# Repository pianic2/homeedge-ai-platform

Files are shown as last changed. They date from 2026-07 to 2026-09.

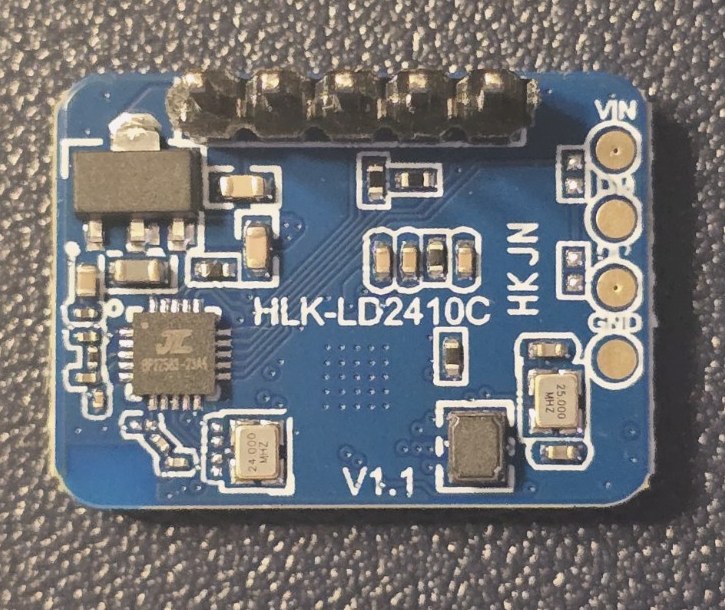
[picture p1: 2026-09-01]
docs/evidence/IHAP-46/ld2410c-v1-1-component-side.jpg

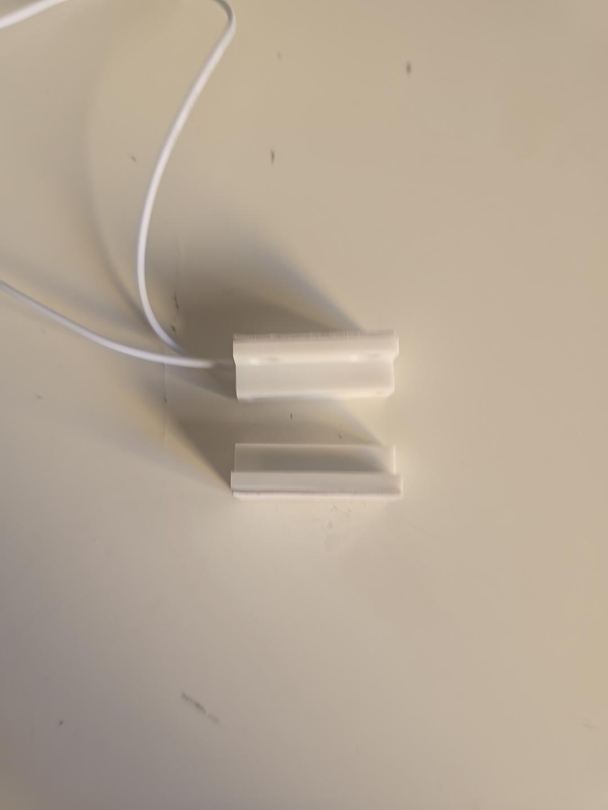
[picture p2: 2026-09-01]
docs/evidence/IHAP-47/IHAP47-MC38-A-01/photo-overview.jpg

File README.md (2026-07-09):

# HomeEdge AI Platform

**Educational edge-first smart home platform built around an ESP32-C3 MVP node, target backend service boundaries, mobile monitoring direction, and source-of-truth governance.**

HomeEdge is a portfolio and ITS project focused on building a smart home platform in a controlled, reviewable, and anti-regression way.

At Sprint 0, the repository prioritizes explicit boundaries over premature runtime claims. Directories may describe target architecture, not necessarily implemented production services.

<!--
AI_AGENT_METADATA:
  project: "[ITS] [EDGE] HomeEdge AI Platform"
  jira_project_key: "IHAP"
  repository: "pianic2/homeedge-ai-platform"
  document_role: "root_semantic_index"
  source_of_truth_policy: "docs/governance/source-of-truth.md"
  shift_left_governance_baseline: "docs/governance/shift-left-governance-baseline.md"
  scrum_governance_dor_dod: "docs/governance/scrum-governance-dor-dod.md"
  ai_review_agents_policy: "docs/governance/ai-review-agents-policy.md"
  ai_review_agent_playbook: "docs/governance/ai-review-agent-playbook.md"
  governance_lane_review_gate: "docs/governance/governance-lane-review-gate.md"
  team_working_rules: "docs/governance/team-working-rules.md"
  engineering_assistant_rules: "docs/governance/engineering-assistant-rules.md"
  documentation_strategy: "docs/governance/documentation-strategy.md"
  docs_landing_page: "docs/README.md"
  templates_index: "docs/templates/README.md"
  risk_assessment_template: "docs/templates/risk-assessment.md"
  risk_index: "docs/risks/README.md"
  risk_model_baseline: "docs/risks/risk-model-baseline.md"
  risk_records_path: "docs/risks/records/"
  adr_index: "docs/adr/README.md"
  adr_template: "docs/adr/template.md"
  product_vision: "docs/product/product-vision.md"
  stakeholder_transparency: "docs/governance/stakeholder-transparency.md"
  stakeholder_report_data_rules: "docs/governance/stakeholder-report-data-rules.md"
  current_glossary_location: "docs/product/product-vision.md"
  standalone_glossary_status: "future_candidate_not_created_by_ihap_13"
  stakeholder_hub: "https://niccolopiazzi01.atlassian.net/wiki/spaces/IEHAP/overview"
  stakeholder_reports_authoritative_surface: "Confluence"
  source_of_truth_roles:
    github: "technical truth, code, versioned docs, decisions, risks, policies, baselines, PR evidence"
    jira: "backlog, workflow state, task status, review state, blockers, evidence links"
    confluence: "stakeholder hub, stakeholder reports, stakeholder forms, navigation"
  mvp_firmware_node: "firmware/room-env-node/"
  mvp_node_semantics: "generic_room_door_node"
  mvp_includes:
    - temperature_collection
    - humidity_collection
    - local_non_identifying_presence_detection
    - door_open_closed_state
  mvp_excludes:
    - raw_audio_collection
    - individual_presence_tracking
    - behavioral_history_tracking
    - person_identification
    - window_sensor_scope
    - 220v_automation
    - esp32_direct_kafka_producer
    - commercial_claims
    - safety_critical_claims
    - production_security_grade_certification
  target_service_boundaries_unvalidated:
    - services/ingestion/
    - services/device-registry/
    - services/read-model/
    - services/ai-insight/
  unvalidated_claim_marker: "[UNVALIDATED]"

AI_AGENT_ROUTING:
  - Start here for repository semantic navigation.
  - Read docs/README.md for documentation navigation under docs/.
  - Read docs/governance/source-of-truth.md before modifying docs, governance, Jira evidence, Confluence summaries, canonical paths, or commit convention.
  - Read docs/governance/documentation-strategy.md before creating, moving, splitting, merging, deprecating, or reorganizing repository documentation.
  - Read docs/templates/README.md before creating, using, moving, or changing reusable project templates.
  - Read docs/risks/risk-model-baseline.md before changing project risk taxonomy, scoring, residual risk treatment, risk evidence, or stakeholder risk visibility.
  - Read docs/risks/README.md and docs/risks/records/ before changing concrete risk records.
  - Read docs/governance/shift-left-governance-baseline.md before planning issue-level impact blocks, review readiness, or Jira evidence.
  - Read docs/governance/scrum-governance-dor-dod.md before evaluating Definition of Ready, Definition of Done, Jira workflow movement, or minimum evidence expectations.
  - Read docs/governance/ai-review-agents-policy.md before understanding review-agent roles, severity model, and decision limits.
  - Read docs/governance/ai-review-agent-playbook.md before running concrete review-agent prompts or producing review summaries.
  - Read docs/governance/governance-lane-review-gate.md before moving governance-lane tasks toward review, stakeholder review, or Done.
  - Read docs/governance/team-working-rules.md before changing daily collaboration rules, blocker handling, evidence discipline, working agreements, or AI assistant usage boundaries.
  - Read docs/governance/engineering-assistant-rules.md before using or changing engineering assistant operating boundaries, allowed actions, forbidden actions, or assistant evidence rules.
  - Read docs/adr/README.md before adding or changing ADRs, ADR naming, ADR status, or ADR link policy.
  - Read docs/adr/template.md before drafting a new ADR.
  - Read docs/product/product-vision.md before changing MVP scope, product language, glossary terms, firmware boundaries, service boundary wording, or stakeholder claims.
  - Read docs/governance/stakeholder-transparency.md before changing stakeholder visibility, Atlassian governance, Jira evidence comments, or Confluence hub/report behavior.
  - Read docs/governance/stakeholder-report-data-rules.md before changing what stakeholder reports may show, link, redact, or block.
  - Do not infer runtime maturity from folder names.
  - Preserve [UNVALIDATED] on all unproven claims.
  - Do not introduce production-ready, safety-critical, commercial-ready, or security-grade claims without reviewed evidence.
-->

---

## Semantic Index

| Need | Canonical path / surface | Rule |
|---|---|---|
| Source-of-truth rules | `docs/governance/source-of-truth.md` | Defines GitHub/Jira/Confluence roles, DOC-REGRESSION, anti-divergence, canonical paths, commit convention, and `[UNVALIDATED]` policy. |
| Documentation strategy | `docs/governance/documentation-strategy.md` | Defines document families, when to create or update docs, anti-stale behavior, and documentation surface policy without duplicating source-of-truth rules. |
| Docs landing page | `docs/README.md` | Provides navigable documentation index for `docs/` without replacing canonical documents or duplicating long-form rules. |
| Project templates | `docs/templates/README.md` | Indexes reusable project templates and links canonical templates without duplicating their source documents. |
| Risk documentation | `docs/risks/README.md` | Indexes the risk modeling guide and concrete risk records. |
| Risk model baseline | `docs/risks/risk-model-baseline.md` | Defines how project risks are modeled, scored, linked, and reviewed. |
| Shift Left governance baseline | `docs/governance/shift-left-governance-baseline.md` | Defines the mandatory issue-level impact block for security, privacy, cost, compliance, testing, documentation, and stakeholder visibility. |
| Scrum governance, DoR and DoD | `docs/governance/scrum-governance-dor-dod.md` | Defines lightweight Scrum governance, Definition of Ready, Definition of Done, Jira workflow movement, minimum evidence expectations, and Project Owner authority. |
| AI review agents policy | `docs/governance/ai-review-agents-policy.md` | Defines Sprint 0 advisory review agents, severity model, review output template, and non-decision-making limits. |
| AI review agent playbook | `docs/governance/ai-review-agent-playbook.md` | Provides concrete copy-paste prompts and the operating flow for using review agents in Jira, GitHub, PR, and stakeholder reviews. |
| Governance lane review gate | `docs/governance/governance-lane-review-gate.md` | Defines when governance-lane tasks may advance toward review, stakeholder review, or Done without source-of-truth divergence, missing evidence, unsupported claims, or premature AI/Project Owner authority violations. |
| Team working rules | `docs/governance/team-working-rules.md` | Defines lightweight daily operating rules, collaboration boundaries, blocker handling, evidence discipline, and AI assistant usage boundaries. |
| Engineering assistant rules | `docs/governance/engineering-assistant-rules.md` | Defines engineering assistant allowed actions, forbidden actions, operating flow, evidence expectations, and Project Owner authority boundaries. |
| ADR index and template | `docs/adr/README.md`, `docs/adr/template.md` | Defines ADR index, naming convention, status model, template, and link policy. |
| Product Vision and MVP boundary | `docs/product/product-vision.md` | Canonical source for Product Vision, MVP inclusions/exclusions, and current glossary. |
| Stakeholder transparency | `docs/governance/stakeholder-transparency.md` | Defines stakeholder visibility, Jira evidence behavior, and Confluence hub usage. |
| Stakeholder report data rules | `docs/governance/stakeholder-report-data-rules.md` | Defines what stakeholder reports may show, link, redact, or block. |
| Stakeholder hub and reports | Confluence | Confluence is authoritative for stakeholder-facing hub, reports, forms, and navigation. |
| Backlog and task state | Jira | Jira is authoritative for backlog, workflow state, task status, blockers, review state, and evidence links. |
| Code and PR evidence | GitHub | GitHub is authoritative for code, repository structure, commits, branches, PRs, and versioned technical documentation. |

Operating rule:

```text
Confluence reports and orients.
Jira tracks and links evidence.
GitHub defines the technical truth.
```

If GitHub and Jira/Confluence diverge on technical content, GitHub wins until a reviewed GitHub source-of-truth change updates the project truth.

---

## Purpose

The project is designed to demonstrate a complete engineering path:

- embedded firmware for ESP32-C3 devices;
- smart home sensor integration;
- structured event collection direction;
- backend API/service-boundary design `[UNVALIDATED]`;
- mobile-first monitoring direction `[UNVALIDATED]`;
- reproducible setup;
- technical documentation and governance.

---

## Sprint 0 Repository Skeleton

This repository starts with a deliberately small and explicit skeleton. The goal is to make project boundaries visible before runtime implementation expands.

```text
homeedge-ai-platform/
├── apps/
│   └── mobile/
├── docs/
│   ├── README.md
│   ├── adr/
│   ├── architecture/
│   ├── governance/
│   ├── product/
│   ├── risks/
│   └── templates/
├── firmware/
│   └── room-env-node/
├── infrastructure/
├── schemas/
├── scripts/
├── services/
│   ├── ingestion/
│   ├── device-registry/
│   ├── read-model/
│   └── ai-insight/
└── tools/
```

### MVP boundary

The only firmware node in the MVP skeleton is:

```text
firmware/room-env-node/
```

This node is a generic room/door node.

Inside MVP:

- temperature;
- humidity;
- local non-identifying presence detection;
- door open/closed state.

Outside MVP:

- raw audio collection;
- person tracking;
- behavioral history;
- person identification;
- window sensor scope;
- 220V automation;
- direct ESP32 Kafka publishing;
- commercial claims;
- safety-critical claims;
- production/security-grade certification claims.

### Backend target topology

The backend target is represented as four service boundaries:

```text
services/ingestion/
services/device-registry/
services/read-model/
services/ai-insight/
```

These directories are **target service boundaries** `[UNVALIDATED]`, not proof that production-ready services already exist.

---

## Architecture Direction

```text
Edge Nodes -> Backend Services -> Mobile Dashboard -> AI-ready Insights
```

- **Edge Nodes:** collect room-level signals within the MVP boundary.
- **Backend Services:** target boundaries for receiving, validating, and exposing data `[UNVALIDATED]`.
- **Mobile Dashboard:** target direction for room state, latest telemetry, and device health visibility `[UNVALIDATED]`.
- **AI-ready Insights:** future target direction based on validated data `[UNVALIDATED]`.

---

## Stack Direction

| Area | Stack / direction |
|---|---|
| Firmware | ESP32-C3, ESP-IDF, C |
| Backend | Java, Spring Boot, REST APIs `[UNVALIDATED]` |
| Mobile | TypeScript, React Native, Expo `[UNVALIDATED]` |
| DevOps | Docker, GitHub Actions, Linux `[UNVALIDATED]` |
| Docs | Source-of-truth governance, Documentation Strategy, Project Templates, Risk Model Baseline, Risk Records, Shift Left governance, Scrum governance DoR/DoD, AI review agents policy, AI review agent playbook, Governance Lane Review Gate, Team Working Rules, Engineering Assistant Rules, ADR index/template, Product Vision, Risk Assessments, stakeholder transparency, stakeholder report data rules |

---

## Current Status

This repository is in Sprint 0. The current focus is repository structure, product/governance documentation, source-of-truth rules, anti-regression policy, Documentation Strategy, Project Templates, Risk Model Baseline, Risk Records, Shift Left governance baseline, Scrum governance DoR/DoD, AI review-agent policy/playbook, Governance Lane Review Gate, Team Working Rules, Engineering Assistant Rules, ADR index/template, stakeholder report data rules, and explicit MVP boundaries.

Nothing in this repository should be interpreted as production-ready, security-grade, safety-critical, or commercially ready unless a later reviewed source-of-truth document and implementation evidence prove it.

---

## Why It Matters

HomeEdge is intended to be the main technical portfolio project: it combines embedded systems, backend architecture, mobile development, DevOps basics, stakeholder transparency, and project governance in one coherent platform.

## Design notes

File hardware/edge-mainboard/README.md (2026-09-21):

# HomeEdge Edge Mainboard — IHAP-55

**EDA baseline:** KiCad 10.0.6 stable  
**Status:** revision-A native capture under validation; ERC has one unresolved warning and DRC has unresolved schematic-parity/footprint mapping findings

This directory is the canonical PCB source workspace for IHAP-55.

Planned source set:

```text
hardware/edge-mainboard/
  homeedge-edge-mainboard.kicad_pro
  homeedge-edge-mainboard.kicad_sch
  homeedge-edge-mainboard.kicad_pcb
  libraries/
  fabrication/        # generated only after DRC/DFM and Project Owner fabrication gate
```

## Current design gates

The native schematic and preliminary PCB now exist and load in KiCad. The 2026-09-12 manufacturer review still blocks electrical freeze because direct 47 kOhm board-health dividers can violate the TLA2024 AIN limit while SYS_3V3 is off. Power-path protection, reverse-cell prevention and NTC implementation also remain incomplete. Current ERC/DRC results and remaining parity findings are recorded in `docs/evidence/IHAP-55/erc-report.txt`, `drc-report.txt`, and `pcb-preliminary-review.md`; neither gate is a PASS.

Current architecture candidate is documented in:

- `docs/architecture/ihap-55-mainboard-architecture.md`
- `docs/evidence/IHAP-55/source-register.md`

Before first schematic freeze:

1. complete MP2636 + post-regulator electrical calculations;
2. complete 3.3 V regulator calculations;
3. freeze USB-C CC/data/protection implementation;
4. verify ESP32-C3-MINI-1-N4X pin availability against the Accepted IHAP-50 map;
5. retain DNP I2C/DHT pull-up footprints and measure/identify actual module-side pull-ups before final population; this measurement does not block independent design work;
6. separate Accepted power requirements from Proposed IHAP-56 controls;
7. retain all exact MPN and footprint evidence in the IHAP-55 source register.

## Governance

- one task = one branch = one PR;
- branch: `ihap-55-integrated-modular-edge-pcb`;
- no fabrication/procurement without explicit Project Owner authorization;
- generated Gerber/drill/fabrication files are not evidence of physical correctness;
- final board behavior remains `[UNVALIDATED]` until bring-up and physical validation;
- no audio circuitry, connector or allocation is permitted in the reference MVP.

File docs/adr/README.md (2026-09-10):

# Architecture Decision Records

**Issue:** IHAP-22 — S0-013 — ADR Index and ADR Template  
**Project:** [ITS] [EDGE] HomeEdge AI Platform  
**Document type:** ADR index  
**Source of truth:** This versioned GitHub document is the canonical ADR index for HomeEdge AI Platform until superseded by a later reviewed change.

<!--
AI_AGENT_METADATA:
  issue: IHAP-22
  document_type: adr_index
  canonical_path: docs/adr/README.md
  adr_template: docs/adr/template.md
  source_of_truth_policy: docs/governance/source-of-truth.md
  approval_authority: project_owner
  jira_role: evidence_links_only
  confluence_role: stakeholder_navigation_only
  unvalidated_claim_marker: "[UNVALIDATED]"

HIDDEN_ANTI_REGRESSION_RULES:
  - ADR content lives in GitHub.
  - Jira tracks ADR work state and evidence links only.
  - Confluence may summarize or link ADRs for stakeholder navigation, but must not duplicate long-form ADR content.
  - ADR status changes to Accepted, Rejected or Superseded require Project Owner approval.
  - A later amendment inside an Accepted ADR remains Proposed until a new explicit Project Owner decision exists.
  - Do not create ADRs only to increase document count.
  - Preserve [UNVALIDATED] on unproven claims.
  - Do not introduce production-ready, safety-critical, commercial-ready, certification or security-grade claims.
-->

---

## 1. Purpose

This folder contains Architecture Decision Records for HomeEdge AI Platform.

ADRs record reviewed architectural decisions, their context, alternatives, consequences, risks, follow-up work and evidence links. They do not approve themselves: acceptance requires Project Owner approval.

---

## 2. Source-of-Truth Rule

```text
GitHub stores ADR content.
Jira tracks work state and links evidence.
Confluence summarizes and links only.
```

---

## 3. ADR Naming Convention

```text
ADR-0001-short-kebab-title.md
ADR-0002-short-kebab-title.md
```

Rules:

- four-digit sequential number;
- lowercase kebab-case title;
- one decision per ADR;
- no renumbering after merge;
- superseded ADRs stay in the index.

---

## 4. ADR Status Model

| Status | Meaning |
|---|---|
| `Proposed` | Draft decision under review. Not accepted yet. |
| `Accepted` | Decision accepted by the Project Owner and linked to evidence. |
| `Superseded` | Replaced by a later ADR. Keep the historical record. |
| `Rejected` | Considered and explicitly rejected. Keep the rationale. |

Only the Project Owner can accept, reject or supersede an ADR. If an Accepted ADR contains a later amendment proposal, the ADR must clearly preserve the Accepted baseline and mark the amendment **Proposed** until a new Project Owner decision exists.

---

## 5. Link Policy

Every ADR should link Jira work, PR evidence, related ADRs when relevant, and evidence for validated claims. Confluence is optional navigation only. Unproven claims keep `[UNVALIDATED]`.

---

## 6. ADR Index

| ADR | Title | Status | Jira | PR | Notes |
|---|---|---|---|---|---|
| [ADR-0001](ADR-0001-mvp-edge-compute-platform.md) | MVP Edge Compute Platform | Accepted | [IHAP-44](https://niccolopiazzi01.atlassian.net/browse/IHAP-44) | [PR #23](https://github.com/pianic2/homeedge-ai-platform/pull/23) | Accepts ESP32-C3 as the MVP family, the purchased SuperMini-compatible board as preferred conditional implementation and ESP32-C3-DevKitC-02 as official control/fallback. Exact commercial SKU reproducibility and quantitative power remain `[UNVALIDATED]`; accepted ADR-0007 baseline transfers final-node quantitative power execution to IHAP-55. |
| [ADR-0002](ADR-0002-environmental-sensor-profiles.md) | Environmental Sensor Profiles | Accepted | [IHAP-45](https://niccolopiazzi01.atlassian.net/browse/IHAP-45) | [PR #29](https://github.com/pianic2/homeedge-ai-platform/pull/29) | Selects DHT11 as the standard indoor profile and BME280 as the precision/extended-environment profile. DHT22 is not selected. Absolute accuracy remains `[UNVALIDATED]`; pressure remains outside the MVP measurement contract. Accepted ADR-0007 baseline transfers quantitative integrated-node power execution to IHAP-55. |
| [ADR-0003](ADR-0003-mvp-door-state-sensor.md) | MVP Door State Sensor | **Accepted** | [IHAP-47](https://niccolopiazzi01.atlassian.net/browse/IHAP-47) | [PR #26](https://github.com/pianic2/homeedge-ai-platform/pull/26) | Accepted 2026-09-01. Passive wired two-conductor magnetic reed-contact technology for binary door-state telemetry; `MC38-A` is the tested local specimen. Open contact and interrupted conductor remain electrically indistinguishable. **IHAP-56 proposes** transferring quantitative pull-network/product-power execution to IHAP-55, but that extension is not part of the 2026-09-07 ADR-0007 acceptance until explicitly approved or reassigned by another accepted decision. |
| [ADR-0004](ADR-0004-local-status-display.md) | Local Status Display | **Accepted** | [IHAP-53](https://niccolopiazzi01.atlassian.net/browse/IHAP-53) | [PR #31](https://github.com/pianic2/homeedge-ai-platform/pull/31) | Accepted 2026-08-31. Reference MVP includes a 0.96-inch-class 128×64 monochrome I2C local status/debug display; exact controller/provenance/power/replacement reproducibility remain bounded by evidence. Accepted ADR-0007 baseline transfers display-current and resulting sleep/power-policy execution to IHAP-55. |
| [ADR-0005](ADR-0005-mvp-presence-sensor.md) | MVP Presence Sensor | **Accepted** | [IHAP-46](https://niccolopiazzi01.atlassian.net/browse/IHAP-46) | [PR #25](https://github.com/pianic2/homeedge-ai-platform/pull/25), [PR #33](https://github.com/pianic2/homeedge-ai-platform/pull/33) | Accepted 2026-09-01. Selects HLK-LD2410C-class radar for local boolean presence only; onset/release and replacement-equivalence limitations remain explicit. Accepted ADR-0007 baseline transfers quantitative final-node radar/power execution to IHAP-55. |
| [ADR-0006](ADR-0006-mvp-central-node-hardware-profile.md) | MVP Central Node Hardware Profile | **Accepted** | [IHAP-52](https://niccolopiazzi01.atlassian.net/browse/IHAP-52) | [PR #30](https://github.com/pianic2/homeedge-ai-platform/pull/30) | Accepted 2026-09-05. Vendor-neutral 64-bit Linux profile; Raspberry Pi 4 Model B >=4 GB is the reference implementation. The validated specimen uses 8 GB RAM, nominal 32 GB A1 microSD, Raspberry Pi OS Lite 64-bit, 5.1 V / 3 A PSU and case + heatsink + fan. Final workload sufficiency, storage endurance/retention and AI acceleration remain `[UNVALIDATED]`. |
| [ADR-0007](ADR-0007-edge-power-subsystem.md) | Edge Power Subsystem | **Accepted baseline; Proposed IHAP-56 amendment** | [IHAP-49](https://niccolopiazzi01.atlassian.net/browse/IHAP-49), remediation [IHAP-56](https://niccolopiazzi01.atlassian.net/browse/IHAP-56) | [PR #34](https://github.com/pianic2/homeedge-ai-platform/pull/34), remediation [PR #35](https://github.com/pianic2/homeedge-ai-platform/pull/35) | Accepted 2026-09-07 baseline: regulated 5 V USB-C normal source, LG INR18650-MJ1 1S backup, MP2636GR-P-class first direction plus downstream regulated 5 V stage/reviewed equivalent, **>=0.5 A continuous across accepted battery/valid USB-input ranges**, reverse-insertion prevention, NTC monitoring and downstream physical validation. IHAP-56 later proposes source-side over-current/upstream-segment treatment, mandatory NTC fault tests, numeric thermal/junction and low-voltage criteria, measurable backfeed/3.3 V criteria, stronger V7/V8/V9/V13/V14/V15 tests and ADR-0003 ownership transfer. Those additions remain **Proposed** until explicit Project Owner approval. R-012/R-013 remain Pending Evidence; no-reset transfer and autonomy remain `[UNVALIDATED]`. |

---

## 7. Practical Rule

```text
Create ADRs because a decision needs traceability.
Do not create ADRs to increase document count.
```

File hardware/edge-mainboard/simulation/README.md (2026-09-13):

# IHAP-55 simulation strategy

The board uses three complementary validation layers.

## 1 — deterministic corner screening

```bash
python3 tools/hardware-validation/ihap-55-mainboard/host/ihap55_contract_check.py
python3 tools/hardware-validation/ihap-55-mainboard/host/ihap55_sim.py
python3 -m unittest discover -s tools/hardware-validation/ihap-55-mainboard/host/tests -v
```

This checks preserved contracts, feedback networks, source/load corners and Accepted steady rail bounds. It deliberately does not pretend to model switching waveforms.

## 2 — vendor switching models

TI publishes the `TPS63802 Unencrypted PSpice Transient Model Package (Rev. C)` (`SLVMCX1C.ZIP`) and the `TLV62568 PSpice Unencrypted Transient Model (Rev. B)` (`SLVMBV4B.ZIP`). KiCad uses ngspice and can load external unencrypted PSpice subcircuits.

Target TPS63802 runs: startup at MP_SYS min/nominal/max; 0.1->0.5 A step; 0.1->1.0 A headroom step; buck/buck-boost/boost transition; undershoot/overshoot/recovery.

Target TLV62568 runs: 5 V startup; 50->250 mA and 50->500 mA steps; tolerance corners; undershoot/overshoot.

Vendor files are not redistributed in this repository. Put locally downloaded files under `simulation/vendor-models/` and bind them to the corresponding KiCad symbols.

The exact TI package URLs, SHA-256 checksums and internal `.LIB` paths are pinned in `vendor-model-manifest.json`. Run `python3 fetch_vendor_models.py` to download and verify them into `vendor-models/`. From this directory, with ngspice 44.2 and PSpice compatibility enabled by `.spiceinit`, run:

```bash
ngspice -b -o tps63802-startup-step.log tps63802-startup-step.cir
ngspice -b -o tlv62568-startup-step.log tlv62568-startup-step.cir
```

The transient netlists are vendor-model experiments, not complete power-path simulation. A process exit alone is not a PASS: inspect measured rail values against the circuit's expected steady and transient envelopes. A package-extracted ngspice also needs its matching XSPICE code-model libraries loaded; the normal Debian installation does this from `spinit`.

The 2026-09-12 ngspice 44.2 experiments did **not** qualify either regulator model: TPS63802 returned a negative output with exit 0, TLV62568 returned a negative output with exit 0 in the initial run and the startup retry did not finish in a practical time. See `docs/evidence/IHAP-55/simulation-summary.md`. Treat these netlists as diagnostic starting points until a supported model integration produces plausible measured waveforms.

## 3 — MP2636/full-system

MPS documents MPSmart as its SIMetrix/SIMPLIS environment and states that most MPS IC models are SIMPLIS models. Use an exact MP2636 model there if exposed by the installed MPS model library. Otherwise the repository retains a bounded system behavioral model plus mandatory physical validation rather than inventing a switching model.

Physical V1–V12 validation from the IHAP-49 plan remains mandatory after fabrication.

## Evidence boundary

Simulation validates the modeled circuit, not assembly, real parasitics, connector polarity, battery safety, RF, actual thermal behavior or transfer performance. Those remain `[UNVALIDATED]` until measured.

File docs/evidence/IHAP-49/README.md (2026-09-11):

# IHAP-49 — Edge Power Subsystem Decision Evidence

**Status:** Accepted PR #34 decision package + **Proposed IHAP-56 remediation overlay**; PR #35 merged, Proposed controls remain unapproved unless separately accepted.

This directory contains the evidence package for IHAP-49. The accepted architecture uses regulated 5 V USB-C as the normal node supply and a rechargeable single-cell Li-ion path only as backup for blackout or cable/input interruption.

## Current lifecycle — reconciled 2026-09-11

- IHAP-49: **Completata**.
- ADR-0007 / PR #34 baseline: **Accepted**.
- IHAP-56: **Completata**.
- PR #35: **merged 2026-09-10** as `629ff78965a20481cf68954d6bcb8ac865fc27c2`.
- IHAP-55: **In corso** from 2026-09-11.
- RT-R012-01 / RT-R013-01: **Proposed**, not Approved/Implemented/Verified.

See `ihap-56-post-merge-reconciliation.md` for the narrow supersession of stale pre-merge workflow statements. That reconciliation does not alter technical Accepted/Proposed boundaries.

## Accepted Project Owner direction — 2026-09-07

- Normal operating source: regulated 5 V via USB-C.
- Battery role: backup only, for blackout or cable/input failure.
- Battery is not the normal continuous energy source.
- Multi-day standalone operation is not an MVP requirement.
- Selected reference cell: **LG INR18650-MJ1**, EAN/GTIN `8438493099829`, flat-top unprotected 18650 Li-ion.
- Final hardware direction: **one small, efficient, installable, modular custom core PCB**.
- Preferred first integrated power PMIC direction: **MPS MP2636GR-P** plus downstream regulated 5 V stage or reviewed equivalent topology.
- Existing 18650 holder remains the mechanical candidate; no replacement-holder purchase at this decision stage.
- Owned 4056E breakout is bench/control evidence only and is rejected as the final implementation.
- Redundant TPS61023/TPS2116/charger/boost/mux breakouts are not required solely to emulate the final custom PCB.

## Accepted electrical baseline

- USB-C normal input: 5 V, no PD requirement; correct Type-C sink termination and C-to-C 5 V operation required. V2 covers **both DUT plug orientations**.
- Reference source: 5 V with at least 1.5 A available/advertised; system-load-priority input limiting required.
- Product SYS: 5.0 V regulated, 4.75–5.25 V steady-state validation band, **>=0.5 A continuous across the accepted battery range and valid USB-input range**, >=1.0 A transient/headroom target.
- Battery CV target 4.2 V; nominal charge current approximately 1.0 A.
- NTC monitoring required.
- USB priority + automatic battery takeover; upstream USB backfeed prohibited.
- No-reset transfer remains the target and `[UNVALIDATED]`.
- Reverse insertion requires electrical blocking/protection or mechanical keying; procedure alone is not acceptable.
- Accepted quantitative ownership transfer covers ADR-0001/0002/0004/0005.

## Proposed IHAP-56 remediation overlay — pending explicit Project Owner approval

- RT-R012-01 source-side over-current interruption ahead of every service conductor claimed as protected; any segment before it remains explicit residual exposure until separately controlled/verified;
- mandatory NTC normal/hot/cold/open/short verification;
- manufacturer-derived thermal limits + justified MP2636 junction-temperature/derating method;
- worst-case ILIM <=1.50 A + V14;
- component-derived 3.3 V steady/transient criteria;
- bidirectional V7 with <=100 µs edges;
- high/mid/valid-low V8/V9 with loaded cutoff margin, quantified backfeed and zero-reset restoration criterion;
- numeric V10 cutoff/recovery;
- V13 installed/production-identical path verification;
- V15-A/V15-B with USB absent/present;
- ADR-0003/reed-current ownership extension.

RT-R012-01 and RT-R013-01 remain **Proposed**, not Approved/Implemented/Verified. ADR-0007 acceptance partially mitigates the associated risks at architecture-baseline level but does not approve later treatment detail or residual risk.

## Evidence / review routing

- `ihap-56-post-merge-reconciliation.md` — current workflow/lifecycle reconciliation.
- `ihap-56-closure-matrix.md` — Accepted-vs-Proposed review matrix.
- `validation-plan.md` — accepted baseline + Proposed verification overlay.
- `downstream-contracts.md` — accepted IHAP-55 obligations vs Proposed gates.
- `custom-pcb-power-contract.md` — detailed electrical boundary.
- R-012 / R-013 — canonical treatment dossiers.

IHAP-50 owns the Accepted connection matrix. IHAP-55 now implements the custom-board work while preserving the Accepted/Proposed split. IHAP-51 provides the mechanical feedback loop before final layout freeze. IHAP-57 owns later treatment lifecycle/effectiveness after explicit approval and physical evidence.

## Planning / claim boundary

Planning backup runtime remains approximately 12–20 h with ~16 h central estimate under the current model, but autonomy remains `[UNVALIDATED]` until measured. Neither Accepted nor Proposed documentation establishes safety, certification, production readiness, validated no-reset transfer or measured autonomy. No procurement or fabrication is authorized by this lifecycle reconciliation.

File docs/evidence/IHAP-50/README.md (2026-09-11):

# IHAP-50 — Interconnect Evidence

**Issue:** IHAP-50  
**Status:** **ACCEPTED by Project Owner — 2026-09-11**; physical gates complete; PR #36 awaiting Codex review before merge  
**Branch:** `ihap-50-interconnect-prototype-assembly`  
**PR:** #36

## Purpose

This evidence index records the accepted source inputs, review findings, remediations, physical evidence and Project Owner acceptance for the IHAP-50 prototype interconnect baseline. It does **not** claim that the final custom PCB, power subsystem, enclosure integration or production node has been physically validated.

## Canonical outputs

- [`docs/architecture/ihap-50-interconnect-prototype-assembly.md`](../../architecture/ihap-50-interconnect-prototype-assembly.md)
- [`docs/architecture/ihap-50-connection-matrix.json`](../../architecture/ihap-50-connection-matrix.json)
- [`tools/hardware-validation/ihap-50-interconnect/README.md`](../../../tools/hardware-validation/ihap-50-interconnect/README.md)
- [`IHAP50-STANDARD-11-summary.md`](IHAP50-STANDARD-11-summary.md) / [`json`](IHAP50-STANDARD-11-summary.json)
- [`IHAP50-PRECISION-01-summary.md`](IHAP50-PRECISION-01-summary.md) / [`json`](IHAP50-PRECISION-01-summary.json)

Raw serial captures remain local under ignored `runs/` directories and are not committed by default.

## Accepted source inputs

| Input | State consumed | IHAP-50 use |
|---|---|---|
| ADR-0001 — MVP Edge Compute Platform | Accepted | ESP32-C3 GPIO/recovery baseline and spare ADC-capable requirement |
| ADR-0002 — Environmental Sensor Profiles | Accepted | alternative DHT11 / BME280 profile interfaces |
| ADR-0003 — MVP Door State Sensor | Accepted | reed-contact topology and semantic limitation |
| ADR-0004 — Local Status Display | Accepted | 3.3 V I2C OLED and BME280 bus-sharing direction |
| ADR-0005 — MVP Presence Sensor | Accepted | LD2410C 5 V/UART receive direction and boolean-only boundary |
| IHAP-48 audio disposition | Accepted closure | zero audio interconnect allocation |
| ADR-0007 — Edge Power Subsystem | Accepted | SYS_5V/SYS_3V3 domains and custom-PCB direction |
| IHAP-56 / PR #35 | merged remediation | Accepted-vs-Proposed separation; strengthened controls remain Proposed unless separately accepted |

## Accepted IHAP-50 contract

The Project Owner explicitly approved IHAP-50 on **2026-09-11** after successful STANDARD and PRECISION physical gates and final regression review. The following are therefore Accepted IHAP-50 implementation decisions:

- canonical GPIO/net allocation below;
- breadboard and loose Dupont as validation/development-only;
- keyed/polarized low-voltage connector classes as the final-reference direction while exact manufacturer series/SKU/footprint remains IHAP-55 scope;
- MC-38 reference network: 10 kOhm pull-up to `SYS_3V3` + 1 kOhm series resistor to GPIO3, with 100 nF filter footprint DNP by default;
- I2C/DHT board pull-up **footprint requirements and target/candidate values**, while exact final population remains IHAP-55 `[UNVALIDATED]` scope after effective module pull-ups are reconciled;
- STANDARD and PRECISION as alternative environmental profiles;
- ADR disposition: **no new ADR required**.

Acceptance does **not** promote controls that remain explicitly Proposed under IHAP-56.

## Canonical GPIO contract

```text
GPIO0  RADAR_RX_FROM_LD2410C_TX       UART1 RX @ 256000
GPIO1  RADAR_TX_TO_LD2410C_RX         SERVICE-ONLY reservation; disabled by default
GPIO3  DOOR_SENSE
GPIO4  ENV_DHT_DATA
GPIO5  SPARE_ADC_CAPABLE               ADC2_CH0
GPIO6  I2C_SDA
GPIO7  I2C_SCL
GPIO10 SPARE_DIGITAL
```

GPIO2/GPIO8/GPIO9 remain excluded as strapping pins. GPIO20/GPIO21 remain free for recovery/UART0 when practical. Audio receives zero allocation.

## Review/remediation history

### SR-50-01 — incorrect ADC capability — REMEDIATED

The initial draft incorrectly labelled GPIO10 as ADC-capable. The mapping was corrected so GPIO5 provides the required ADC-capable spare and GPIO10 remains digital-only. Human and machine-readable contracts were reconciled before physical validation.

### SR-50-02 — validation UART TX exceeded receive-only baseline — REMEDIATED

The initial harness attached GPIO1 as UART TX even though the accepted LD2410C baseline is receive-only. The harness now configures only GPIO0 RX, leaves GPIO1 as a physical/service reservation and emits `radar_tx_service_configured=false`; the evaluator fails if that contract regresses.

### SR-50-03 — ESP32-C3 target / USB console configuration — REMEDIATED

A physical flash attempt exposed a harness configuration defect: the build invoked `esptool --chip esp32` while the ROM bootloader correctly identified the board as ESP32-C3. Comparison with accepted IHAP-46/IHAP-47 harnesses also showed that IHAP-50 had not pinned the USB Serial/JTAG console used by the collector.

Remediation added `firmware/sdkconfig.defaults` with the ESP32-C3 target and USB Serial/JTAG console configuration. A 3.5 s native-USB re-enumeration guard is retained as defensive validation tooling. The board/ROM USB path was demonstrated healthy during recovery; no hardware failure was inferred from the aborted pre-remediation attempts.

### SR-50-04 — stale serial samples crossed operator phase boundaries — REMEDIATED

The first guided runner could attribute `integrated_sample` records queued while an operator changed the MC-38 condition to the next phase. The runner now:

- aborts immediately on requested/detected profile mismatch;
- clears queued serial input after each operator-confirmed acquisition boundary;
- records only fresh post-confirmation samples;
- displays sequence numbers to make temporal progression visible.

No sensor semantics or thresholds were weakened to obtain PASS.

## Accepted physical evidence

### IHAP50-STANDARD-11 — PASS

Commit under test: `6e1200afe15492c283edc6afd39059b2947b7fae`.

Validated:

- detected STANDARD profile; BME280 absent as required;
- exact canonical pin map;
- GPIO5 ADC-spare and GPIO10 digital-spare pull tests PASS;
- GPIO1 service TX disabled;
- OLED communication stable plus visual startup confirmation;
- DHT11 valid throughout baseline;
- LD2410C fresh with valid frames and zero parsed invalid frames;
- MC-38 OPEN/FAR = `1,1`;
- MC-38 CLOSED/NEAR = `0,0`;
- one MC-38 conductor disconnected = `1,1`;
- OLED and radar remained alive through all door phases;
- evaluator errors: none.

The accepted phase samples were temporally separated by the SR-50-04 acquisition boundaries: OPEN seq 8/9, CLOSED seq 14/15, DISCONNECTED seq 17/18.

### IHAP50-PRECISION-01 — PASS

Commit under test: `6e1200afe15492c283edc6afd39059b2947b7fae`.

Validated:

- detected PRECISION profile;
- BME280 present on shared I2C at `0x76` with identity `0x60`;
- BME280 communication successful across all six accepted baseline samples;
- DHT11 absent (`NO_RESPONSE`) as required by the alternative profile setup;
- OLED remained operational on the shared GPIO6/GPIO7 bus;
- LD2410C remained fresh with valid frames and zero parsed invalid frames;
- exact pin map, spare-pin checks and disabled radar service TX remained valid;
- evaluator errors: none.

Door phases were intentionally not duplicated because STANDARD-11 already supplied accepted MC-38 evidence.

## No-regression review

After remediation, physical execution and PO acceptance:

1. no strapping pin is allocated;
2. GPIO20/GPIO21 remain available for recovery/UART0 when practical;
3. GPIO5 preserves a real ADC-capable spare;
4. GPIO10 preserves digital margin;
5. radar receive UART does not collide with shared I2C;
6. GPIO1 remains service-only and undriven by the validation firmware;
7. OLED and BME280 coexist on I2C without address collision in PRECISION;
8. DHT11 and BME280 remain alternative accepted profiles, not a simultaneous product requirement;
9. MC-38 HIGH/open, LOW/closed and broken-conductor-as-HIGH behavior is physically demonstrated for the **Accepted IHAP-50 reference network**;
10. breadboard and loose Dupont wiring remain validation-only;
11. generic `PH2.0` remains prototype inventory; exact connector manufacturer/series/footprint belongs to IHAP-55;
12. audio remains zero-allocation;
13. controls explicitly remaining Proposed in IHAP-56 remain **Proposed**; IHAP-50 approval does not promote them;
14. branch changes remain confined to IHAP-50 specification, machine-readable matrix, evidence and validation tooling.

## Downstream handoff

The Accepted IHAP-50 contract is sufficient to hand the canonical connection matrix and validated prototype interconnect behavior to:

- **IHAP-55:** schematic/PCB implementation, exact connector/footprint freeze, effective I2C/DHT pull-up population, quantitative rail/load-step/source-transfer/thermal evidence;
- **IHAP-51:** enclosure routing, connector access, harness lengths, keepouts and strain relief;
- **IHAP-17:** final BOM quantities/costs once IHAP-55 freezes exact parts.

## ADR disposition

**Accepted: no new ADR is required for IHAP-50.** The task derives implementation/interconnect details from already Accepted architecture decisions and does not introduce a new cross-cutting architecture choice. The implementation contract and evidence remain in the architecture specification, connection matrix and this evidence index.

## Merge gate

Project Owner acceptance is complete. PR #36 must **not be merged until Codex review has been received and resolved**. Any Codex finding is remediated on this same IHAP-50 branch/PR under the one-task/one-branch/one-PR rule; acceptance is rechecked if a remediation changes the Accepted contract.

## Claim boundary

IHAP-50 evidence supports an **Accepted, physically validated prototype interconnect baseline for the tested STANDARD and PRECISION profiles**. It does not validate the final custom PCB, exact production connector SKU, final enclosure harness lengths, battery/power behavior, certification, production reliability or commercial readiness. Those remain owned by their downstream gates and are `[UNVALIDATED]` here.

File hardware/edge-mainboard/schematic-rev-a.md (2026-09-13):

# IHAP-55 — Mainboard schematic revision A

**Date:** 2026-09-12  
**State:** engineering schematic contract — not fabrication-frozen  
**Machine-readable companion:** `schematic-contract.json`

Values marked `TBD` or `[UNVALIDATED]` must not be silently replaced during KiCad capture.

## A — USB-C and native USB

- `J1 = USB4105-GF-A`; VBUS pins -> `VBUS_IN`.
- CC1 -> 5.1 kOhm 1% -> GND; CC2 -> 5.1 kOhm 1% -> GND.
- D-/D+ -> `USBLC6-2SC6` -> optional 22/33 Ohm series footprints -> ESP32-C3 GPIO18/GPIO19.
- `VBUS_IN` -> input protection `[TBD exact MPN]` -> MP2636 IN.
- 5 V Type-C sink only; no PD.

## B — MP2636 charger / power path / battery

`U3 = MP2636GR-P`.

Candidate values derived from manufacturer equations:

- `RS1=20 mOhm`, `RISET=120 kOhm` -> nominal 1.0 A charge target;
- VB HIGH -> 4.2 V cell charge target;
- battery-mode boost feedback: 33.2 kOhm / 10.0 kOhm with 1.2 V reference -> `MP_SYS=5.184 V` nominal;
- SYS capacitance design target >=44 uF effective; VCC bypass 100 nF;
- NTC path present, exact thermistor/divider `[UNVALIDATED]`;
- input-current-limit population remains open until Accepted/Proposed boundary resolution;
- TP BATT and MP_SYS.

MP2636 pass-through is never called product `SYS_5V`.

## C — regulated 5 V

`U4 = TPS63802DLAR`: VIN=MP_SYS, VOUT=SYS_5V.

- L=0.47 uH, saturation-current class >= manufacturer 5.4 A reference class;
- CIN=10 uF; COUT=2x22 uF for VOUT >3.6 V;
- feedback 900 kOhm / 100 kOhm, 0.1%; nominal 5.000 V;
- FB ±1% + resistor ±0.1% divider-only corner: approximately 4.941..5.059 V before line/load/transient effects;
- TP SYS_5V.

## D — regulated 3.3 V

`U5 = TLV62568DBVR`: VIN=SYS_5V, VOUT=SYS_3V3.

- L=2.2 uH, CIN=4.7 uF, COUT=22 uF;
- feedback 453 kOhm / 100 kOhm, 0.1%; feed-forward 6.8 pF;
- nominal 3.318 V;
- published FB 0.588..0.612 V + resistor ±0.1% divider-only corner: approximately 3.246..3.390 V;
- TP SYS_3V3.

## E — ESP32-C3 and service

`U1 = ESP32-C3-MINI-1-N4X`.

- GPIO18 USB D-, GPIO19 USB D+; EN reset network; GPIO9 BOOT only;
- GPIO20/21 recovery/service pads where practical;
- GPIO0 radar RX; GPIO1 radar service TX reservation disabled by firmware default;
- GPIO3 door; GPIO4 DHT; GPIO5 ADC spare; GPIO6 SDA; GPIO7 SCL; GPIO10 spare digital;
- GPIO2/8/9 never application GPIO.

## F — external interfaces

- `J_RADAR`: GND, SYS_5V, RADAR_RX, RADAR_SERVICE_TX.
- `J_OLED`: GND, SYS_3V3, SCL, SDA.
- `J_ENV`: GND, SYS_3V3, DHT_DATA, SCL, SDA.
- `J_DOOR`: GND, DOOR_SENSE.
- `J_BATT`: BATT+, GND; reverse-cell prevention remains mandatory open design work.

Door network: 10 kOhm pull-up + 1 kOhm series + optional 100 nF DNP. I2C/DHT board pull-up footprints stay DNP until real modules are measured.

## G — programmatic board health

`U6 = TLA2024IRUGT`, supplied by SYS_3V3, ADDR=GND -> I2C `0x48`.

Four 47 kOhm / 47 kOhm 1:2 monitor dividers:

- AIN0 VBUS_IN;
- AIN1 BATT;
- AIN2 SYS_5V;
- AIN3 SYS_3V3.

**2026-09-12 design review:** this passive-only network is not safe to freeze: with VBUS/BATT present and TLA2024 VDD absent, an AIN can exceed the datasheet's VDD+0.3 V absolute limit. Add and verify supply-off isolation/protection before KiCad capture; update divider scaling if the topology changes. See `docs/evidence/IHAP-55/power-calculations.md`.

Firmware reports these rails over native USB during `self_test`. This is diagnostic evidence, not a replacement for calibrated DMM/oscilloscope tests.

## Required pre-layout gates

1. freeze exact VBUS protection and reverse-cell prevention;
2. finish NTC/input-current-limit implementation;
3. measure OLED/BME280/DHT11 pull-ups;
4. run deterministic corner simulation and vendor-model simulations;
5. capture contract into KiCad and run ERC;
6. freeze preliminary board envelope and hand it to IHAP-51 before final layout freeze.

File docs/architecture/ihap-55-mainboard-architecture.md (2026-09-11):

# IHAP-55 — Integrated Modular Edge PCB — Mainboard Architecture

**Status:** IN PROGRESS — architecture candidate for Project Owner review  
**Issue:** IHAP-55  
**Started:** 2026-09-11  
**Technical SoT branch:** `ihap-55-integrated-modular-edge-pcb`  
**Baseline main:** `30e43c3c470b35b80ac513b7691b4d04ed6340ed`

## 1. Scope and approval boundary

This document begins concrete PCB implementation from the Accepted upstream contracts. It does not approve a new ADR, promote IHAP-56 Proposed controls, authorize procurement/fabrication, or declare a final reference implementation.

The Project Owner review gate remains open for the final core/module partition and any architecture supersession. Components below marked **CANDIDATE** are design selections being developed for review, not procurement authorization.

## 2. Preserved Accepted contracts

The design shall preserve:

- ESP32-C3 compute family;
- GPIO0 `RADAR_RX_FROM_LD2410C_TX` at 256000 baud;
- GPIO1 `RADAR_TX_TO_LD2410C_RX_SERVICE_ONLY`, disabled by default;
- GPIO3 `DOOR_SENSE`;
- GPIO4 `ENV_DHT_DATA`;
- GPIO5 `SPARE_ADC_CAPABLE` / ADC2_CH0;
- GPIO6 `I2C_SDA`;
- GPIO7 `I2C_SCL`;
- GPIO10 `SPARE_DIGITAL`;
- GPIO2/GPIO8/GPIO9 outside reference application allocation;
- GPIO20/GPIO21 available for UART0/recovery when practical;
- DHT11 STANDARD and BME280 PRECISION as alternative profiles;
- OLED 0.96-inch-class 128x64 monochrome I2C at 3.3 V, reference `0x3C`;
- LD2410C at 5 V with receive path at 256000 baud and boolean-only product presence boundary;
- MC-38 topology: 10 kOhm pull-up, 1 kOhm series, optional 100 nF DNP;
- audio: zero GPIO, zero ADC, zero connector, zero power allocation;
- ADR-0007 Accepted power architecture only;
- RT-R012-01 and RT-R013-01 remain Proposed.

## 3. Architecture block diagram — revision A candidate

```text
                      USB-C 5 V INPUT
                    + USB 2.0 D+/D-
                            |
             +--------------+--------------+
             |                             |
       CC sink network                 USB ESD
       + input protection                  |
             |                        ESP32-C3 USB
             v                        Serial/JTAG
      MP2636GR-P CANDIDATE                  |
 charger / power path / boost               |
      |                    |                |
      |                    +---- BATT / NTC |
      |                                  +--+-------------------+
      v                                  | ESP32-C3-MINI-1-N4X |
 intermediate SYS                         | CANDIDATE MODULE     |
      |                                  +--+-------------------+
      v                                     |
 TPS63802DLAR CANDIDATE                      + GPIO0 -> radar RX
 buck-boost post-regulator                   + GPIO1 -> radar service TX
      |                                      + GPIO3 -> door
      +---- regulated SYS_5V                 + GPIO4 -> DHT
      |         |                            + GPIO5 -> ADC spare
      |         +---- J_RADAR                + GPIO6/7 -> I2C
      |                                      + GPIO10 -> digital spare
      v
 TLV62568DBVR CANDIDATE
 3.3 V buck regulator
      |
      +---- regulated SYS_3V3
            +---- ESP32-C3 module
            +---- J_OLED
            +---- J_ENV
            +---- MC-38 pull network
```

The power converter choices are not yet electrically frozen. They must pass complete input/output/current/tolerance/thermal calculations before schematic freeze.

## 4. ESP32-C3 implementation decision candidate

### 4.1 Preferred candidate

**ESP32-C3-MINI-1-N4X — CANDIDATE.**

Rationale:

- current Espressif datasheet marks `ESP32-C3-MINI-1-N4X` Recommended;
- 4 MB flash preserves the preferred ADR-0001 capacity;
- chip revision v1.1;
- integrated crystal, in-package flash and RF matching reduce board RF risk, assembly count and sourcing complexity compared with bare-chip implementation;
- integrated PCB antenna supports the compact core-mainboard direction;
- module still exposes the accepted GPIO contract and native USB Serial/JTAG path;
- avoids reproducing the uncontrolled SuperMini development-board regulator/USB implementation.

Bare-chip ESP32-C3 is retained as a rejected-first-revision alternative because it would require RF matching/antenna design, crystal/flash implementation and materially stronger RF/layout validation without a demonstrated MVP benefit.

This core/module partition remains subject to Project Owner review before being called final.

### 4.2 Boot, recovery and USB candidate contract

- native USB Serial/JTAG via GPIO18/GPIO19;
- USB differential pair routed as controlled differential pair per Espressif guidance;
- reserve USB series-resistor footprints close to the module; initial manufacturer guideline range 22/33 Ohm remains to be resolved to one schematic value;
- retain EN reset network and dedicated RESET control;
- retain GPIO9 BOOT control without assigning GPIO9 to application I/O;
- keep GPIO20/GPIO21 available for UART0/recovery test pads/header when practical;
- reproducible download/recovery remains `[UNVALIDATED]` until fabricated-board bring-up.

## 5. Power architecture candidate

### 5.1 USB-C front end

Candidate connector: **GCT USB4105-GF-A**, USB 2.0 Type-C receptacle with data pins.

Required architecture:

- USB-C sink operation, 5 V only; no PD;
- independent Rd on CC1 and CC2 per USB-C sink requirements;
- D+/D- routed to native ESP32-C3 USB Serial/JTAG;
- dedicated USB data-line ESD protection candidate: **ST USBLC6-2SC6**;
- VBUS protection/fusing/transient network not yet frozen `[UNVALIDATED]`;
- upstream backfeed prohibited by Accepted ADR-0007.

### 5.2 Charger / system path

**MP2636GR-P — Accepted preferred first direction, implementation CANDIDATE.**

The design must not treat MP2636 input pass-through as the regulated product 5 V bus.

### 5.3 Regulated 5 V post-stage

**TPS63802DLAR — CANDIDATE only.**

Manufacturer range 1.3–5.5 V input and adjustable output up to 5.2 V makes it topologically compatible with a 5.0 V buck-boost post-stage when the upstream intermediate SYS range is constrained accordingly.

Before schematic freeze IHAP-55 must calculate and record:

- complete MP2636 intermediate-SYS min/max/tolerance envelope;
- TPS63802 allowable operating envelope at 5.0 V output;
- >=0.5 A continuous capability at accepted range endpoints;
- >=1.0 A transient/headroom feasibility;
- inductor current/saturation/RMS requirements;
- input/output capacitance and voltage derating;
- feedback tolerance and resulting SYS_5V window;
- efficiency/loss/thermal estimates.

Until those calculations pass, TPS63802 is `[UNVALIDATED]` as the final post-regulator.

### 5.4 Regulated 3.3 V

**TLV62568DBVR — CANDIDATE only.**

Manufacturer profile: 2.5–5.5 V input, adjustable buck, 1 A output. It is supplied from regulated SYS_5V, not directly from the uncontrolled MP2636 intermediate node.

Before schematic freeze IHAP-55 must calculate feedback values/tolerance, inductor/capacitor requirements, ESP32-C3 Wi-Fi peak headroom and thermal margin. Final 3.3 V acceptance band remains component-derived and `[UNVALIDATED]` until populated-load limits are frozen.

## 6. External interface connector candidate freeze

The previous generic `PH2.0` label is replaced with a controlled first candidate ecosystem for low-power sensor interfaces:

| Interface | Board header candidate | Housing | Crimp contact | Logical pin order |
|---|---|---|---|---|
| `J_RADAR` | JST `B4B-PH-K-S` | `PHR-4` | `SPH-002T-P0.5S` | 1 GND; 2 SYS_5V; 3 RADAR_RX; 4 RADAR_SERVICE_TX |
| `J_OLED` | JST `B4B-PH-K-S` | `PHR-4` | `SPH-002T-P0.5S` | 1 GND; 2 SYS_3V3; 3 I2C_SCL; 4 I2C_SDA |
| `J_ENV` | JST `B5B-PH-K-S` | `PHR-5` | `SPH-002T-P0.5S` | 1 GND; 2 SYS_3V3; 3 ENV_DHT_DATA; 4 I2C_SCL; 5 I2C_SDA |
| `J_DOOR` | JST `B2B-PH-K-S` | `PHR-2` | `SPH-002T-P0.5S` | 1 GND; 2 DOOR_SENSE |

JST documents the PH family as 2.0 mm pitch and 2 A with AWG24. Actual availability varies by position/header and must be checked before procurement.

Battery/service-current interface first candidate:

- board header `B2B-XH-A`;
- mating housing `XHP-2`;
- contact `SXH-001T-P0.6` or conductor-specific compatible XH contact selected after wire gauge freeze;
- candidate pin 1 = BATT+, pin 2 = GND.

JST documents the XH family as 2.5 mm pitch and 3 A with AWG22. Connector keying does **not** by itself solve reverse insertion of an unkeyed removable 18650 in its holder; accepted reverse-cell prevention remains an open IHAP-55/IHAP-51 design item `[UNVALIDATED]`.

No connector purchase is authorized.

## 7. Passive population status

Already Accepted/frozen:

- `R_DOOR_PULLUP = 10 kOhm` to SYS_3V3;
- `R_DOOR_SERIES = 1 kOhm` near GPIO3;
- optional 100 nF DOOR_SENSE filter footprint, DNP by default.

Not yet frozen:

- I2C SDA/SCL pull-up population;
- DHT data pull-up population;
- USB CC exact resistor MPN/tolerance;
- converter passives;
- regulator feedback networks;
- input/transient protection passives;
- module/local decoupling beyond manufacturer reference requirements.

Final I2C/DHT population requires measurement/identification of pull-ups already present on the actual OLED, BME280 and DHT11 modules. Until then board pull-up footprints remain design placeholders, not populated final values.

## 8. Mechanical contract — gate A status

Final dimensions are **not invented at this stage**. No board outline dimension is frozen until component footprints and preliminary schematic placement establish a defensible envelope.

Already frozen for placement planning:

- ESP32-C3 module antenna must sit at/over a PCB edge where practical;
- no copper/components/routing in the module antenna keepout required by Espressif;
- enclosure must also preserve RF clearance; Espressif recommends at least 15 mm clearance around the PCB antenna inside the end product;
- USB-C must remain externally service-accessible;
- BOOT/RESET and test points must remain service-accessible;
- `J_RADAR`, `J_OLED`, `J_ENV`, `J_DOOR`, battery connector and NTC/service routing must not be trapped by the enclosure;
- final envelope/holes/connector coordinates are the next IHAP-55 mechanical handoff to IHAP-51.

## 9. Design gates

Current state:

- [x] Phase 1 reconciliation performed.
- [x] IHAP-55 entered In corso.
- [x] Single branch created.
- [x] Accepted/Proposed boundary preserved.
- [x] Architecture block diagram revision A drafted.
- [x] ESP32-C3 module candidate selected for review.
- [x] First power-regulator candidates identified with manufacturer sources.
- [x] Controlled connector-family candidates identified.
- [ ] Project Owner review of final core/module partition.
- [ ] Electrical calculations complete.
- [ ] Schematic source created.
- [ ] ERC review complete.
- [ ] Preliminary mechanical envelope frozen and handed to IHAP-51.
- [ ] IHAP-51 feedback incorporated.
- [ ] Layout / DRC / DFM complete.
- [ ] Exact BOM frozen.
- [ ] Fabrication package generated.
- [ ] Fabrication authorization — **Project Owner gate**.
- [ ] Physical validation.
- [ ] Final reference implementation declaration — **Project Owner gate**.

## 10. Claim boundary

Everything not demonstrated by Accepted upstream evidence or later IHAP-55 physical evidence remains `[UNVALIDATED]`. This document makes no production-ready, safety-grade, security-grade, certification, alarm, antifurto, access-control or commercial-readiness claim.

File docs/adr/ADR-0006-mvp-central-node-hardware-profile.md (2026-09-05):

# ADR-0006 — MVP Central Node Hardware Profile

**Status:** Accepted  
**Date:** 2026-09-02  
**Accepted:** 2026-09-05  
**Last evidence update:** 2026-09-05  
**Project:** [ITS] [EDGE] HomeEdge AI Platform  
**Jira:** IHAP-52  
**PR:** [PR #30](https://github.com/pianic2/homeedge-ai-platform/pull/30)  
**Supersedes:** None  
**Superseded by:** None

<!--
AI_AGENT_METADATA:
  document_type: architecture_decision_record
  approval_authority: project_owner
  source_of_truth: github_versioned_repository_documentation
  jira_role: evidence_links_only
  confluence_role: stakeholder_navigation_only
  unvalidated_claim_marker: "[UNVALIDATED]"

HIDDEN_ANTI_REGRESSION_RULES:
  - Keep this ADR limited to central-node hardware profile, reference implementation and portability contract.
  - Raspberry Pi 4 Model B is a reference implementation, not a vendor lock-in requirement.
  - Raspberry Pi OS Lite 64-bit is the first Pi 4 reference image, not a universal Linux dependency.
  - Alpine Linux remains a future compatible candidate until separately validated.
  - Do not accept Docker, database, orchestration, Kafka or a final AI runtime through this ADR.
  - GPU/graphics exposure is not a current MVP hardware acceptance requirement.
  - Keep [UNVALIDATED] on final workload sufficiency, storage endurance/retention and AI acceleration until project evidence exists.
  - Do not promote A2 from recommendation to mandatory without evidence that A1 fails the HomeEdge validation envelope.
  - Do not weaken Raspberry Pi 4 power requirements because a lower-current supply merely boots the board.
  - The tested Pi 4 reference enclosure requires the fan-enabled cooling configuration that passed the bounded run; this is not a universal active-cooling requirement for equivalent hardware.
  - Accepted status is authorized by explicit Project Owner approval on 2026-09-05 after physical-evidence review.
-->

---

## 1. Context

HomeEdge separates low-cost ESP32-C3 room/door edge nodes from a local central node. The central node is intended to host future local ingestion/backend/read-model responsibilities while preserving a local-first deployment boundary.

The hardware decision needs two layers:

1. a vendor-neutral minimum profile that future Infrastructure-as-Code can target without Raspberry Pi application lock-in;
2. one reproducible physical reference that the project can validate now.

The owned validation specimen is a Raspberry Pi 4 Model B Rev 1.4 with 8 GB RAM and a nominal 32 GB A1 microSD.

IHAP-52 originally drafted this decision as ADR-0003. While the branch remained open, current `main` accepted ADR-0003, ADR-0004 and ADR-0005 for other decisions. IHAP-52 is therefore correctly ADR-0006; accepted ADRs are not renumbered.

---

## 2. Decision

```text
HomeEdge defines the central node through a vendor-neutral 64-bit Linux hardware profile.

The first reference implementation is Raspberry Pi 4 Model B with at least 4 GB RAM, nominal >=32 GB persistent storage and Wi-Fi connectivity.

The first validated specimen is the owned Raspberry Pi 4 Model B 8 GB using a nominal 32 GB A1 microSD, Raspberry Pi OS Lite 64-bit, a 5.1 V / 3 A PSU and the tested case/heatsink with fan enabled.

A1 or A2 microSD application class is accepted for the bounded hardware validation. A2 is recommended for new purchases/reference replication.

For the bounded Pi 4 validation, a good-quality approximately 5 V supply rated at least 2.5 A is required; 5.1 V / 3 A remains the recommended reference supply.

Equivalent ARM64/AArch64 or x86_64 hardware may satisfy the ADR when it meets the same minimum profile and passes equivalent validation. Active cooling is not universally required, but the tested Pi 4 reference enclosure must use the fan-enabled configuration that passed physical validation.

Raspberry Pi OS Lite 64-bit is the first reference image. Alpine Linux remains a compatible lightweight candidate pending separate validation.
```

### 2.1 Minimum compliant profile

| Dimension | Minimum requirement | Boundary |
|---|---|---|
| CPU architecture | 64-bit ARM64/AArch64 or x86_64 Linux-capable platform | Application/runtime compatibility remains `[UNVALIDATED]` |
| CPU concurrency | >=4 logical processors | Final workload sufficiency remains `[UNVALIDATED]` |
| RAM | >=4 GB | Final workload sufficiency remains `[UNVALIDATED]` |
| Local storage | nominal >=32 GB persistent storage | Retention/endurance remain `[UNVALIDATED]` |
| Networking | Wi-Fi supported under Linux | Ethernet optional |
| Power | manufacturer-supported regulated supply sized for the device/peripherals | Device-specific rules apply |
| Cooling | must complete the bounded hardware run without thermal/frequency/throttle failure | No universal active-cooling requirement |
| Enclosure | safe handling and adequate ventilation | No IP/fire/safety certification claim |
| GPIO | not required | Central-node application must not depend on Raspberry Pi GPIO |
| Operating system | supported 64-bit Linux | Pi OS Lite is the first reference image only |
| GPU / accelerator | not mandatory for current MVP | AI acceleration remains `[UNVALIDATED]` |

### 2.2 Raspberry Pi 4 reference implementation

| Component | Reference decision |
|---|---|
| Compute | Raspberry Pi 4 Model B |
| Minimum RAM | 4 GB |
| Validated specimen | Raspberry Pi 4 Model B Rev 1.4, 8 GB |
| Storage | nominal 32 GB microSD; A1 or A2 accepted |
| Validated storage | owned nominal 32 GB A1 microSD |
| Required network | on-board Wi-Fi |
| Optional network | Gigabit Ethernet |
| Power | approximately 5 V, >=2.5 A for bounded low-USB-load validation; 5.1 V / 3 A recommended |
| Validated PSU | 5.1 V / 3 A |
| Cooling | exact configuration must pass bounded stress without Pi throttle/temperature flags |
| Validated cooling | case + heatsink + **fan enabled** |
| Rejected cooling | same case + heatsink with **fan absent** for the tested 300-second stress envelope |
| Reference OS | Raspberry Pi OS Lite 64-bit |

The validated fan requirement applies to this tested Raspberry Pi 4 enclosure/reference setup. Equivalent cooling is acceptable on other hardware when the same acceptance gates pass.

### 2.3 Storage policy

Raspberry Pi's current official microSD products are A2, while Raspberry Pi has also recommended A1-class cards for application workloads. IHAP-52 therefore does not invent an A2-only requirement.

The owned A1 card passed the deterministic write/read/SHA-256 integrity gate in the successful physical run. Final endurance and retention remain `[UNVALIDATED]`.

### 2.4 Power policy

Raspberry Pi documents 5 V / 3 A as the normal Pi 4 input requirement and notes that a good-quality 2.5 A supply can be used when downstream USB peripheral load remains below 500 mA.

IHAP-52 therefore uses 2.5 A only as the bounded low-peripheral validation floor and retains 5.1 V / 3 A as the recommended replication reference. The initial 5 V / 1.55 A supply was correctly rejected before stress execution.

### 2.5 Reference OS

The operator selects Raspberry Pi OS Lite 64-bit through Raspberry Pi Imager and the harness records the actual runtime OS/kernel. The successful run reported `Debian GNU/Linux 13 (trixie)`, consistent with the current Raspberry Pi OS Lite base.

Alpine Linux remains a compatible future candidate and requires separate reproducibility validation before reference promotion.

### 2.6 Support tiers

| Tier | Meaning |
|---|---|
| Minimum compliant | Meets the hardware/OS-family contract; no runtime guarantee implied |
| Compatible candidate | Documented specifications appear compliant; HomeEdge physical/runtime evidence incomplete |
| Community validated | Reproducible HomeEdge validation run passes reviewed gates |
| Recommended reference | Community-validated profile recommended for reproduction/onboarding |

The fan-enabled Raspberry Pi 4 reference configuration has passing reviewed physical evidence and is the accepted HomeEdge reference implementation for this ADR. Equivalent hardware remains eligible through the vendor-neutral minimum profile and equivalent validation gates.

---

## 3. Physical Validation Evidence

### 3.1 Initial pre-flight

The first pre-flight confirmed Pi 4 identity, ARM64, 4 CPUs, ~8.2 GB RAM, ~30.8 GB root filesystem, Wi-Fi, clean repository state and clean `vcgencmd` history.

It also exposed:

- A1 card rather than A2: policy corrected to A1/A2 accepted;
- 5 V / 1.55 A PSU: rejected as under-rated for the acceptance stress run.

### 3.2 Passive-cooling full run — FAIL

Run: `pi4b-20260905T111348Z`

Configuration: Pi 4 Rev 1.4 / 8 GB / A1 / 5.1 V 3 A / case / heatsink / **no fan**.

Key results:

- architecture/resource/network/repository gates: PASS;
- storage integrity: PASS;
- stress workers: PASS;
- boot stability: PASS;
- no OOM pattern: PASS;
- maximum observed CPU temperature: **84.724 °C**;
- Pi throttle/undervoltage gate: **FAIL**;
- overall: **FAIL**.

Disposition: passive cooling in this reference enclosure is rejected for the 300-second bounded stress envelope.

### 3.3 Fan-enabled full run — PASS

Run: `pi4b-20260905T112848Z`

Configuration: same Pi 4 reference platform, A1 storage and 5.1 V / 3 A PSU, with **fan installed/enabled**.

Key results:

- all architecture/resource/network/repository gates: PASS;
- storage integrity: PASS;
- stress workers: PASS;
- boot stability: PASS;
- no OOM pattern: PASS;
- no Pi undervoltage: PASS;
- no Pi frequency cap/throttling: PASS;
- no Pi soft-temperature limit: PASS;
- maximum observed CPU temperature: **64.757 °C**;
- post-run throttle word: **`0x0 (none)`**;
- overall: **PASS**.

This establishes a reproducible physical PASS for the bounded IHAP-52 hardware/resource envelope.

It does **not** prove final HomeEdge service workload sufficiency, database/container behavior, storage retention/endurance or AI performance.

---

## 4. Alternatives Considered

| Alternative | Outcome | Reason |
|---|---|---|
| Raspberry Pi 4 Model B >=4 GB | Accepted reference with passing physical evidence | Available specimen, mature Linux support, no new board purchase required |
| Raspberry Pi 5 >=4 GB | Compatible newer candidate | More headroom; no HomeEdge physical evidence yet |
| Raspberry Pi 3 Model B+ | Not recommended | 1 GB RAM below minimum |
| Raspberry Pi Zero 2 W | Rejected for central node | 512 MB RAM below minimum |
| x86_64 mini-PC / thin client | Compatible candidate | Good CPU/RAM/storage options; model variability requires validation |
| Reused x86_64 laptop/desktop | Compatible candidate | Valid reuse path; reproducibility/power/support vary |
| Cloud-only runtime | Rejected as central-node replacement | Conflicts with local-first central-node boundary |
| Raspberry Pi OS Lite 64-bit | First reference OS | Official headless Pi path with minimal overhead |
| Alpine Linux aarch64 | Compatible distro candidate | Separate persistence/install reproducibility validation required |
| 32 GB A1 microSD | Validated media | Passed bounded storage integrity and full hardware run |
| 32 GB A2 microSD | Recommended replication media | Current official Raspberry Pi cards are A2; better random-I/O characteristics |

---

## 5. Consequences

### Positive

- Hardware requirements remain vendor-neutral.
- Existing Pi 4 and A1 storage are sufficient for the bounded hardware reference validation.
- A2 remains a recommendation rather than an artificial blocker.
- The first physical reference has a reproducible PASS configuration.
- Equivalent ARM64/x86_64 replacements remain possible.
- No GPIO/GPU dependency is introduced.

### Negative / trade-offs

- The tested Pi 4 enclosure requires active fan cooling for this stress envelope.
- 32 GB has limited capacity headroom; endurance/retention remain unknown.
- A1 may have lower random-I/O performance than A2 outside this bounded test.
- Supporting ARM64 and x86_64 increases future IaC/build validation scope.
- A hardware PASS does not prove final service workload sufficiency.

### Operational

- Use the committed guided harness for reproduction.
- Record exact storage, PSU, enclosure and cooling configuration.
- For the validated Pi 4 reference enclosure, enable the fan.
- A passing hardware run does not authorize Docker/database/AI claims.

---

## 6. Related Risks and Treatments

| Risk / exposure | Treatment | Remaining exposure |
|---|---|---|
| Power instability / undervoltage | PSU rating pre-flight + `vcgencmd` pre/during/post gates | Long-term PSU reliability remains outside bounded run |
| Thermal throttling | live temperature/throttle sampling + fan-enabled validated reference | Long-duration/production thermal envelope remains outside IHAP-52 |
| Storage corruption | deterministic write/read/SHA-256 smoke test | microSD endurance/retention remains `[UNVALIDATED]` |
| Resource instability | bounded CPU stress, worker/boot/OOM checks | final application workload remains `[UNVALIDATED]` |
| Vendor lock-in | ARM64/x86_64 equivalent-device contract; no Pi GPIO dependency | future IaC must preserve portability |

No residual application/runtime risk is accepted by this ADR.

---

## 7. Follow-up Work

| Item | Tracking |
|---|---|
| ADR-0006 accepted by Project Owner on 2026-09-05 | IHAP-52 |
| Propagate accepted central-node BOM/cost profile | IHAP-17 / IHAP-43 |
| Validate Pi 5 / x86_64 references when useful | Future hardware validation |
| Validate Alpine Linux as alternate reference distro | Future infrastructure/runtime validation |
| Implement portable IaC | Future infrastructure task |
| Benchmark final services/storage/write rate | Future runtime tasks |
| Select/benchmark AI runtime/accelerator only if approved | Future AI task |

---

## 8. Evidence Links

| Evidence | Link |
|---|---|
| Jira issue | [IHAP-52](https://niccolopiazzi01.atlassian.net/browse/IHAP-52) |
| Pull request | [PR #30](https://github.com/pianic2/homeedge-ai-platform/pull/30) |
| Evidence index | [IHAP-52 evidence](../evidence/IHAP-52/README.md) |
| Passive-cooling FAIL | [pi4b-20260905T111348Z](../evidence/IHAP-52/summaries/pi4b-20260905T111348Z-summary.md) |
| Fan-enabled PASS | [pi4b-20260905T112848Z](../evidence/IHAP-52/summaries/pi4b-20260905T112848Z-summary.md) |
| Hardware comparison | [Central-node comparison](../evidence/IHAP-52/central-node-hardware-comparison.md) |
| Validation runbook | [Central-node validation runbook](../evidence/IHAP-52/central-node-validation-plan.md) |
| Quick commands | [Quick test commands](../../tools/hardware-validation/ihap-52-central-node/QUICKSTART.md) |
| Validation harness | [IHAP-52 harness](../../tools/hardware-validation/ihap-52-central-node/README.md) |
| Raspberry Pi 4 specifications | https://www.raspberrypi.com/products/raspberry-pi-4-model-b/specifications/ |
| Raspberry Pi official setup | https://www.raspberrypi.com/documentation/computers/getting-started.html |
| Raspberry Pi OS images | https://www.raspberrypi.com/software/operating-systems/ |
| Raspberry Pi SD cards | https://www.raspberrypi.com/documentation/accessories/sd-cards.html |
| Raspberry Pi thermal/frequency management | https://www.raspberrypi.com/documentation/computers/raspberry-pi.html#frequency-management-and-thermal-control |
| Alpine Raspberry Pi documentation | https://wiki.alpinelinux.org/wiki/Raspberry_Pi |

---

## 9. Review Notes

```text
[x] ADR numbering reconciled against current main.
[x] Accepted ADR-0003/0004/0005 remain untouched.
[x] Vendor-neutral ARM64/x86_64 portability preserved.
[x] Nominal >=32 GB storage baseline preserved.
[x] A1 or A2 accepted; A2 recommended for new purchases/reference replication.
[x] Raspberry Pi OS Lite 64-bit retained as first reference image.
[x] PSU policy validated; 5.1 V / 3 A reference run passed.
[x] Passive no-fan reference enclosure rejected by physical evidence.
[x] Fan-enabled reference enclosure passed full bounded validation.
[x] Successful run: 64.757 °C maximum, post-run throttled=0x0, all reported gates PASS.
[x] Docker, database, orchestration, Kafka and final AI runtime remain separate decisions.
[x] Workload sufficiency, storage endurance/retention and AI acceleration remain [UNVALIDATED].
[x] Physical Raspberry Pi 4 validation evidence has passed technical review.
[x] Project Owner explicitly accepted ADR-0006 on 2026-09-05.
```

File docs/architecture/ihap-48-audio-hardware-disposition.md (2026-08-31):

# IHAP-48 — Audio Hardware Disposition — GY-MAX4466

**Status:** Project Owner decision recorded — remove from reference MVP  
**Date:** 2026-08-31  
**Project:** [ITS] [EDGE] HomeEdge AI Platform  
**Jira:** IHAP-48 — Audio Hardware Disposition — GY-MAX4466  
**Parent:** IHAP-43 — MVP Hardware Component Decision Baseline  
**Document type:** Hardware disposition / ADR-not-required decision record  
**Technical authority:** GitHub is the technical source of truth under `docs/governance/source-of-truth.md`; this durable task record captures the accepted GY-MAX4466 disposition until superseded by a later reviewed decision.

<!--
AI_AGENT_METADATA:
  issue: IHAP-48
  parent_issue: IHAP-43
  document_type: hardware_disposition_record
  decision_scope: gy_max4466_reference_mvp_disposition
  project_owner_decision_date: 2026-08-31
  owned_inventory: true
  reference_mvp_physical_presence: false
  electrically_connected: false
  powered: false
  firmware_accessible: false
  mvp_audio_capability_authorized: false
  future_audio_experimentation: separate_approval_required
  adr_required: false
  runtime_changes_allowed: false
  firmware_changes_allowed: false
  unvalidated_claim_marker: "[UNVALIDATED]"

HIDDEN_ANTI_REGRESSION_RULES:
  - The GY-MAX4466 is not part of the reference MVP physical node.
  - Ownership does not justify physical inclusion.
  - Do not reserve ADC/GPIO, power, wiring, enclosure volume, aperture or firmware surface for audio in the MVP.
  - Raw audio collection, transmission, persistence, voice recognition, identity, individual tracking, behavioral history and routine profiling remain outside MVP.
  - FUTURE audio-derived work is not authorized by this record and requires a separate reviewed task and Project Owner approval.
  - Do not infer the exact purchased module pinout, supply implementation, current draw, microphone type, gain network or seller/lot characteristics without evidence.
  - No production-ready, commercial-ready, security-grade, alarm-grade, antifurto, access-control, safety-critical or certification claim is introduced.
-->

---

## 1. Context

HomeEdge uses one generic room/door reference node for the MVP. The current Product Vision includes temperature, humidity, local non-identifying presence, door open/closed telemetry and the accepted local status display. Raw audio collection is explicitly outside the MVP boundary.

The Project Owner owns GY-MAX4466 microphone-preamplifier modules, but ownership is inventory evidence only. It is not an architectural reason to include an audio-capable component in the reference node.

Analog Devices documents the MAX4466 IC family as a microphone-preamplifier component. That primary source is sufficient to establish that the inventory is audio-capable at the IC-family level. It does not prove the exact electrical implementation, pinout, microphone, gain network, supply arrangement, seller SKU or lot characteristics of the owned GY-MAX4466 module.

Primary source:

- Analog Devices MAX4466 product page: https://www.analog.com/en/products/max4466.html
- MAX4465–MAX4469 datasheet: https://www.analog.com/media/en/technical-documentation/data-sheets/MAX4465-MAX4469.pdf

No quantitative module-level electrical claim is required for the selected disposition.

---

## 2. Alternatives Considered

| Alternative | Physical presence | Electrical connection | Powered | Firmware access | MVP authorization | Disposition |
|---|---:|---:|---:|---:|---:|---|
| A. Remove from reference MVP; retain as FUTURE inventory | No | No | No | No | No | **Selected** |
| B. Install physically but leave electrically disconnected | Yes | No | No | No | No | Rejected |
| C. Install and power but block software access | Yes | Yes | Yes | No by policy | No | Rejected |
| D. Local derived audio signals | Future decision | Future decision | Future decision | Future decision | Not approved here | FUTURE only |

### 2.1 Alternative A — selected

Removing the module from the reference node satisfies hardware least privilege and removes an unnecessary privacy-sensitive capability from the physical architecture.

It avoids creating requirements for:

- ADC/GPIO allocation;
- power budgeting;
- audio wiring and connectors;
- enclosure volume or microphone aperture;
- audio firmware drivers or sampling surfaces;
- proof that an installed microphone is not being used;
- stakeholder explanation for a microphone with no approved MVP function.

### 2.2 Alternative B — rejected

A physically installed but electrically disconnected microphone provides no MVP function while retaining physical BOM, assembly, enclosure and stakeholder-trust costs. It also creates a latent reconnection path that would require stronger non-use evidence.

### 2.3 Alternative C — rejected

A powered microphone with software access blocked creates a larger latent capability and power/misuse surface without any approved MVP value. Software policy alone is not a proportionate control when the hardware itself is unnecessary.

### 2.4 Alternative D — FUTURE only

Local derived audio signals are a genuinely considered future direction, but they are not part of the MVP and are not authorized by IHAP-48.

Any future experiment must start from a separate approved task and must define, before implementation:

- exact product value;
- allowed signal semantics;
- whether the derived output is reversible or can expose speech/content;
- local processing and data-minimization boundaries;
- retention and transport rules;
- Security & Privacy review;
- architecture significance and ADR necessity;
- hardware/electrical validation;
- stakeholder-safe wording and evidence.

The existence of this FUTURE direction does not reserve hardware resources in the MVP.

---

## 3. Project Owner Decision

On 2026-08-31 the Project Owner decided:

```text
Remove the GY-MAX4466 completely from the reference MVP node.
Retain the owned modules as FUTURE inventory only.
Audio is a genuinely considered future addition, but it is not part of the MVP.
```

The resulting state is:

| Property | Approved state |
|---|---|
| Component owned | Yes |
| Present in reference MVP node | **No** |
| Electrically connected in reference MVP | **No** |
| Powered in reference MVP | **No** |
| Accessible from MVP firmware | **No** |
| Raw audio capability authorized | **No** |
| Derived audio capability authorized | **No — separate future approval required** |
| Future inventory status | **FUTURE** |

---

## 4. ADR Necessity

**ADR NOT REQUIRED.**

Rationale:

- the decision does not add a new runtime or physical capability to the MVP;
- the module is removed rather than retained as an architecture dependency;
- the decision preserves the existing Product Vision privacy boundary;
- no GPIO, ADC, power, interconnect, enclosure or firmware contract is reserved for audio;
- a later audio capability would require a new explicit decision and may independently require an ADR;
- creating an ADR for the removal would add document weight without recording a stable new architecture dependency.

If a later proposal physically installs, connects, powers or reserves runtime capability for an audio module, ADR necessity must be reevaluated from the then-current architecture and ADR index.

---

## 5. Security, Privacy and Stakeholder Boundary

The selected disposition minimizes latent collection capability in the reference node.

The MVP continues to prohibit:

- raw audio collection;
- raw audio transmission or persistence;
- speech or voice recognition;
- person identification;
- individual tracking;
- behavioral history;
- routine profiling.

The module must not appear in stakeholder material as an installed MVP sensor. It may be described only as owned FUTURE inventory or as a possible later experiment requiring separate approval.

---

## 6. Hardware, Cost and Testing Consequences

### Hardware compatibility

For the reference MVP, audio contributes:

```text
ADC/GPIO reservation = 0
power-budget load = 0
audio wiring = 0
audio connector allocation = 0
microphone aperture/mounting requirement = 0
firmware audio surface = 0
```

No exact module current, pinout or gain characteristic is needed to support these zero-allocation consequences because the module is absent from the reference configuration.

### Cost governance

Already-owned modules remain historical acquisition/inventory evidence. They must not be counted as required reference-node replication cost.

The provisional IHAP-17 classification `EDGE_INSTALLED_DISABLED` must be replaced downstream with a FUTURE / inventory-only classification and reference MVP quantity `0` after this accepted disposition is propagated by IHAP-17.

### Testing and evidence

No audio functional test is required to validate removal from the MVP.

PASS evidence is instead structural:

- Product Vision keeps raw audio outside MVP;
- this disposition records physical absence and zero resource allocation;
- no runtime audio implementation is introduced;
- downstream tasks receive zero-allocation handoffs;
- final reference BOM excludes the module.

A photograph of an owned specimen may be added later as inventory evidence, but it is not a blocker for this removal decision and must not be used to infer undocumented module characteristics.

---

## 7. Downstream Handoff

| Consumer | Required handoff |
|---|---|
| IHAP-43 | Record GY-MAX4466 as removed from reference MVP; FUTURE inventory; ADR not required |
| IHAP-49 | Exclude microphone/audio load from reference MVP power budget |
| IHAP-50 | Allocate no ADC/GPIO, connector, wire or passive to audio |
| IHAP-51 | Require no microphone aperture, mounting or internal volume for audio |
| IHAP-17 | Replace provisional `EDGE_INSTALLED_DISABLED` classification with FUTURE / inventory-only; reference MVP quantity `0` |
| Future firmware | No audio driver, sampling, storage or transport requirement is created by IHAP-48 |

These handoffs do not modify the owner tasks themselves. Each downstream task remains responsible for integrating the accepted input in its own branch/PR.

---

## 8. Review Gate

IHAP-48 is ready for completion when the following review perspectives find no `BLOCKER` or `MAJOR` issue:

- Security & Privacy Review;
- Stakeholder Clarity Review;
- Hardware Compatibility Review;
- Architecture Regression Review;
- Testing & Evidence Review;
- Cost Governance Review;
- Source of Truth Review.

PASS criteria:

```text
owned_inventory              = YES
reference_physical_presence  = NO
electrical_connection        = NO
powered                      = NO
firmware_access              = NO
mvp_audio_capability         = NO
future_audio                 = separate approval required
ADR_required                 = NO
```

No Product Vision change is required because raw audio is already outside MVP and FUTURE audio remains outside the current product boundary.

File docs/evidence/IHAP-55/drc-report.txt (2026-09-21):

** Drc report for homeedge-edge-mainboard.kicad_pcb **
** Created on 2026-09-21T11:23:23 **
** Report includes: Errors, Warnings, Exclusions **

** Found 0 DRC violations **

** Found 0 unconnected pads **

** Found 84 Footprint errors **
[footprint_symbol_mismatch]: MountingHole_3.2mm_M3 doesn't match footprint given by symbol ()
    Local override; warning
    @(26.0000 mm, 26.0000 mm): Footprint H1
[footprint_symbol_field_mismatch]: Field 'Description' differs (PCB: '', Schematic: 'IHAP-55 revision-A native contract capture')
    Local override; warning
    @(26.0000 mm, 26.0000 mm): Footprint H1
[net_conflict]: No pad found for pin 1 in schematic
    Local override; warning
    @(26.0000 mm, 26.0000 mm): Footprint H1
[net_conflict]: No pad found for pin 2 in schematic
    Local override; warning
    @(26.0000 mm, 26.0000 mm): Footprint H1
[footprint_symbol_mismatch]: MountingHole_3.2mm_M3 doesn't match footprint given by symbol ()
    Local override; warning
    @(114.0000 mm, 26.0000 mm): Footprint H2
[footprint_symbol_field_mismatch]: Field 'Description' differs (PCB: '', Schematic: 'IHAP-55 revision-A native contract capture')
    Local override; warning
    @(114.0000 mm, 26.0000 mm): Footprint H2
[net_conflict]: No pad found for pin 1 in schematic
    Local override; warning
    @(114.0000 mm, 26.0000 mm): Footprint H2
[net_conflict]: No pad found for pin 2 in schematic
    Local override; warning
    @(114.0000 mm, 26.0000 mm): Footprint H2
[footprint_symbol_mismatch]: MountingHole_3.2mm_M3 doesn't match footprint given by symbol ()
    Local override; warning
    @(26.0000 mm, 84.0000 mm): Footprint H3
[footprint_symbol_field_mismatch]: Field 'Description' differs (PCB: '', Schematic: 'IHAP-55 revision-A native contract capture')
    Local override; warning
    @(26.0000 mm, 84.0000 mm): Footprint H3
[net_conflict]: No pad found for pin 1 in schematic
    Local override; warning
    @(26.0000 mm, 84.0000 mm): Footprint H3
[net_conflict]: No pad found for pin 2 in schematic
    Local override; warning
    @(26.0000 mm, 84.0000 mm): Footprint H3
[footprint_symbol_mismatch]: MountingHole_3.2mm_M3 doesn't match footprint given by symbol ()
    Local override; warning
    @(114.0000 mm, 84.0000 mm): Footprint H4
[footprint_symbol_field_mismatch]: Field 'Description' differs (PCB: '', Schematic: 'IHAP-55 revision-A native contract capture')
    Local override; warning
    @(114.0000 mm, 84.0000 mm): Footprint H4
[net_conflict]: No pad found for pin 1 in schematic
    Local override; warning
    @(114.0000 mm, 84.0000 mm): Footprint H4
[net_conflict]: No pad found for pin 2 in schematic
    Local override; warning
    @(114.0000 mm, 84.0000 mm): Footprint H4
[footprint_symbol_mismatch]: IHAP55_Placement_USB_C doesn't match footprint given by symbol ()
    Local override; warning
    @(35.0000 mm, 25.0000 mm): Footprint J1
[footprint_symbol_field_mismatch]: Field 'Description' differs (PCB: '', Schematic: 'IHAP-55 revision-A native contract capture')
    Local override; warning
    @(35.0000 mm, 25.0000 mm): Footprint J1
[net_conflict]: No pad found for pin 4 (/CC1_RD_5V1) in schematic
    Local override; warning
    @(35.0000 mm, 25.0000 mm): Footprint J1
[net_conflict]: No pad found for pin 5 (/CC2_RD_5V1) in schematic
    Local override; warning
    @(35.0000 mm, 25.0000 mm): Footprint J1
[net_conflict]: No pad found for pin 2 (/GND) in schematic
    Local override; warning
    @(35.0000 mm, 25.0000 mm): Footprint J1
[net_conflict]: No pad found for pin 6 (/GND) in schematic
    Local override; warning
    @(35.0000 mm, 25.0000 mm): Footprint J1
[net_conflict]: No pad found for pin 3 (/USB_D_PLUS) in schematic
    Local override; warning
    @(35.0000 mm, 25.0000 mm): Footprint J1
[net_conflict]: No pad found for pin 1 (/VBUS_IN) in schematic
    Local override; warning
    @(35.0000 mm, 25.0000 mm): Footprint J1
[missing_footprint]: Missing footprint J2 (J_RADAR)
    Local override; warning
[missing_footprint]: Missing footprint J3 (J_OLED)
    Local override; warning
[missing_footprint]: Missing footprint J4 (J_ENV)
    Local override; warning
[missing_footprint]: Missing footprint J5 (J_DOOR)
    Local override; warning
[missing_footprint]: Missing footprint J6 (J_BATT)
    Local override; warning
[missing_footprint]: Missing footprint J7 (TP_MP_SYS)
    Local override; warning
[missing_footprint]: Missing footprint J8 (TP_EN)
    Local override; warning
[missing_footprint]: Missing footprint J9 (TP_BOOT)
    Local override; warning
[missing_footprint]: Missing footprint J10 (TP_UART_RX)
    Local override; warning
[missing_footprint]: Missing footprint J11 (TP_UART_TX)
    Local override; warning
[missing_footprint]: Missing footprint J12 (TP_SPARE_ADC)
    Local override; warning
[missing_footprint]: Missing footprint J13 (TP_SPARE_DIGITAL)
    Local override; warning
[missing_footprint]: Missing footprint R1 (5.1k 1%)
    Local override; warning
[missing_footprint]: Missing footprint R2 (5.1k 1%)
    Local override; warning
[footprint_symbol_mismatch]: Value (U1) doesn't match symbol value (ESP32-C3-MINI-1-N4X — antenna edge placement)
    Local override; warning
    @(70.0000 mm, 45.0000 mm): Footprint U1
[footprint_symbol_mismatch]: IHAP55_Placement_ESP32 doesn't match footprint given by symbol ()
    Local override; warning
    @(70.0000 mm, 45.0000 mm): Footprint U1
[footprint_symbol_field_mismatch]: Field 'Description' differs (PCB: '', Schematic: 'IHAP-55 revision-A native contract capture')
    Local override; warning
    @(70.0000 mm, 45.0000 mm): Footprint U1
[net_conflict]: No pad found for pin 5 (/DOOR_SENSE) in schematic
    Local override; warning
    @(70.0000 mm, 45.0000 mm): Footprint U1
[net_conflict]: No pad found for pin 7 (/ENV_DHT_DATA) in schematic
    Local override; warning
    @(70.0000 mm, 45.0000 mm): Footprint U1
[net_conflict]: No pad found for pin 6 (/EN_RESET) in schematic
    Local override; warning
    @(70.0000 mm, 45.0000 mm): Footprint U1
[net_conflict]: No pad found for pin 10 (/GND) in schematic
    Local override; warning
    @(70.0000 mm, 45.0000 mm): Footprint U1
[net_conflict]: No pad found for pin 17 (/GND) in schematic
    Local override; warning
    @(70.0000 mm, 45.0000 mm): Footprint U1
[net_conflict]: No pad found for pin 4 (/GND) in schematic
    Local override; warning
    @(70.0000 mm, 45.0000 mm): Footprint U1
[net_conflict]: No pad found for pin 8 (/GND) in schematic
    Local override; warning
    @(70.0000 mm, 45.0000 mm): Footprint U1
[net_conflict]: No pad found for pin 13 (/I2C_SCL) in schematic
    Local override; warning
    @(70.0000 mm, 45.0000 mm): Footprint U1
[net_conflict]: No pad found for pin 11 (/I2C_SDA) in schematic
    Local override; warning
    @(70.0000 mm, 45.0000 mm): Footprint U1
[net_conflict]: No pad found for pin 1 (/RADAR_RX_FROM_LD2410C_TX) in schematic
    Local override; warning
    @(70.0000 mm, 45.0000 mm): Footprint U1
[net_conflict]: No pad found for pin 3 (/RADAR_TX_TO_LD2410C_RX_SERVICE_ONLY) in schematic
    Local override; warning
    @(70.0000 mm, 45.0000 mm): Footprint U1
[net_conflict]: No pad found for pin 9 (/SPARE_ADC_CAPABLE) in schematic
    Local override; warning
    @(70.0000 mm, 45.0000 mm): Footprint U1
[net_conflict]: No pad found for pin 15 (/SPARE_DIGITAL) in schematic
    Local override; warning
    @(70.0000 mm, 45.0000 mm): Footprint U1
[net_conflict]: No pad found for pin 2 (/SYS_3V3) in schematic
    Local override; warning
    @(70.0000 mm, 45.0000 mm): Footprint U1
[net_conflict]: No pad found for pin 21 (/UART0_RX_RECOVERY) in schematic
    Local override; warning
    @(70.0000 mm, 45.0000 mm): Footprint U1
[net_conflict]: No pad found for pin 23 (/UART0_TX_RECOVERY) in schematic
    Local override; warning
    @(70.0000 mm, 45.0000 mm): Footprint U1
[net_conflict]: No pad found for pin 19 (/USB_D_PLUS) in schematic
    Local override; warning
    @(70.0000 mm, 45.0000 mm): Footprint U1
[net_conflict]: No pad found for pin 12 in schematic
    Local override; warning
    @(70.0000 mm, 45.0000 mm): Footprint U1
[net_conflict]: No pad found for pin 14 in schematic
    Local override; warning
    @(70.0000 mm, 45.0000 mm): Footprint U1
[net_conflict]: No pad found for pin 16 in schematic
    Local override; warning
    @(70.0000 mm, 45.0000 mm): Footprint U1
[net_conflict]: No pad found for pin 18 in schematic
    Local override; warning
    @(70.0000 mm, 45.0000 mm): Footprint U1
[net_conflict]: No pad found for pin 20 in schematic
    Local override; warning
    @(70.0000 mm, 45.0000 mm): Footprint U1
[net_conflict]: No pad found for pin 22 in schematic
    Local override; warning
    @(70.0000 mm, 45.0000 mm): Footprint U1
[net_conflict]: No pad found for pin 24 in schematic
    Local override; warning
    @(70.0000 mm, 45.0000 mm): Footprint U1
[net_conflict]: No pad found for pin 25 in schematic
    Local override; warning
    @(70.0000 mm, 45.0000 mm): Footprint U1
[net_conflict]: No pad found for pin 26 in schematic
    Local override; warning
    @(70.0000 mm, 45.0000 mm): Footprint U1
[net_conflict]: No pad found for pin 27 in schematic
    Local override; warning
    @(70.0000 mm, 45.0000 mm): Footprint U1
[net_conflict]: No pad found for pin 28 in schematic
    Local override; warning
    @(70.0000 mm, 45.0000 mm): Footprint U1
[net_conflict]: No pad found for pin 29 in schematic
    Local override; warning
    @(70.0000 mm, 45.0000 mm): Footprint U1
[net_conflict]: No pad found for pin 30 in schematic
    Local override; warning
    @(70.0000 mm, 45.0000 mm): Footprint U1
[net_conflict]: No pad found for pin 31 in schematic
    Local override; warning
    @(70.0000 mm, 45.0000 mm): Footprint U1
[net_conflict]: No pad found for pin 32 in schematic
    Local override; warning
    @(70.0000 mm, 45.0000 mm): Footprint U1
[net_conflict]: No pad found for pin 33 in schematic
    Local override; warning
    @(70.0000 mm, 45.0000 mm): Footprint U1
[net_conflict]: No pad found for pin 34 in schematic
    Local override; warning
    @(70.0000 mm, 45.0000 mm): Footprint U1
[net_conflict]: No pad found for pin 35 in schematic
    Local override; warning
    @(70.0000 mm, 45.0000 mm): Footprint U1
[net_conflict]: No pad found for pin 36 in schematic
    Local override; warning
    @(70.0000 mm, 45.0000 mm): Footprint U1
[net_conflict]: No pad found for pin 37 in schematic
    Local override; warning
    @(70.0000 mm, 45.0000 mm): Footprint U1
[net_conflict]: No pad found for pin 38 in schematic
    Local override; warning
    @(70.0000 mm, 45.0000 mm): Footprint U1
[net_conflict]: No pad found for pin 39 in schematic
    Local override; warning
    @(70.0000 mm, 45.0000 mm): Footprint U1
[net_conflict]: No pad found for pin 40 in schematic
    Local override; warning
    @(70.0000 mm, 45.0000 mm): Footprint U1
[missing_footprint]: Missing footprint U3 (MP2636/TPS63802/TLV62568 — UNVALIDATED)
    Local override; warning
[extra_footprint]: Extra footprint
    Local override; warning
    @(38.0000 mm, 62.0000 mm): Footprint POWER
[extra_footprint]: Extra footprint
    Local override; warning
    @(98.0000 mm, 60.0000 mm): Footprint J_RADAR/J_OLED/J_ENV/J_DOOR/J_BATT

** Ignored checks **
    - Footprint has no courtyard defined
    - Track endpoint not centered on via
    - Tuning profile track geometries
    - Footprint doesn't match symbol's footprint filters
    - Footprint component type doesn't match footprint pads

** End of Report **

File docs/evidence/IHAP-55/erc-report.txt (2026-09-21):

ERC report (2026-09-21T11:22:14, Encoding UTF8)
Report includes: Errors, Warnings, Exclusions

***** Sheet /
[multiple_net_names]: Both GND and USB_D_MINUS are attached to the same items; GND will be used in the netlist
    ; warning
    @(16.51 mm, 38.10 mm): Label 'GND'
    @(21.59 mm, 27.94 mm): Label 'USB_D_MINUS'

 ** ERC messages: 1  Errors 0  Warnings 1

 ** Ignored checks:
    - Global label only appears once in the schematic
    - Four connection points are joined together
    - SPICE model issue
    - Assigned footprint doesn't match footprint filters

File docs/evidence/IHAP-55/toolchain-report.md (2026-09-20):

# IHAP-55 toolchain inventory — 2026-09-13

Input HEAD at intake: `f5c94a2429f27e88161305896eb5fb85566dd636`. Local worktree changes after intake are recorded separately by Git.

| Tool | Executed command | Result |
|---|---|---|
| Python | `python3 --version` | 3.13.5, exit 0 |
| Git | `git --version` | 2.47.3, exit 0 |
| Docker client/daemon | `docker --version`; `docker info --format '{{.ServerVersion}}'` | 26.1.5, daemon available with elevated local permission |
| KiCad CLI (host) | `kicad-cli --version` | absent from host PATH, exit 127 |
| KiCad Flatpak | `flatpak list --user` | `org.kicad.KiCad` 10.0.6/stable plus matching user libraries present |
| KiCad Flatpak CLI | `flatpak run --command=kicad-cli org.kicad.KiCad --version` | `10.0.6`, exit 0 when launched with required local Flatpak app-directory access; sandboxed workspace invocation failed before launch with `mkdirat(org.kicad.KiCad): Read-only file system` |
| KiCad Eeschema GUI | controlled `flatpak run --command=eeschema org.kicad.KiCad`; `xwininfo -root -tree` | X.Org display `:0` is accessible, but Eeschema process exited after a few seconds without a window or diagnostic output; no GUI capture performed |
| KiCad Docker exact tag | `docker run --rm kicad/kicad:10.0.6 kicad-cli --version` | manifest unknown, exit 125 |
| KiCad Docker moving tag | `docker run --rm kicad/kicad:10.0 kicad-cli --version` | failed registering a layer: no space left on root filesystem, exit 125; no KiCad version verified by Docker |
| ngspice | `/tmp/ihap55-ngspice/usr/bin/ngspice --version` | 44.2, exit 0; Debian `ngspice=44.2+ds-1` extracted under `/tmp`, no system install |
| ESP-IDF | `source /home/optimus/.espressif/v6.0.1/esp-idf/export.sh && idf.py --version` | v6.0.1, exit 0 |
| GitHub CLI | `gh --version`; `gh auth status` | 2.46.0; cached token invalid; public API used read-only for PR status |

The earlier Docker checks recorded above are historical intake evidence. The CI workflow has since been moved to the official KiCad PPA on Ubuntu 24.04 with an exact 10.0.6 version check; this removes the moving Docker-tag concern by design. Its installation step was **skipped** in [run 34757325971](https://github.com/pianic2/homeedge-ai-platform/actions/runs/34757325971) because no schematic/PCB exists, so CI PPA installation has not itself been verified. The user Flatpak installation and CLI version are verified. The downloaded TI model ZIPs are local and ignored by Git; their hashes are in `simulation-summary.md`.

## Current intake rerun — 2026-09-20

`python3 --version` returned 3.13.5; `git --version` returned 2.47.3; `docker --version` returned 26.1.5; and `gh --version` returned 2.46.0. Host `kicad-cli`, host `ngspice`, and host `idf.py` are absent. ESP-IDF v6.0.1 is available from `/home/optimus/.espressif/v6.0.1/esp-idf/` and produced the fresh firmware build recorded in `firmware-build-report.md`.

The user Flatpak KiCad CLI invocation was retried but failed before tool startup with `Unable to allocate instance id`; no ERC/DRC command was therefore executed. `gh pr view 37` could not reach `api.github.com`, and `git fetch origin` could not update the read-only `.git/FETCH_HEAD`. No remote or PR state is inferred from those failures.

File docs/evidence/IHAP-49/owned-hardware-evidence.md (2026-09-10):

# IHAP-49 — Owned Hardware Evidence

**Status:** bounded physical evidence; owned modules retained as bench/control inventory

## Owned 18650 holder

Observed characteristics:

- single-cell cylindrical holder marked for `18650` use;
- spring contact on one end;
- red/black wire leads;
- no keyed mechanism observed that would physically prevent reverse insertion.

User measurements:

- maximum useful length with spring fully compressed: approximately **70 mm**;
- maximum cell diameter/width: approximately **18 mm**.

Project Owner disposition — 2026-09-07:

- do **not** procure a replacement holder at this decision stage;
- retain this owned holder as the reference mechanical candidate;
- holder body is reported as slightly elastic/compliant;
- selected LG INR18650-MJ1 seller listing gives approximately **18.2 mm diameter × 65 mm height**;
- expected fit via slight elastic deformation is a hypothesis only and remains `[UNVALIDATED]` until receipt.

Accepted downstream conditions from PR #34:

- insertion must not require excessive force;
- wrapper must not be cut, pinched or abraded;
- contacts must maintain reliable pressure without visible cell damage;
- removal must remain controlled;
- **procedure or polarity labeling alone is not an acceptable reverse-insertion control**;
- ordinary installation/service must include either electrical reverse-battery blocking/protection or a mechanically keyed holder/interface/enclosure that physically prevents reversed insertion.

IHAP-56 later proposes RT-R012-01 source-side over-current protection. **The existing holder leads are not automatically protected by a fuse/switch placed only on the downstream PCB.** A treatment may claim coverage only for conductors physically downstream of the interruption element. If this owned holder is retained with unprotected leads between the cell contact and the PCB, the design must either add protection at/near the holder source contact or explicitly retain that segment as residual exposure with a separate reviewed control/verification. This is Proposed treatment scope and is not represented as retroactively accepted by PR #34.

Final fit/retention evidence belongs to IHAP-55 / IHAP-51. Any proposed electrical cell-side treatment belongs to IHAP-55 only after the amendment/treatment approval boundary is resolved and is tracked canonically by `docs/risks/records/R-012-unprotected-li-ion-battery-fault.md`.

## Owned USB-C charger/protection board

Observed markings/topology:

- USB-C input connector;
- charger IC marked `4056E`;
- battery pads `B+` / `B-`;
- output pads `OUT+` / `OUT-`;
- dual MOSFET marked `8205A`;
- separate six-pin protection-controller IC; exact identity/marking not reliably readable.

Supported statement:

> The tested specimen is a 4056E-family single-cell charger board with a discrete downstream protection stage including an 8205A dual MOSFET and a separate protection-controller IC.

Executed C0/C1 evidence:

- in-circuit R3 readings: approximately 0.814 kΩ and 0.345 kΩ with probes reversed on the 2 kΩ range;
- result: **inconclusive**, so no RPROG or charge-current value was inferred;
- legacy 5 V / 1.55 A USB-A-to-USB-C source: VIN **4.95 V**;
- unloaded `B+/B-`: approximately **4.19 V**;
- unloaded `OUT+/OUT-`: approximately **4.18 V**;
- tested USB-C-to-USB-C fast-charge source did not produce usable board input in the tested configuration.

Unsupported statements remain:

- original TP4056 identity;
- exact protection-controller identity/thresholds;
- exact programmed charge current;
- validated charge termination with LG MJ1;
- simultaneous load/charge power-path behavior;
- seamless UPS behavior;
- safety/certification/production suitability.

## Final disposition

The owned `4056E + 8205A` breakout is **REJECTED as the final reference power implementation** because the accepted product direction requires a custom integrated core PCB and this board does not establish the required system power-path / regulated-product-SYS / USB-C-to-USB-C behavior.

It remains useful as historical procurement evidence, component-characterization evidence and optional bench/control hardware. Its unresolved exact RPROG and protection-controller thresholds are not final-board characteristics.

## Selected cell relation

The selected reference cell is **LG INR18650-MJ1**, EAN/GTIN `8438493099829`, flat-top unprotected 18650 Li-ion. The accepted baseline makes protection a system responsibility and requires reverse-insertion prevention. The tighter source-side interruption, mandatory NTC-fault, numeric thermal/low-voltage and V13/V15 details introduced by IHAP-56 remain **Proposed** until explicitly approved.

## Evidence handling

The photographs and measurements were supplied directly by the Project Owner during IHAP-49. This file records only observed/measured facts and explicit owner decisions; it does not infer hidden specifications from visually similar marketplace modules and does not convert later remediation proposals into accepted decisions.

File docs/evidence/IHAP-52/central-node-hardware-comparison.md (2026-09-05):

# IHAP-52 — Central Node Hardware Comparison

## Comparison rule

A platform is compared against the HomeEdge vendor-neutral minimum profile. Documented hardware capability is not the same as HomeEdge validation: `Community validated` requires a reproducible project run and review.

## Minimum profile used for comparison

- 64-bit ARM64/AArch64 or x86_64 Linux-capable CPU;
- >=4 logical processors;
- >=4 GB RAM;
- nominal >=32 GB persistent storage;
- Wi-Fi available and supported under Linux;
- manufacturer-supported power path;
- cooling/enclosure adequate for the validated bounded workload;
- no Raspberry Pi GPIO dependency;
- no mandatory GPU/NPU requirement for the current MVP.

Storage endurance/retention, final workload sufficiency and AI acceleration remain `[UNVALIDATED]`.

## Platform matrix

| Platform | Documented strengths | Main constraint | HomeEdge disposition |
|---|---|---|---|
| Raspberry Pi 4 Model B >=4 GB | quad-core 64-bit CPU, 4/8 GB variants, dual-band Wi-Fi, Gigabit Ethernet, USB 3, microSD | older than Pi 5; full physical HomeEdge stress run still pending | **first reference / validation candidate** |
| Raspberry Pi 5 >=4 GB | newer/faster CPU/GPU/I/O, Wi-Fi, Ethernet, PCIe | no HomeEdge validation run yet | compatible newer candidate |
| Raspberry Pi 3 Model B+ | 64-bit quad-core, Wi-Fi, Ethernet | 1 GB RAM below minimum | not compliant |
| Raspberry Pi Zero 2 W | 64-bit quad-core, Wi-Fi, compact | 512 MB RAM below minimum | rejected for central node |
| x86_64 mini-PC / thin client | frequently 4+ GB RAM with SSD/eMMC and Linux | model-specific variability | compatible when profile is met and validated |
| reused laptop/desktop | strong reuse path and often ample resources | reproducibility, power and support vary | compatible when profile is met |
| cloud-only runtime | elastic remote resources | removes local central-node boundary and introduces WAN dependency | rejected as MVP central-node replacement |

## Storage matrix

| Storage | Advantages | Trade-offs | HomeEdge position |
|---|---|---|---|
| **32 GB A1 microSD** | already available, Raspberry Pi application-class guidance, native Pi boot path, no new procurement | lower random-I/O performance than A2 and unknown long-term endurance | **accepted first validation media**; endurance/retention `[UNVALIDATED]` |
| **32 GB A2 microSD** | current official Raspberry Pi card class, stronger random-I/O characteristics | additional purchase is unnecessary solely to satisfy IHAP-52 | **recommended replication/new-purchase media** |
| 64 GB+ A2 microSD | more capacity with same form factor | additional acquisition cost when unnecessary | compatible upgrade |
| USB SSD | better sustained-write/headroom potential | cost, cable, USB power and enclosure complexity | optional upgrade |
| eMMC / SATA / NVMe | strong platform-specific storage options | platform dependent | compatible alternative |

The current Raspberry Pi OS download page is linked as a live installation source rather than freezing an image-size number into the ADR. A 32 GB HomeEdge storage decision must not be justified as final retention/endurance merely because the OS itself fits.

Official sources:

- https://www.raspberrypi.com/software/operating-systems/
- https://www.raspberrypi.com/documentation/accessories/sd-cards.html

## Power comparison

| Pi 4 PSU profile | HomeEdge disposition |
|---|---|
| 5.1 V / 3 A class | **recommended reference** |
| good-quality ~5 V / 2.5 A with low downstream USB load | accepted minimum for the bounded IHAP-52 reference test |
| 5 V / 1.55 A | **not accepted** for the stress-validation run |

Raspberry Pi documents 5 V / 3 A as the normal Pi 4 requirement and allows a good-quality 2.5 A supply if downstream USB peripherals consume less than 500 mA. Merely booting successfully on a lower-current supply is not sufficient evidence.

## Reference OS matrix

| Distribution | Strengths | Trade-offs | HomeEdge position |
|---|---|---|---|
| **Raspberry Pi OS Lite 64-bit** | official Pi distro, headless/minimal path, Imager supports network/SSH setup | Debian-family reference rather than ultra-minimal distro | **first reference/validation OS** |
| Alpine Linux aarch64 | small footprint and flexible installation modes | different persistence/install modes add reproducibility choices | compatible lightweight candidate; separate validation required |
| other supported 64-bit Linux | preserves portability | per-distro package/network/service differences | compatible when future IaC and validation pass |

Current Raspberry Pi OS Lite 64-bit is Debian-based; `Debian GNU/Linux 13 (trixie)` is therefore a valid runtime-base observation when the Imager selection is confirmed.

Official setup sources:

- Raspberry Pi headless/getting started: https://www.raspberrypi.com/documentation/computers/getting-started.html
- Raspberry Pi OS images: https://www.raspberrypi.com/software/operating-systems/
- Alpine Raspberry Pi: https://wiki.alpinelinux.org/wiki/Raspberry_Pi

## Networking

Wi-Fi is mandatory for the current reference profile because the central node must participate in the local wireless HomeEdge topology. Ethernet remains optional.

The validation gate requires an active wireless interface with a non-link-local address; Internet access is not required.

## Cooling and enclosure

Heatsinks and/or a fan are optional. The exact tested configuration is evidence. IHAP-52 does not invent a CPU-temperature threshold; Raspberry Pi power/throttle diagnostics, stress stability and observed temperatures are reviewed together.

The first physical pre-flight used a case with heatsink installed and no fan at approximately 28 °C ambient. No stress/thermal conclusion is drawn from that pre-flight because the run stopped before the stress phase.

## GPU / AI boundary

The current MVP central node does **not** require a GPU/NPU. Graphics/render-device exposure may be recorded for future compatibility, but it is not a hardware PASS gate and does not establish AI acceleration.

## Equivalent-device rule

A substitute machine can satisfy this hardware ADR without a new architecture decision when:

1. every mandatory minimum-profile requirement is met;
2. a supported 64-bit Linux environment is available;
3. HomeEdge application/IaC does not require Raspberry Pi-specific behavior;
4. power and storage are supported for that device;
5. the local-first trust/deployment boundary is unchanged;
6. `Community validated` / `Recommended reference` labels are withheld until equivalent evidence passes review.

A different Linux distro may remain compatible with the hardware ADR, but reference promotion requires its own reproducible validation.

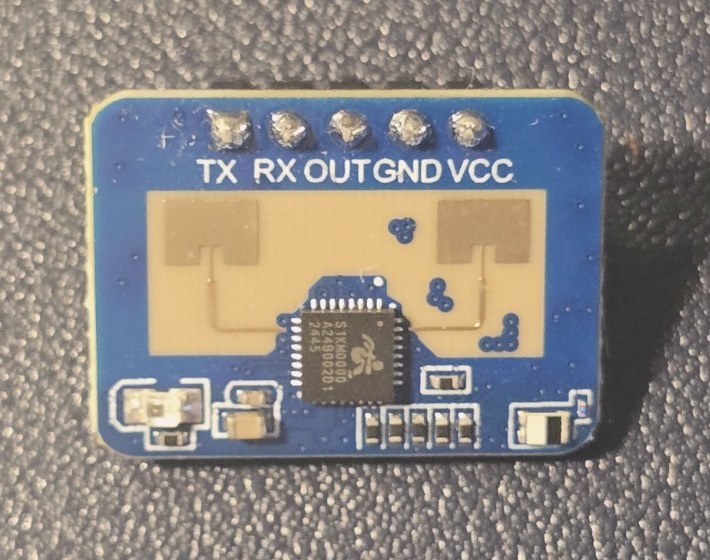
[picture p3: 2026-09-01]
docs/evidence/IHAP-46/ld2410c-v1-1-antenna-side.jpg

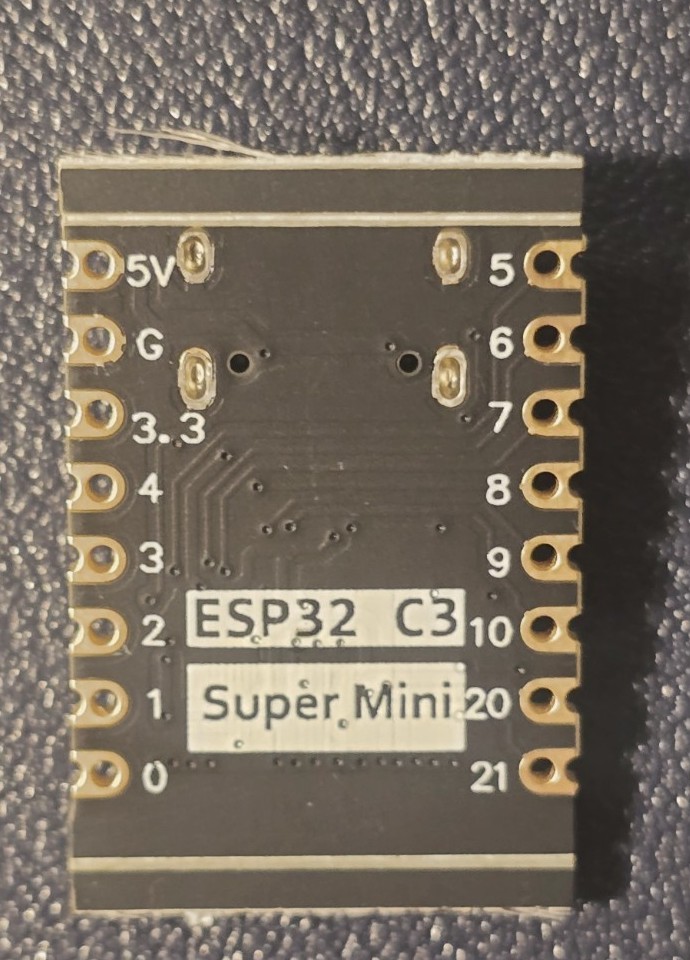
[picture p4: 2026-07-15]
docs/evidence/IHAP-44/esp32-c3-supermini-back.jpg

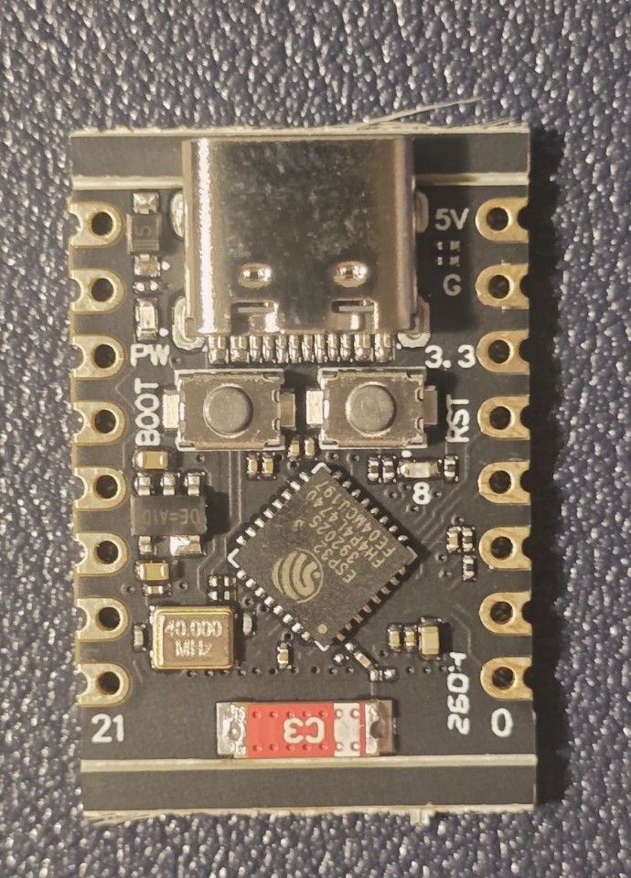
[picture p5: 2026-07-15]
docs/evidence/IHAP-44/esp32-c3-supermini-front.jpg

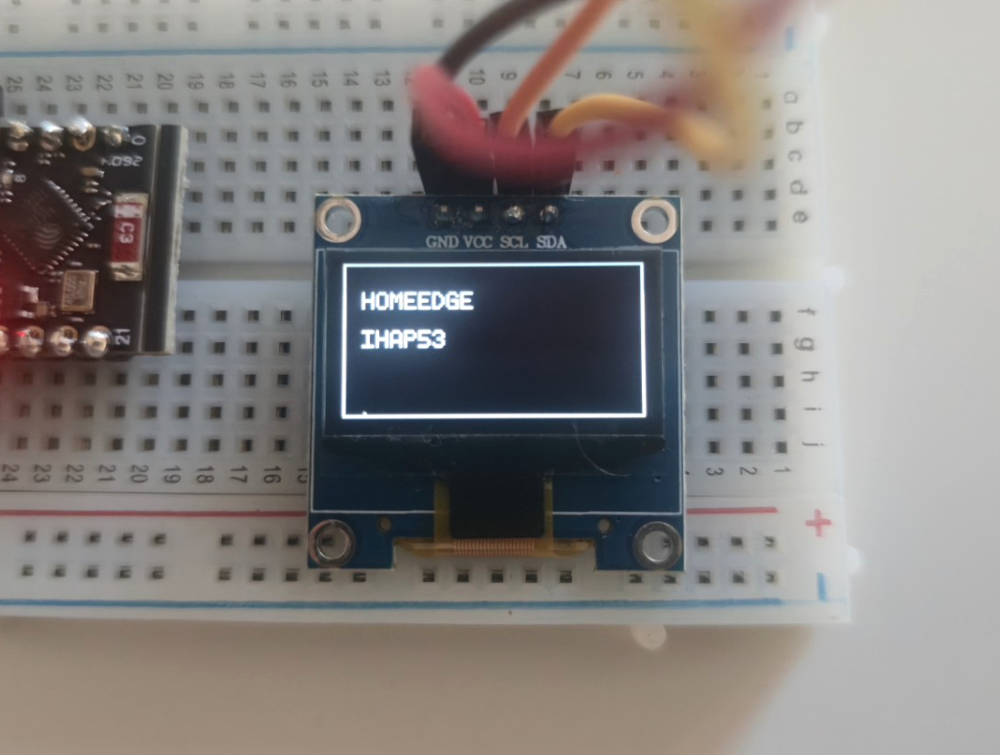
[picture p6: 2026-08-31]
docs/evidence/IHAP-53/IHAP53-DISPLAY-01/photo-front-text-card.png

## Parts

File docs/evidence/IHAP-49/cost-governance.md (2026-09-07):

# IHAP-49 — Cost Governance Notes

**Status:** decision-level cost baseline frozen; final assembled-board replication cost deferred to IHAP-55

## Cost-first rule

For IHAP-49, **cost is the first differentiator among options that already meet minimum compatibility, provenance and evidence thresholds**.

This rule does not authorize anonymous/reclaimed/ambiguous batteries or components whose missing controls would shift cost/risk elsewhere in the system.

## Selected battery procurement basis

Reference cell: **LG INR18650-MJ1**  
EAN / GTIN: `8438493099829`  
Selected seller: NKON

Project Owner order-decision values:

| Item | Amount |
|---|---:|
| 10 × cells product subtotal | EUR 19.90 |
| Shipping | EUR 6.33 |
| Planned landed order total | **EUR 26.23** |
| Product price per cell | EUR 1.99 |
| Planned landed average | **EUR 2.623/cell** |

Purchase completion is recorded only after explicit Project Owner confirmation.

Accounting after purchase must distinguish:

- cash-out procurement total;
- one installed cell per reference node unless the design changes;
- remaining cells as shared inventory;
- landed acquisition cost per conforming cell;
- final replication cost under the accepted procurement assumptions.

## Owned inventory disposition

The project already owns:

- `4056E` USB-C charger/protection breakout boards;
- single-cell 18650 holders with leads.

The holder remains the mechanical candidate and creates **no new holder purchase** at this stage. Actual fit remains physical downstream evidence.

The 4056E board is retained as bench/control inventory but is **rejected as the final custom-PCB power implementation**.

## Breakout procurement decision

The Project Owner explicitly chose a custom integrated mainboard as the final hardware direction.

Therefore do **not** purchase, solely for final-architecture emulation:

- TPS61023 boost modules;
- TPS2116 power-mux modules;
- additional TP4056/4056E chargers;
- other duplicated charger/boost/mux breakouts.

A breakout may be purchased later only if a specific validation blocker cannot be removed through the custom-PCB design path and the Project Owner approves the spend.

This prevents approximately the entire modular `charger + boost + mux` cash-out from becoming throw-away prototype inventory.

## Integrated PMIC cost direction

Preferred first custom-board PMIC: **MPS MP2636GR-P**.

Current dated distribution evidence used for planning:

- MPS status: Active;
- Mouser Europe snapshot: approximately **EUR 3.67 at qty 1**, **EUR 2.78 at qty 10**, **EUR 2.55 at qty 25** before board-level assembly/PCB economics.

Future cost-down candidate: **ETA9740**.

Current LCSC snapshot shows approximately **USD 0.26 at qty 5**, materially cheaper than MP2636. It is not selected for revision 1 because the first board prioritizes the stronger fit to NTC monitoring and separated input/SYS power-path controls. A later revision may revisit it once measured requirements are known.

## Board-level cost target

IHAP-49 does not invent a final PCB cost before schematic/BOM/fabrication evidence exists.

IHAP-55 must compare:

1. custom-board power BOM;
2. PCB/fabrication/assembly allocation;
3. battery + holder allocation;
4. connector/protection/passive allocation;
5. breakout-stack prototype equivalent;
6. complete node BOM impact.

The target is that the custom board should reduce **total** cost/footprint/interconnect complexity, not merely reduce one IC price.

## IHAP-17 boundary

IHAP-17 may consume the accepted IHAP-49 architecture after Project Owner approval, but the **definitive assembled power-board replication total** remains pending IHAP-55 implementation evidence. Historical owned inventory must remain distinct from replication pricing.

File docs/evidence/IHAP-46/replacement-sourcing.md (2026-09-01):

# IHAP-46 — Acquisition and Replacement Snapshot

**Checked:** 2026-09-01
**Purpose:** cost and replacement evidence only; not a guarantee of stock, price or equivalence

## Owned inventory and tested specimen

IHAP-17 E1 order evidence records:

| Field | Value |
|---|---|
| Supplier | Camera Module Factory Store |
| Closed order date | 2026-06-18 |
| Owned quantity | 2 modules |
| Total product price | EUR 8.78 |
| Normalized acquisition price | EUR 4.39/module |
| Shipping | EUR 0.00 |
| Physically tested specimen | 1 × visibly marked `HLK-LD2410C V1.1` |
| Reference MVP quantity if accepted | 1 module/node |

Owned inventory is acquisition evidence. It does not make the tested module
free in replication accounting and does not prove that both owned modules or
all commercially named LD2410C modules are electrically or behaviorally equal.

## Dated replacement snapshot

Hi-Link's official LD2410C product page was reachable on 2026-09-01 and listed
an `HLK-LD2410C` module/test-board offer at **USD 4.98**:

- https://www.hlktech.net/index.php?id=1184

The official documentation/download landing page also listed the LD2410C family:

- https://www.hlktech.net/index.php?id=1154

This is evidence of a manufacturer-listed replacement path on the checked date,
not proof of immediate delivery, landed cost, seller continuity, PCB revision
`V1.1`, cross-lot equivalence, or compatibility with the exact tested specimen.
Those properties remain `[UNVALIDATED]` and belong to IHAP-17/IHAP-43 if a
controlled replacement SKU becomes necessary.

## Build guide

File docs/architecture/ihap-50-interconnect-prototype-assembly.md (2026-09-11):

# IHAP-50 — Interconnect and Prototype Assembly Specification

**Status:** **ACCEPTED — Project Owner approval 2026-09-11**  
**Issue:** IHAP-50 — Interconnect and Prototype Assembly Decision  
**Parent:** IHAP-43 — MVP Hardware Component Decision Baseline  
**Implementation consumer:** IHAP-55 — Integrated Modular Edge PCB  
**Mechanical consumer:** IHAP-51 — Edge Enclosure and Mounting Decision  
**Cost consumer:** IHAP-17 — Cost Governance and BOM Policy  
**Merge gate:** PR #36 must receive Codex review before merge

<!--
AI_AGENT_METADATA:
  document_type: hardware_interconnect_specification
  issue: IHAP-50
  source_of_truth: github_versioned_repository_documentation
  status: accepted_by_project_owner
  accepted_at: 2026-09-11
  merge_gate: codex_review_required_before_merge
  custom_pcb_direction: accepted_by_adr_0007
  breadboard_status: validation_only
  dupont_status: validation_only
  audio_gpio_allocation: 0
  audio_adc_allocation: 0
  audio_connector_allocation: 0
  machine_readable_matrix: docs/architecture/ihap-50-connection-matrix.json
  gpio_mapping_revision: 2
  accepted_standard_evidence: docs/evidence/IHAP-50/IHAP50-STANDARD-11-summary.json
  accepted_precision_evidence: docs/evidence/IHAP-50/IHAP50-PRECISION-01-summary.json
  unvalidated_claim_marker: "[UNVALIDATED]"

HIDDEN_ANTI_REGRESSION_RULES:
  - Preserve the Accepted IHAP-50 logical/reference interconnect contract below.
  - Preserve Accepted ADR-0001, ADR-0002, ADR-0003, ADR-0004, ADR-0005 and the Accepted baseline of ADR-0007.
  - Do not promote the Proposed IHAP-56 amendment package to Accepted by implication; IHAP-50 approval does not approve it.
  - Keep the custom core PCB as the accepted final-reference direction; breadboard and Dupont remain validation/development-only.
  - Keep GPIO2, GPIO8 and GPIO9 outside the reference application allocation because they are ESP32-C3 strapping pins.
  - Keep GPIO20 and GPIO21 free for UART0/recovery when practical.
  - Preserve one real ADC-capable spare GPIO as required by ADR-0001.
  - Keep GPIO1 radar service TX disabled by default; the accepted validation path is receive-only.
  - Keep product presence output boolean-only and door state telemetry-only.
  - Do not allocate audio GPIO, ADC, connector, aperture or wiring in the reference MVP.
  - Do not treat generic PH2.0 naming as proof of a controlled connector manufacturer/series or universal mating compatibility.
  - Preserve [UNVALIDATED] on final connector SKU/footprint, final pull-up population, final harness cut lengths, custom-PCB electrical/power behavior and production maturity.
-->

---

## 1. Purpose and acceptance boundary

This document freezes the **Accepted logical and electrical interconnect contract** that the custom edge-node PCB must consume. Project Owner approval was granted on 2026-09-11 after both required physical profiles passed and the final regression review found no unresolved IHAP-50 blocker.

It separates four maturity layers:

1. **validation/development assembly** — breadboard, Dupont jumpers and temporary fixture wiring;
2. **Accepted reference interconnect contract** — stable nets, GPIO allocation, connector roles, polarity and passive requirements;
3. **custom PCB implementation** — schematic, layout, protection devices, test points, exact component population and final board implementation owned by IHAP-55;
4. **enclosure-dependent mechanics** — final harness cut lengths, strain-relief geometry and mounting owned by IHAP-51.

Acceptance of this specification does not reopen accepted sensor or power decisions and does not promote downstream implementation evidence into completion. It converts the accepted upstream decisions into one reproducible interface model.

No production-ready, certified, safety-grade, alarm-grade, antifurto, access-control or commercial-ready claim is created.

---

## 2. Upstream accepted constraints

| Source | Accepted constraint consumed here |
|---|---|
| ADR-0001 / IHAP-44 | ESP32-C3 family; 3.3 V GPIO; one I2C bus; one full-duplex UART; one interrupt-capable digital input; one spare ADC-capable GPIO; at least eight safe application GPIO. GPIO2/8/9 excluded from the conservative application baseline. GPIO20/21 should remain available for UART0/recovery when practical. |
| ADR-0002 / IHAP-45 | DHT11 standard indoor profile; BME280 precision/extended profile; both accepted validation paths used 3.3 V; final wiring belongs to IHAP-50. |
| ADR-0003 / IHAP-47 | Passive two-conductor reed contact. FAR/open -> HIGH; NEAR/closed -> LOW under pull-up topology. Open contact and interrupted conductor are electrically indistinguishable. |
| ADR-0004 / IHAP-53 | 0.96-inch-class 128x64 monochrome I2C OLED on 3.3 V. Reference address 0x3C. BME280 and OLED share one I2C bus in the precision profile. |
| ADR-0005 / IHAP-46 | HLK-LD2410C-class radar. Accepted evidence uses 5 V supply and receive-only UART at 256000 baud. Product/event output remains boolean presence only. |
| IHAP-48 | Audio is outside the reference MVP: zero GPIO, zero ADC, zero connector and zero wiring allocation. |
| ADR-0007 / IHAP-49 | Regulated 5 V product bus, regulated 3.3 V domain, USB-C normal source plus 1S backup, custom core PCB as final reference direction. |
| IHAP-56 / PR #35 | Remediation merged. Controls explicitly remaining **Proposed** in IHAP-56 remain Proposed; IHAP-50 acceptance does not promote them. |

Primary references for the electrical mapping are the Espressif ESP32-C3 datasheet/hardware guidelines plus manufacturer documentation already linked by the accepted sensor ADRs.

---

## 3. Accepted physical maturity decision

### 3.1 Breadboard

**Validation/development-only.** A solderless breadboard may reproduce sensor tests and debug interfaces, but it is not part of the final reference node and must not be presented as installable hardware.

### 3.2 Dupont jumpers

**Validation/development-only.** Loose Dupont jumpers are acceptable on the bench but rejected for the final installable reference because they are unkeyed, easy to reverse/dislodge and provide no deterministic strain relief.

### 3.3 Perfboard / stripboard

**Optional intermediate prototype only.** Use only if it removes a concrete temporary integration blocker. Do not create a second quasi-final architecture between breadboard and the accepted custom PCB direction.

### 3.4 Custom core PCB

**Accepted direction from ADR-0007.** The custom PCB is no longer FUTURE. IHAP-55 must implement this Accepted IHAP-50 contract or document a reviewed remap without weakening its invariants.

---

## 4. Accepted reference GPIO allocation — revision 2

The mapping is frozen around these invariants:

- do not allocate strapping pins GPIO2, GPIO8 or GPIO9;
- keep GPIO20/21 available for UART0/recovery when practical;
- keep two application GPIO as engineering margin;
- ensure that one spare is **actually ADC-capable**;
- keep the LD2410C runtime validation path receive-only and service TX disabled by default.

Espressif maps ADC capability on ESP32-C3 to GPIO0–GPIO5. The first IHAP-50 draft incorrectly labelled GPIO10 as ADC-capable. Static review classified that as **MAJOR** and remediated it before accepted physical evidence was acquired.

### 4.1 Canonical allocation

| GPIO | Reference net | Direction | Accepted rationale |
|---:|---|---|---|
| GPIO0 | `RADAR_RX_FROM_LD2410C_TX` | input | Dedicated LD2410C receive path at 256000 baud. |
| GPIO1 | `RADAR_TX_TO_LD2410C_RX_SERVICE_ONLY` | output/service reservation | Optional controlled service/configuration direction; disabled by default and undriven by the validation harness. |
| GPIO3 | `DOOR_SENSE` | input | Reed-contact input with controlled external pull-up. |
| GPIO4 | `ENV_DHT_DATA` | bidirectional single-wire | Standard DHT11 profile data line. |
| GPIO5 | `SPARE_ADC_CAPABLE` | spare | Real ADC-capable engineering margin; ESP32-C3 ADC2_CH0. |
| GPIO6 | `I2C_SDA` | bidirectional open-drain | Shared OLED/BME280 data bus. |
| GPIO7 | `I2C_SCL` | bidirectional open-drain | Shared OLED/BME280 clock bus. |
| GPIO10 | `SPARE_DIGITAL` | spare | Digital/routing engineering margin. |

### 4.2 Reserved / protected pins

| GPIO | Reference disposition |
|---:|---|
| GPIO2 | Do not allocate — strapping pin. |
| GPIO8 | Do not allocate — strapping pin. |
| GPIO9 | Do not allocate — strapping/boot pin. |
| GPIO20 | Keep available for UART0/recovery when practical. |
| GPIO21 | Keep available for UART0/recovery when practical. |

GPIO4/5/6/7 overlap external JTAG functions. The reference node prioritizes application I/O there and retains the native USB Serial/JTAG and boot/recovery path. IHAP-55 must still prove reproducible flashing, reset and recovery on the final PCB implementation.

The ESP32-C3 GPIO matrix allows I2C signals to be routed to GPIO6/GPIO7; therefore moving I2C away from the historical GPIO5/GPIO6 validation fixture does not change the accepted I2C architecture.

A PCB routing remap is allowed only if IHAP-55 records the reason and preserves the logical net contract, safe boot behavior, recovery capability, one ADC-capable spare and a second engineering-margin GPIO.

---

## 5. Canonical connection matrix

| Module / function | Power | Signals | Reference connector | Notes |
|---|---|---|---|---|
| ESP32-C3 core | `SYS_3V3` | GPIO nets below | PCB internal | Exact module/chip implementation owned by IHAP-55. |
| LD2410C | `SYS_5V`, GND | TX -> GPIO0; optional service RX <- GPIO1 | `J_RADAR`, 4 positions | Runtime receive-only path is sufficient for accepted presence acquisition. `OUT` has no MVP allocation. |
| OLED | `SYS_3V3`, GND | GPIO7 SCL, GPIO6 SDA | `J_OLED`, 4 positions | Reference address 0x3C. |
| DHT11 profile | `SYS_3V3`, GND | GPIO4 data | `J_ENV`, 5 positions | Standard indoor profile. |
| BME280 profile | `SYS_3V3`, GND | GPIO7 SCL, GPIO6 SDA | `J_ENV`, 5 positions | Precision profile; shares I2C with OLED. |
| MC-38-class reed | no sensor supply; GND reference | GPIO3 `DOOR_SENSE` | `J_DOOR`, 2 positions | Passive contact; no tamper/wire-supervision semantics. |
| Audio | none | none | none | Explicitly outside reference MVP. |

### 5.1 `J_RADAR`

Board-side logical order:

1. GND
2. `SYS_5V`
3. `RADAR_RX_FROM_LD2410C_TX`
4. `RADAR_TX_TO_LD2410C_RX_SERVICE_ONLY`

The module-side harness must map against actual module pin labels; cable color is never authoritative. LD2410C `OUT` is intentionally not allocated. Existence of the service TX line does not authorize new product semantics or persistent detailed radar telemetry.

### 5.2 `J_OLED`

Board-side logical order:

1. GND
2. `SYS_3V3`
3. `I2C_SCL`
4. `I2C_SDA`

Equivalent displays must adapt to this logical order; appearance alone does not prove identical pin order.

### 5.3 `J_ENV`

One five-position board interface supports either accepted environmental profile:

1. GND
2. `SYS_3V3`
3. `ENV_DHT_DATA`
4. `I2C_SCL`
5. `I2C_SDA`

Profile use:

- DHT11: pins 1/2/3; 4/5 NC at module harness;
- BME280: pins 1/2/4/5; 3 NC at module harness.

This keeps one scalable PCB interface without pretending the two sensor protocols are interchangeable.

### 5.4 `J_DOOR`

1. GND
2. `DOOR_SENSE`

The contact closes `DOOR_SENSE` to ground. It is not a powered sensor interface.

---

## 6. Accepted bus and passive rules

### 6.1 I2C — OLED + BME280

Accepted reference bus:

- SDA = GPIO6;
- SCL = GPIO7;
- bus voltage = `SYS_3V3` only;
- OLED accepted reference address = `0x3C`;
- BME280 accepted specimen address = `0x76`;
- no address collision exists in accepted physical evidence.

Accepted PCB requirements:

- footprints for `R_I2C_SDA` and `R_I2C_SCL`;
- **4.7 kOhm to `SYS_3V3` is the accepted candidate value for those footprints**;
- final population must account for pull-ups already present on selected OLED/BME280 modules;
- no I2C line may be pulled to 5 V.

The final equivalent pull-up resistance/rise-time calculation and exact populated values remain `[UNVALIDATED]` IHAP-55 work. PRECISION-01 does establish that the tested OLED+BME280 prototype path operates concurrently on GPIO6/GPIO7.

Reference internal harness target: <=150 mm from board to each I2C module. Longer routing requires explicit integrated evidence. Final exact cut lengths belong to IHAP-51.

### 6.2 DHT11

Accepted reference contract:

- supply = `SYS_3V3`;
- data = GPIO4;
- provide a board pull-up footprint targeting an effective value around **5.1 kOhm to `SYS_3V3`**;
- if the selected three-pin breakout already contains a pull-up, final population must avoid an unnecessarily strong parallel network;
- provide local 100 nF decoupling at the environment interface unless the final schematic demonstrates an equivalent local decoupling path.

The owned DHT11 path passed STANDARD-11 at 3.3 V. Exact onboard pull-up value on the selected breakout and exact final board population remain `[UNVALIDATED]` until measured/identified by IHAP-55.

### 6.3 MC-38 reed input

**Accepted IHAP-50 reference topology:**

```text
SYS_3V3
   |
  10k
   |
DOOR_SENSE ---- 1k series ---- ESP32-C3 GPIO3
   |
 reed contact
   |
  GND
```

Accepted passives/rules:

- `R_DOOR_PULLUP = 10 kOhm` to `SYS_3V3`;
- `R_DOOR_SERIES = 1 kOhm` close to the MCU input;
- `C_DOOR_FILTER = 100 nF` footprint, **DNP by default**; population later requires evidence of a concrete noise/bounce need.

STANDARD-11 physically demonstrated FAR/open -> HIGH (`1,1`), NEAR/closed -> LOW (`0,0`), and one interrupted conductor -> HIGH (`1,1`). An interrupted conductor therefore remains indistinguishable from a legitimate open contact. No fault/tamper state is introduced.

### 6.4 LD2410C UART

Accepted runtime/reference path:

- supply = regulated `SYS_5V`;
- common ground mandatory;
- module TX -> GPIO0;
- baud = 256000;
- GPIO1 -> module RX only as service/configuration reservation, disabled by default;
- module `OUT` unallocated.

STANDARD-11 and PRECISION-01 demonstrated fresh valid receive frames with zero parsed invalid frames on the tested specimen. Replacement electrical equivalence remains `[UNVALIDATED]` until a replacement profile is reviewed.

---

## 7. Accepted connector strategy

The owned `PH2.0`-labelled kit remains acceptable **prototype inventory**, but the generic label is not a controlled manufacturer series and does not prove universal mating compatibility.

The Accepted final-reference rule is to use keyed/polarized low-voltage detachable interfaces. For a PH2.0-style family to become the final PCB implementation, IHAP-55 must freeze:

- exact board header/footprint;
- mating housing/contact;
- pitch and orientation;
- polarity/keying;
- current capability for the connected module;
- crimp/assembly method;
- replacement source.

Accepted interface classes:

| Connection | Accepted class | Rationale |
|---|---|---|
| Radar | keyed/polarized 4-position low-voltage connector | Carries 5 V + UART. |
| OLED | keyed/polarized 4-position low-voltage connector | Front-panel/serviceable module. |
| Environment | keyed/polarized 5-position low-voltage connector | One port supports either accepted environmental profile. |
| Door | keyed/polarized 2-position connector; terminal-block fallback only if IHAP-51 demonstrates a serviceability need | Passive field-mounted cable. |

Wire color must never encode the only polarity information.

---

## 8. Accepted wire and harness rules

### Validation/development

- Dupont permitted only on the bench;
- keep runs short and visible;
- remove power before rewiring;
- follow net/pin labels rather than breadboard row memory or cable colors.

### Reference PCB harness

Accepted design range/rules:

- stranded copper;
- 26–28 AWG for short module harnesses, subject to the selected connector contact specification;
- prefer 26 AWG for radar 5 V/GND where the chosen contact supports it;
- exact conductor gauge must remain compatible with connector crimp range and measured load;
- internal module harness target <=150 mm unless IHAP-51 geometry requires more;
- final exact cut lengths remain `[UNVALIDATED]` until PCB connector placement and enclosure geometry are frozen.

Every harness leaving the PCB must receive mechanical strain relief. Solder joints alone are not strain relief.

Battery-service conductors, USB-C input routing and high-current converter paths remain IHAP-55 / ADR-0007 implementation scope.

---

## 9. Logical interconnect diagram

```mermaid
flowchart LR
    USB[USB-C / power subsystem] --> SYS5[Regulated SYS_5V]
    SYS5 --> RADAR[LD2410C]
    SYS5 --> REG33[3.3 V regulator]
    REG33 --> SYS33[SYS_3V3]
    SYS33 --> MCU[ESP32-C3]
    SYS33 --> OLED[OLED]
    SYS33 --> ENV[ENV profile]
    SYS33 --> RPULL[Door pull-up]

    MCU <-->|GPIO6 SDA / GPIO7 SCL| OLED
    MCU <-->|GPIO6 SDA / GPIO7 SCL when BME280| ENV
    MCU <-->|GPIO4 when DHT11| ENV
    MCU <-->|GPIO0 RX / GPIO1 service TX reserved| RADAR
    DOOR[MC-38 reed] -->|GPIO3 DOOR_SENSE| MCU
    ADC[GPIO5 ADC-capable spare] --- MCU
    SPARE[GPIO10 digital spare] --- MCU
```

This is a logical interface view, not a PCB schematic.

---

## 10. Accepted per-node allocation model

| Item | Qty / node | Accepted rule |
|---|---:|---|
| Radar detachable interface | 1 | 4 positions |
| OLED detachable interface | 1 | 4 positions |
| Environment-profile interface | 1 | 5 positions |
| Door detachable interface | 1 | 2 positions |
| I2C pull-up footprints | 2 | required footprints; exact population after module-network reconciliation |
| DHT pull-up footprint | 1 | required footprint; profile-dependent final population |
| Environment 100 nF decoupling | 1 | unless equivalent local decoupling is demonstrated |
| Door 10 kOhm pull-up | 1 | populated reference baseline |
| Door 1 kOhm series resistor | 1 | populated reference baseline |
| Door 100 nF filter footprint | 1 | DNP by default |
| Audio interface/passives | 0 | outside reference MVP |
| Breadboard | 0 final; optional bench | development only |
| Dupont wiring | 0 final; as needed bench | development only |

IHAP-17 receives these Accepted logical quantities but must cost exact selected/populated parts only after IHAP-55 freezes manufacturer parts and final population. Bulk-kit acquisition cost must not be divided arbitrarily over unused stock.

---

## 11. Accepted integrated validation evidence

IHAP-50 closure evidence is complete for its own scope.

### 11.1 `IHAP50-STANDARD-11` — PASS

Accepted evidence demonstrates:

- normal boot/reset through the corrected ESP32-C3 USB Serial/JTAG validation path;
- exact canonical pin map;
- GPIO5 ADC-spare and GPIO10 digital-spare pull tests PASS;
- BME280 absent as required by STANDARD;
- OLED stable with operator visual gate confirmed;
- DHT11 valid on GPIO4;
- LD2410C fresh on GPIO0 at 256000 baud with valid frames and zero parsed invalid frames;
- MC-38 OPEN/FAR `1,1`, CLOSED/NEAR `0,0`, disconnected conductor `1,1`;
- OLED and radar remained alive during all MC-38 phases;
- connector polarity/pin-order operator review confirmed.

### 11.2 `IHAP50-PRECISION-01` — PASS

Accepted evidence demonstrates:

- exact canonical pin map and spare checks remain valid;
- DHT11 absent as intended;
- BME280 detected at `0x76`, identity `0x60`, reliable across all six accepted baseline samples;
- OLED remains operational concurrently on shared GPIO6/GPIO7 I2C;
- LD2410C remains fresh with valid frames and zero parsed invalid frames;
- GPIO1 service TX remains disabled.

### 11.3 Gate interpretation

These runs physically validate the **tested prototype interconnect behavior** for both accepted environmental profiles. They do not validate final PCB rail quality, final pull-up population, source transfer, battery charging, thermal behavior, enclosure routing, certification or production maturity.

Quantitative power/thermal/battery/source-transfer tests remain IHAP-55 under ADR-0007. Controls explicitly remaining Proposed under IHAP-56 remain Proposed and are not converted into Accepted gates here.

---

## 12. Review findings and remediation history

### SR-50-01 — incorrect ADC capability — REMEDIATED

- **Severity:** MAJOR before remediation.
- **Initial defect:** GPIO10 was labelled `SPARE_ADC_CAPABLE`.
- **Correction:** GPIO5 is the ADC-capable spare (`ADC2_CH0`); shared I2C moved to GPIO6/GPIO7; GPIO10 remains `SPARE_DIGITAL`.
- **Regression guard:** machine-readable and human mappings agree; physical spare checks PASS.

### SR-50-02 — service TX configured by validation harness — REMEDIATED

- **Severity:** MAJOR before remediation.
- **Initial defect:** the harness attached GPIO1 as UART TX despite the accepted receive-only baseline.
- **Correction:** UART1 validation path is RX-only on GPIO0; GPIO1 is not attached to the UART peripheral.
- **Regression guard:** boot evidence emits `radar_tx_service_configured=false`; evaluator rejects enabled service TX.

### SR-50-03 — ESP32 target / USB console regression — REMEDIATED

- **Initial defect:** an early build generated `esptool --chip esp32`; ROM bootloader correctly identified the physical device as ESP32-C3. USB Serial/JTAG console was also not explicitly pinned.
- **Correction:** `firmware/sdkconfig.defaults` pins ESP32-C3 and USB Serial/JTAG. The established 3.5 s re-enumeration guard is retained as validation tooling.
- **Evidence:** board ROM/download path recovered and subsequent physical gates completed successfully.

### SR-50-04 — stale serial samples crossed operator boundaries — REMEDIATED

- **Initial defect:** samples queued while the operator changed a physical state could be attributed to the following state.
- **Correction:** the runner aborts profile mismatches, clears serial input at every confirmed acquisition boundary, and displays sequence-tagged fresh samples.
- **Evidence:** accepted STANDARD-11 phases use separated monotonic samples: OPEN seq 8/9, CLOSED 14/15, DISCONNECTED 17/18.

No threshold or accepted sensor semantic was weakened to obtain PASS.

---

## 13. Accepted ADR disposition

**ACCEPTED: ADR NOT REQUIRED.**

The architecture-significant component decisions already live in ADR-0001 through ADR-0007. IHAP-50 derives a reproducible implementation/interconnect contract from those accepted decisions. GPIO, connector and passive allocation remain reviewable implementation details that IHAP-55 may remap only with explicit compatibility evidence while preserving the Accepted IHAP-50 invariants.

A new ADR becomes necessary only if a future change introduces a stable cross-cutting architecture decision rather than merely implementing this contract.

---

## 14. Downstream handoff

### IHAP-55 receives

- Accepted canonical logical net names;
- Accepted reference GPIO allocation;
- reserved/boot/recovery policy;
- required preservation of a real ADC-capable spare;
- connector roles and logical pin order;
- Accepted I2C/DHT/reed passive **footprint and reference-value requirements**;
- UART receive/service split with service TX disabled by default;
- development-only breadboard/Dupont boundary;
- final effective pull-up reconciliation and exact connector-part freeze requirements;
- final PCB flashing/recovery, protection, power/rail and thermal validation ownership.

### IHAP-51 receives

- four external-module interface roles;
- keyed-orientation and strain-relief requirement;
- <=150 mm internal-harness design target unless geometry proves otherwise;
- final exact harness cut-length ownership;
- radar/OLED/environment/door service-access needs.

### IHAP-17 receives

- Accepted logical per-node connector/harness/passive quantities;
- zero final breadboard/Dupont allocation;
- zero audio allocation;
- exact selected connector/passive prices only after IHAP-55 freezes manufacturer parts and final population.

---

## 15. Remaining `[UNVALIDATED]` after IHAP-50 acceptance

The following are intentionally **not** converted to Accepted implementation evidence by PO approval of IHAP-50:

- exact effective I2C pull-up resistance/rise time and final PCB pull-up population;
- DHT breakout onboard pull-up value and final PCB pull-up population;
- exact connector manufacturer/series/SKU/mating compatibility/footprints;
- final harness cut lengths and enclosure routing;
- final custom-PCB flashing/recovery behavior on its chosen MCU implementation;
- custom-PCB electrical protection, rail quality, thermal behavior and source transfer;
- replacement-lot equivalence for low-cost sensor modules;
- production reliability, certification and commercial readiness.

These are downstream implementation evidence gates, not reasons to reopen the Accepted IHAP-50 contract.

---

## 16. Merge gate

Project Owner acceptance is complete. PR #36 must remain unmerged until **Codex review** has been received and all material findings are resolved on the same IHAP-50 branch/PR. If a Codex remediation changes any Accepted contract item above, the impact must be surfaced before merge rather than silently changing the accepted baseline.

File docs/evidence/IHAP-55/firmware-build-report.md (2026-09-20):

# IHAP-55 firmware build evidence — 2026-09-12

Input baseline HEAD `f5c94a2429f27e88161305896eb5fb85566dd636` plus the firmware changes now committed as `fc5a591`. Tool: ESP-IDF v6.0.1, target `esp32c3`, 4 MB flash setting, native USB Serial/JTAG console.

Commands executed in `tools/hardware-validation/ihap-55-mainboard/firmware/`:

```bash
source $HOME/.espressif/v6.0.1/esp-idf/export.sh
idf.py set-target esp32c3
idf.py build
```

Final `set-target` exit **0**; final `build` exit **0** after the strict command parser was added. Build output: `build/ihap55_mainboard_harness.bin`, 0x2f2b0 bytes, 82% free in the 1 MiB app partition. SHA-256: `ec8a64470fe3e4f7530396b94b21ac02013639e6a880701db5c58ea989aa0c10`. Generated build/sdkconfig are ignored by Git.

Reviewer rerun on 2026-09-13: `idf.py build` exit **0** with no source changes to firmware since `fc5a591`; the generated app descriptor identified the then-current worktree as `30569eb-dirty`, so the new binary hash is `f3b068ca9f683904bfab1e8e34f54803bccae7cb03ca96ffa9fda91e3df3671e` while size remains 0x2f2b0. Binary hashes are tied to the exact Git-derived app descriptor, not a stable firmware-source-only fingerprint.

The first build failed with `-Werror=misleading-indentation` in the pre-existing compact `health_adc.c`; it was reformatted and rebuilt successfully. IHAP-55 now initializes the TLA2024 on I2C, reads all four channels on command, includes rail validity in a terminal JSON `board_self_test`, preserves the IHAP-50 integrated sample stream, and serializes DHT access between tasks. Host evaluator tests passed 12/12 after fail-closed checks were tightened.

**PASS — firmware build only.** USB command reception, real ADC accuracy, sensor/connector function and GPIO electrical behavior on a fabricated mainboard remain `[UNVALIDATED]`. The firmware's rail thresholds are diagnostic, not calibrated proof of the accepted power contract.

## Current rerun — 2026-09-20

Input HEAD: `d070e5aacbeaebc5a7ab6da1edd006adfdf7a238`.

From `tools/hardware-validation/ihap-55-mainboard/firmware/`:

```bash
source /home/optimus/.espressif/v6.0.1/esp-idf/export.sh
idf.py build
```

ESP-IDF v6.0.1 / ESP32-C3 build exit **0**. The generated binary is `build/ihap55_mainboard_harness.bin`, size `0x2f2b0` bytes, with `0xd0d50` bytes (82%) free in the 1 MiB app partition. SHA-256:

```text
c73862b0a59d0d45a34df8a4ecb8afb5b983541fb05b7bae12fc28192bc8964c
```

**PASS — firmware build only.** No board was flashed or physically exercised; USB, TLA2024, rail accuracy, connector behavior and sensor checks remain `[UNVALIDATED]`.

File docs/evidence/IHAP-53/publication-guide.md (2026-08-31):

# IHAP-53 Validated Evidence Publication Guide

**Issue:** IHAP-53 — Local Display Decision — 0.96-inch OLED vs No Display  
**Purpose:** define exactly how a completed local validation run is promoted from ignored raw laboratory evidence into reviewed repository evidence.

## Source / publication boundary

Raw run data remains local under:

```text
tools/hardware-validation/ihap-53-local-display/runs/<RUN-ID>/
```

That directory is intentionally ignored by Git. Do **not** remove the ignore rule and do **not** use `git add -f` to publish the raw run.

Reviewed evidence for a validated run is published under:

```text
docs/evidence/IHAP-53/<RUN-ID>/
```

For the accepted physical run:

```text
docs/evidence/IHAP-53/IHAP53-DISPLAY-01/
```

## Publishable files for IHAP53-DISPLAY-01

Create this repository-visible structure:

```text
docs/evidence/IHAP-53/IHAP53-DISPLAY-01/
├── run-record.md
├── photo-front-text-card.png
├── photo-rear-marking.png
└── photo-wiring-annotated.png
```

### `run-record.md`

Use the completed reviewed run record derived from the local run. It must contain the physical PASS/FAIL classification, exact tested commit/toolchain, observed address, stability result, controlled reboot result, anomalies and claim boundary.

Do not publish workstation paths, usernames, credentials, SSIDs, MAC addresses, unique chip identifiers or other unnecessary host-specific data.

### Photographs

Only real photographs of the tested specimen may be evidence. Permitted transformations are non-semantic:

- crop;
- rotation/orientation normalization;
- standard PNG/JPEG conversion;
- light exposure/contrast/sharpness normalization that does not alter technical details;
- EXIF/metadata removal;
- explanatory arrows/labels on a supplemental wiring image, provided the underlying photograph remains real and the annotation does not invent or obscure evidence.

Do not use generatively reconstructed or AI-redrawn component images as validation evidence.

Required publication images for this run:

- `photo-front-text-card.png` — real tested display showing the readable `HOMEEDGE` / `IHAP53` card;
- `photo-rear-marking.png` — real rear PCB showing `GME12864-11-12-13 V3.22` and the I2C address-select markings;
- `photo-wiring-annotated.png` — supplemental real-photo wiring evidence documenting black = GND, red = 3.3 V, orange = SCL, yellow = SDA.

## Raw `serial.log`

The complete `serial.log` remains in the ignored local run by default. Do not copy the raw monitor stream into Git merely to make it visible.

The reviewed `run-record.md` records the evidence-derived facts needed for repository review, including:

- `0x3C` ACK and `0x3D` no-ACK;
- SSD1306 initialization-profile transfer PASS;
- visual transfer sequence PASS plus operator visual confirmation;
- heartbeat at/after 3600 seconds;
- highest accepted pre-reset `elapsed_s`;
- absence/presence of I2C errors, brownout and unexpected resets;
- controlled reboot/reinitialization result;
- non-invalidating host-monitor anomalies.

Retain the raw local log unchanged for audit/re-review.

## Copy workflow

From repository root, after reviewing the local evidence:

```bash
mkdir -p docs/evidence/IHAP-53/IHAP53-DISPLAY-01

cp tools/hardware-validation/ihap-53-local-display/runs/IHAP53-DISPLAY-01/run-record.md \
  docs/evidence/IHAP-53/IHAP53-DISPLAY-01/run-record.md
```

Copy the three sanitized image files into the same publication directory using the exact names above.

Then verify:

```bash
git status --short
```

Expected repository-visible additions are the reviewed `run-record.md` and the three sanitized PNG files under `docs/evidence/IHAP-53/IHAP53-DISPLAY-01/`. Files under `tools/hardware-validation/ihap-53-local-display/runs/` should remain ignored.

Before staging, verify that the published record and images contain no prohibited metadata or private host information.

## Staging

Stage only the reviewed publication package and related canonical documentation changes:

```bash
git add docs/evidence/IHAP-53/IHAP53-DISPLAY-01/
git add docs/evidence/IHAP-53/publication-guide.md
```

Do not stage `tools/hardware-validation/ihap-53-local-display/runs/`.

`IHAP53-DISPLAY-01` is physically validated PASS. Publication of PASS evidence did not itself accept ADR-0004; architectural acceptance was recorded separately by the Project Owner on 2026-08-31 after evidence review and final specialist review.

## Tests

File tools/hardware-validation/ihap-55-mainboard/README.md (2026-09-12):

# IHAP-55 mainboard validation harness

## Pre-fabrication

```bash
python3 host/ihap55_contract_check.py
python3 host/ihap55_sim.py
python3 -m unittest discover -s host/tests -v
```

Current local result (2026-09-12): contract PASS, 28/28 behavioral corner-screen cases PASS, 12 unit tests PASS. The screen does not establish physical rail behavior.

## Fabricated board

```bash
python3 -m pip install -r host/requirements.txt
python3 host/ihap55_board_test.py --port /dev/ttyACM0 --profile standard
python3 host/ihap55_board_test.py --port /dev/ttyACM0 --profile precision
```

The physical runner is independent from simulation: a simulated PASS cannot satisfy a fabricated-board gate.

## Firmware lineage

Reuse/port the already validated IHAP-50 code for DHT11, BME280, OLED, LD2410C, door and spare-pin checks. Add TLA2024 rail-health reads plus the JSON command protocol in `docs/evidence/IHAP-55/board-self-test-protocol.md`. Until the IHAP-55 board firmware builds against the selected ESP-IDF revision, firmware build remains `[UNVALIDATED]`.

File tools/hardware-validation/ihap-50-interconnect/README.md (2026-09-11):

# IHAP-50 — Integrated Interconnect Validation

**Issue:** IHAP-50 — Interconnect and Prototype Assembly Decision  
**Purpose:** reproducible physical gate for the **Accepted** IHAP-50 reference interconnect contract  
**Status:** validation complete — `IHAP50-STANDARD-11` PASS + `IHAP50-PRECISION-01` PASS; retained as regression/reproduction runbook  
**Scope:** validation harness only; not product firmware, final PCB validation, or power-subsystem validation

## 1. What this gate proves

This harness physically validated the IHAP-50 prototype implementation of the Accepted contract:

- the Accepted ESP32-C3 pin allocation boots and remains recoverable;
- GPIO5 remains usable as the ADC-capable engineering spare and GPIO10 as a digital spare;
- OLED works on shared I2C GPIO6/GPIO7;
- BME280 coexists with the OLED in the precision environmental profile;
- DHT11 works on GPIO4 in the standard environmental profile;
- LD2410C frames are received on GPIO0 at 256000 baud while GPIO1 service TX remains disabled;
- MC-38 produces HIGH/open, LOW/closed, and HIGH again with one conductor disconnected;
- connector pin order and polarity were explicitly reviewed by the operator.

Accepted evidence is published under `docs/evidence/IHAP-50/`. This harness does **not** validate final PCB rail quality, source transfer, battery, charging, thermal behavior, enclosure, production reliability, or certification. Those remain downstream work.

## 2. Accepted reference pin map

| Function | ESP32-C3 pin | Rule |
|---|---:|---|
| LD2410C TX -> MCU RX | GPIO0 | UART1 RX, 256000 baud |
| LD2410C RX service line | GPIO1 | service-only physical reservation; disabled by default and disconnected for this gate |
| MC-38 door sense | GPIO3 | Accepted external pull network required |
| DHT11 data | GPIO4 | standard profile only |
| ADC engineering spare | GPIO5 | leave externally unconnected |
| I2C SDA | GPIO6 | OLED + optional BME280 |
| I2C SCL | GPIO7 | OLED + optional BME280 |
| Digital engineering spare | GPIO10 | leave externally unconnected |

Do not use GPIO2, GPIO8 or GPIO9. Keep GPIO20/GPIO21 free for recovery/UART0 when practical.

## 3. Common wiring

**Disconnect USB/power before changing wiring.** Use module pin labels, not wire colors.

### LD2410C

```text
LD2410C VCC -> ESP32-C3 5V
LD2410C GND -> common GND
LD2410C TX  -> GPIO0
LD2410C RX  -> DISCONNECTED
LD2410C OUT -> DISCONNECTED
```

GPIO1 is reserved by the Accepted interconnect contract for a controlled service TX path, but the IHAP-50 validation firmware intentionally does not configure a UART TX pin.

### OLED

```text
OLED GND -> common GND
OLED VCC -> 3.3V
OLED SCL -> GPIO7
OLED SDA -> GPIO6
```

The accepted owned display is expected at I2C address `0x3C`.

### MC-38

Validate the **Accepted IHAP-50 prototype network** rather than silently relying on an MCU internal pull-up:

```text
3.3V
 |
10k
 |
DOOR_SENSE ---- 1k ---- GPIO3
 |
MC-38
 |
GND
```

The optional 100 nF filter footprint is **DNP by default**. Its future population requires integrated noise/bounce evidence; approval of IHAP-50 does not assert that it is populated.

Expected states:

- magnet FAR / contact open -> `door_raw = 1`;
- magnet NEAR / contact closed -> `door_raw = 0`;
- one MC-38 conductor disconnected -> `door_raw = 1`.

The last condition demonstrates the accepted limitation that the simple MVP topology cannot distinguish a legitimate open contact from an interrupted wire.

## 4. Environmental profiles

The two accepted environmental profiles are alternatives. Do **not** mount DHT11 and BME280 together just to satisfy this test.

### Standard profile

Connect the owned DHT11 breakout:

```text
DHT11 +   -> 3.3V
DHT11 OUT -> GPIO4
DHT11 -   -> GND
```

Use the breakout's existing pull-up only if it is already present/known from the previously validated fixture. Do not add a second strong parallel pull-up blindly. The Accepted contract requires a board pull-up footprint targeting an effective ~5.1 kOhm; **final population remains IHAP-55 scope** after the effective module network is measured/identified.

The BME280 must be disconnected for this profile.

### Precision profile

Disconnect the DHT11 and connect the accepted BME280 profile:

```text
BME280 VIN -> 3.3V
BME280 GND -> common GND
BME280 SDA -> GPIO6
BME280 SCL -> GPIO7
```

OLED and BME280 share the same I2C bus. The accepted specimen is expected at `0x76` with chip ID `0x60`.

The I2C validation firmware disables MCU internal pull-ups. Pull-ups supplied by the selected modules/prototype network therefore remain part of the actual physical path under test. The Accepted IHAP-50 contract requires I2C pull-up footprints with 4.7 kOhm as the candidate value; **final population/effective resistance remains IHAP-55 `[UNVALIDATED]` scope**.

## 5. Prepare the branch

```bash
git fetch origin
git switch ihap-50-interconnect-prototype-assembly
git pull --ff-only
git status
git rev-parse HEAD
```

Record the exact HEAD SHA. The runner requires it explicitly and stores it in local evidence.

## 6. Host tests

From repository root:

```bash
cd tools/hardware-validation/ihap-50-interconnect
python3 -m venv .venv
source .venv/bin/activate
python -m pip install -r host/requirements.txt
python -m unittest discover -s host/tests -v
```

All evaluator tests must pass before any reproduction/regression acquisition.

## 7. Build and flash

Use the project ESP-IDF environment and the ESP32-C3 target:

```bash
cd firmware
rm -rf build sdkconfig sdkconfig.old
idf.py set-target esp32c3
idf.py build
idf.py -p /dev/ttyACM0 flash
cd ..
```

`firmware/sdkconfig.defaults` pins `CONFIG_IDF_TARGET="esp32c3"` and the USB Serial/JTAG console as a regression guard from SR-50-03. The generated flash command must target `--chip esp32c3`.

Do not run `idf.py monitor` while the Python runner owns the serial port. If your device path differs, use the actual `/dev/ttyACM*` path consistently.

## 8. STANDARD profile reproduction

Canonical accepted evidence: **`IHAP50-STANDARD-11` — PASS**. Do not overwrite or reuse that run ID.

For a future regression/reproduction run, wire the common devices + DHT11 and keep BME280 disconnected. Use a new unique run ID:

```bash
HEAD_SHA="$(git rev-parse HEAD)"
python host/ihap50_run.py \
  --port /dev/ttyACM0 \
  --profile standard \
  --run-id IHAP50-STANDARD-<NEW-ID> \
  --commit "$HEAD_SHA"
```

The runner:

1. requires connector/polarity confirmation;
2. asks for one controlled `RST`;
3. verifies the exact pin map and spare-pin checks;
4. requires GPIO1 service TX to be disabled;
5. asks whether the OLED visibly flashed full-on for about one second at boot;
6. clears pre-condition serial input and collects six fresh baseline samples;
7. guides MC-38 FAR, NEAR and disconnected-wire phases, clearing queued samples at every confirmed boundary;
8. displays sequence numbers and generates local `summary.json`, `summary.md`, and raw `serial.log`.

Restore the disconnected MC-38 conductor after the test.

## 9. PRECISION profile reproduction

Canonical accepted evidence: **`IHAP50-PRECISION-01` — PASS**. Do not overwrite or reuse that run ID.

Power off, disconnect DHT11, connect BME280 to the shared OLED I2C bus, then use a new unique run ID:

```bash
HEAD_SHA="$(git rev-parse HEAD)"
python host/ihap50_run.py \
  --port /dev/ttyACM0 \
  --profile precision \
  --run-id IHAP50-PRECISION-<NEW-ID> \
  --commit "$HEAD_SHA"
```

The precision profile does not repeat the MC-38 phases. Accepted STANDARD-11 already supplies that physical evidence.

## 10. Automatic PASS criteria

Common:

- exact boot pin map;
- GPIO5 ADC-spare pull test PASS;
- GPIO10 digital-spare pull test PASS;
- radar service TX not configured;
- requested and detected environmental profile must match or the runner aborts before sampling;
- OLED visual transfer command PASS plus operator visual confirmation;
- OLED communication success in >=80% of baseline samples;
- radar fresh in >=75% of baseline samples;
- at least one valid LD2410C frame;
- zero parsed invalid LD2410C frames in the run baseline.

Standard:

- BME280 absent;
- DHT11 valid in >=75% of baseline samples;
- MC-38 FAR = 1 for both fresh phase samples;
- MC-38 NEAR = 0 for both fresh phase samples;
- one conductor disconnected = 1 for both fresh phase samples;
- OLED and radar remain alive during each door phase.

Precision:

- BME280 present at `0x76`;
- BME280 chip ID `0x60` in every collected baseline sample;
- BME280 communication success in >=80% of baseline samples;
- DHT11 result is ignored because DHT11 is intentionally absent.

Any failed criterion returns process exit code `2`; PASS returns `0`.

## 11. Accepted evidence and local raw data

Accepted curated evidence:

```text
docs/evidence/IHAP-50/IHAP50-STANDARD-11-summary.md
docs/evidence/IHAP-50/IHAP50-STANDARD-11-summary.json
docs/evidence/IHAP-50/IHAP50-PRECISION-01-summary.md
docs/evidence/IHAP-50/IHAP50-PRECISION-01-summary.json
```

Future/local runs are written below:

```text
tools/hardware-validation/ihap-50-interconnect/runs/<RUN-ID>/
```

That directory is ignored by Git. Raw serial output stays local by default. Do not commit raw serial logs automatically.

## 12. Stop conditions

Stop and correct wiring rather than weakening the gate if any of these occur:

- brownout/reset loop;
- OLED not found at the expected accepted address;
- unexpected BME280 presence in the standard profile;
- BME280 missing/wrong identity in the precision profile;
- radar frames invalid or absent;
- GPIO5/GPIO10 spare check failure;
- door state unstable or opposite to the accepted semantics;
- visible heating, smell, damaged insulation, or uncertain polarity.

Do not turn a failed physical result into a documentation PASS. Preserve the failure and remediate the actual cause.

## 13. Scope boundary after acceptance

IHAP-50 acceptance freezes the logical/reference interconnect contract and the physically validated prototype behavior. It **does not** promote the separately Proposed IHAP-56 strengthening, and it does not validate the final PCB, exact connector manufacturer/SKU/footprint, effective final pull-up population, enclosure harness lengths, power/source-transfer/thermal behavior, certification, production reliability or commercial readiness. Those remain downstream gates.

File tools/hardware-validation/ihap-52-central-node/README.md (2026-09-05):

# IHAP-52 Central Node Hardware Validation Harness

## Goal

Validate the bounded HomeEdge central-node hardware profile with the same operating model used for the mature IHAP-46/IHAP-47 hardware campaigns: one guided entrypoint, automatic gates, deterministic evidence, no manual command-by-command interpretation.

Reference profile:

- Raspberry Pi 4 Model B;
- >=4 GB RAM;
- nominal 32 GB or larger microSD;
- application class **A1 or A2** accepted;
- A2 recommended for new purchases/reference replication;
- Raspberry Pi OS Lite 64-bit;
- Wi-Fi required;
- Ethernet optional;
- approximately 5 V PSU rated >=2.5 A for the bounded low-USB-load run;
- 5.1 V / 3 A recommended reference PSU;
- cooling/enclosure recorded exactly as tested.

This validates hardware/resource stability only. Final HomeEdge workload sufficiency, microSD endurance/retention, Docker/container behavior and AI acceleration remain `[UNVALIDATED]`.

## Fast path

### 1. Self-test

```bash
python3 -m unittest discover \
  -s tools/hardware-validation/ihap-52-central-node/tests \
  -p 'test_*.py' -v
```

### 2. Pre-flight only

```bash
python3 tools/hardware-validation/ihap-52-central-node/validate_central_node.py --guided --dry-run
```

The operator supplies only facts Linux cannot prove directly: microSD application class, Raspberry Pi OS Lite 64-bit Imager selection, optional card model, PSU rating, case/cooling and ambient temperature.

For the Pi 4 reference profile, `A1` and `A2` are accepted application classes. A2 remains the recommended replication class.

The PSU rating is an actual gate. Raspberry Pi documents 5 V / 3 A as the normal Pi 4 requirement and permits a good-quality 2.5 A supply where downstream USB load remains below 500 mA. IHAP-52 therefore accepts >=2.5 A only for this bounded low-peripheral run and recommends 5.1 V / 3 A for reference replication.

A 5 V / 1.55 A supply is below the accepted validation envelope and must not proceed to the stress phase.

### 3. Canonical physical run

Only after `PRE-FLIGHT PASS`:

```bash
python3 tools/hardware-validation/ihap-52-central-node/validate_central_node.py --guided
```

Default workload:

- 128 MiB deterministic storage write/read test with SHA-256 comparison;
- 300 seconds CPU stress;
- automatic worker, boot, OOM and `vcgencmd` post-run gates.

## Automatic pre-flight gates

- supported 64-bit architecture;
- >=4 logical CPUs;
- >=4 GB RAM;
- root filesystem capacity compatible with nominal 32 GB media;
- active Wi-Fi with an IP address;
- repository commit recorded and clean worktree;
- Pi 4 model/ARM64 for the reference profile;
- `vcgencmd` available;
- no current or historical Pi undervoltage/throttling flags;
- microSD application class A1/A2;
- Raspberry Pi OS Lite 64-bit operator confirmation;
- parseable and supported PSU rating.

GPU/render exposure is collected as observation only and is not an MVP PASS gate.

## Outputs

```text
runs/<run-id>/
├── operator-notes.md
├── validation.json
└── validation.md
```

Every run gets a unique directory. Previous attempts are never overwritten.

## Current Raspberry Pi OS note

Current Raspberry Pi OS Lite 64-bit is Debian-based. Seeing `Debian GNU/Linux 13 (trixie)` in `/etc/os-release` is compatible with the current Raspberry Pi OS Lite release when the operator confirms the Imager selection.

A `--dry-run` does not execute CPU stress, so `Max observed CPU temperature: not reported` is expected there.

## Privacy

Raw runs remain local and ignored by Git. Before publishing any sanitized summary, remove hostname, username, SSID, private IP, MAC address and credentials.

## Exit codes

- `0`: all applicable mandatory gates passed;
- `2`: at least one mandatory gate failed;
- other non-zero: execution/configuration error.

See [`QUICKSTART.md`](QUICKSTART.md) for the shortest operator command sequence and [`docs/evidence/IHAP-52/central-node-validation-plan.md`](../../../docs/evidence/IHAP-52/central-node-validation-plan.md) for the canonical runbook.

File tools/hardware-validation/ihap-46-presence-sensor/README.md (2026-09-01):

# IHAP-46 — Presence Sensor Physical Validation

This package executes reproducible physical tests on the owned LD2410C specimen and, when an identified PIR specimen is available, performs a controlled comparison.

The test does not rely on an informal observation that the sensor “seems to work.” Every run records the physical specimen, room geometry, mounting position, operator action, duration, ground truth, received data, reset history, and invalidating events.

The guided runtime prints the required action on screen, creates ground-truth markers automatically, and generates the evidence package.

<!--
AI_AGENT_METADATA:
  issue: IHAP-46
  artifact_role: reproducible_physical_test_harness
  human_entrypoint: README.md
  detailed_human_procedure: docs/operator-test-procedure.md
  runtime_entrypoint: host/guided_run_strict.py
  numerical_test_plan: config/test-plan.json
  operator_action_source: config/operator-actions.json
  default_environment_source: config/default-environment.json
  physical_specimen_evidence: ../../../docs/evidence/IHAP-46/README.md
  raw_runs_default_location: runs/
  production_event_boundary: presence_detected_boolean_only
  detailed_radar_fields: laboratory_evidence_only
  decisions_allowed_here: none

HIDDEN_AGENT_RULES:
  - Do not treat harness creation or one successful run as sensor acceptance.
  - Do not create or accept an ADR from raw observations without Project Owner decision.
  - Do not move detailed radar telemetry into the MVP event contract.
  - Do not commit raw runs by default; publish only reviewed, sanitized evidence.
  - New practical risks remain observations until the Project Owner approves risk-record work.
  - IHAP-49 owns quantitative power evidence.
  - IHAP-50 owns final wiring.
  - IHAP-51 owns enclosure and production placement constraints.
-->

## Owned LD2410C specimen

The Project Owner supplied component-side and antenna-side photographs of one owned specimen.

The visible markings identify:

- module label `HLK-LD2410C`;
- PCB revision `V1.1`;
- antenna-side pin labels `TX`, `RX`, `OUT`, `GND`, `VCC`.

The sanitized photographs, provenance, checksums, supported observations, and limitations are recorded in [`docs/evidence/IHAP-46/`](../../../docs/evidence/IHAP-46/README.md).

The photographs identify the physical labels of this specimen. They do not validate signal voltage, power behavior, UART operation, detection quality, or suitability for the MVP.

## Default physical environment

The default experiment profile is stored in [`config/default-environment.json`](config/default-environment.json).

It defines:

- square room: **5.00 m × 5.00 m**;
- door: **near one corner** of the mounting wall;
- sensor height: **2.00 m above the floor**;
- sensor position: **attached to the wall immediately above the door opening**;
- sensor orientation: **board parallel to the wall, antenna side facing into the room**.

The runtime displays these values before the run. Pressing Enter accepts a default. Typing another value records a correction in the evidence.

The profile also defines relative reference points:

- 1.00 m inside the doorway on the sensor centreline;
- geometric room centre;
- 0.50 m from the wall opposite the door on the sensor centreline;
- a lateral path through the room centre;
- a fixed seated point at the room centre unless corrected.

Exact door width, offset from the nearest corner, ceiling height, furniture layout, adjacent-space geometry, and moving objects remain run-specific and must be corrected in the metadata when known.

## Breadboard wiring for the first validation

Disconnect USB power before changing the wiring.

Use the labels printed on the photographed antenna side to identify the pins. The initial validation uses receive-only UART:

```text
LD2410C VCC -> ESP32-C3 5 V
LD2410C GND -> ESP32-C3 GND
LD2410C TX  -> ESP32-C3 GPIO5
```

Do not connect these pins during the first run:

```text
ESP32-C3 TX -> LD2410C RX
LD2410C OUT -> ESP32-C3 GPIO
PIR OUT     -> ESP32-C3 GPIO
```

The shared ground is mandatory. The photographed pin labels do not establish logic-level safety. RX, OUT, and PIR paths remain disabled until their levels are verified.

## Clone the pull request

```bash
git clone https://github.com/pianic2/homeedge-ai-platform.git
cd homeedge-ai-platform
git fetch origin pull/25/head:ihap-46-validation
git switch ihap-46-validation
cd tools/hardware-validation/ihap-46-presence-sensor
```

Confirm the checked-out commit before testing:

```bash
git status
git rev-parse HEAD
```

Record the commit SHA with the run evidence.

## Build and flash the firmware

Use ESP-IDF **6.0.1** for the reference run. A different ESP-IDF 6.x version is a test deviation and must be recorded.

Activate ESP-IDF, then run:

```bash
cd firmware
idf.py set-target esp32c3
idf.py menuconfig
idf.py build
idf.py -p /dev/ttyACM0 flash
cd ..
```

The default firmware configuration reads LD2410C UART on ESP32-C3 GPIO5 at 256000 baud and emits newline-delimited JSON on the USB serial console at 115200 baud.

## Prepare the host runtime

```bash
python -m venv .venv
source .venv/bin/activate
python -m pip install -r host/requirements.txt
python -m unittest discover -s tests -v
```

Preview the default environment and residual operator actions without opening the serial port:

```bash
python host/guided_run_strict.py --dry-run
```

Preview one scenario before physical execution:

```bash
python host/guided_run_strict.py \
  --dry-run \
  --scenario SEATED_STILL
```

## Retained lean decision plan

The physical decision campaign is complete. Reviewed evidence covers controlled
empty-room, moving-person, stationary-person, release and adjacent-path behavior.
Do not repeat any scenario without a new evidence-driven reason.

These were the four residual scenarios and remain in the canonical plan only
for exact reproducibility:

| Scenario | Duration × repetitions | Decision question |
|---|---:|---|
| `SEATED_STILL` | 300 s × 1 | Does the owned specimen retain substantially stationary presence? |
| `EXIT_CLEAR` | 60 s × 3 | Does it return to clear within 10 s of `START NOW`, including normal exit travel? |
| `ADJACENT_DOOR_CLOSED` | 120 s × 1 | Does closed-door adjacent movement remain outside the room state? |
| `ADJACENT_DOOR_OPEN` | 120 s × 1 | What limitation appears with an open doorway? |

Their total controlled acquisition time is 12 minutes. The runner performs
precondition gates, timestamps, repetition counting, classification,
aggregation, and report generation automatically.

For `EXIT_CLEAR`, the ground-truth marker and clear-latency clock begin exactly
at `START NOW`. The operator must begin leaving immediately at that signal.
Waiting after the signal contaminates the release metric and makes the
threshold result invalid even when the serial acquisition itself is valid.

Mount the sensor in the documented position before starting. Execute one
scenario at a time so each result can be reviewed before proceeding:

```bash
python host/guided_run_strict.py \
  --port /dev/ttyACM0 \
  --run-id IHAP46-LD2410C-STILL-01 \
  --sensor ld2410c_uart \
  --scenario SEATED_STILL
```

The runtime:

1. displays the default room and mounting profile;
2. accepts or corrects the effective values;
3. records operator, sensor, board, and room identifiers;
4. starts the reset-tolerant serial collector;
5. requires a valid firmware and UART pre-flight;
6. prints the exact action for each repetition;
7. waits for operator readiness;
8. enforces the scenario-specific clear or occupied start state when required;
9. starts a five-second countdown and cancels it if the precondition changes;
10. records scenario start and end automatically;
11. repeats the current action and remaining time on screen;
12. records one optional anomaly note;
13. calculates presence ratio, onset or clear latency when applicable;
14. generates machine-readable results and a human-readable report.

A second terminal is not required.

## Override defaults

Each value can be changed interactively or on the command line:

```bash
python host/guided_run_strict.py \
  --port /dev/ttyACM0 \
  --run-id IHAP46-LD2410C-CORRECTED-01 \
  --sensor ld2410c_uart \
  --room-width-m 4.80 \
  --room-depth-m 5.10 \
  --door-location "0.40 m from the west corner" \
  --mount-height-cm 198 \
  --mount-position "wall-mounted 5 cm above the door frame" \
  --mount-orientation "board parallel to wall, antenna side facing into room"
```

A separate environment file can be selected with:

```bash
--environment path/to/environment.json
```

Every effective value is saved with the run.

## Optional original scenarios

The original broader matrix remains available for later characterization, but
it is not a closure gate for IHAP-46. Optional scenarios are added explicitly:

```bash
--include-optional
```

The digital-output consistency scenario requires both:

```bash
--sensor ld2410c_uart
--sensor ld2410c_out
```

Do not enable `ld2410c_out` until the output logic level is verified. GPIO OUT,
PIR comparison hardware, reboot endurance, full placement sweeps, and
interference characterization are not required for the IHAP-46 decision gate.

## Evidence produced by each run

Each run is stored under `runs/<RUN-ID>/`:

```text
run.json                    operator, specimens, environment, and snapshots
effective-environment.json  exact room, door, mounting, and reference points
effective-test-plan.json    exact scenarios, repetitions, and thresholds
serial.log                  complete console stream
records.jsonl               parsed device records with host timestamps
marks.jsonl                 automatic ground truth and operator annotations
capture-events.jsonl        serial connection, reset, and reconnection history
results.json                machine-readable evaluation
report.html                 self-contained human-readable report
```

Do not edit a completed run. Execute a new run ID after any correction, wiring change, firmware change, mounting change, or invalid attempt.

Raw logs remain local by default. Repository evidence contains reviewed manifests, sanitized images, aggregated results, graphs, limitations, and traceability to the exact commit.

## Practical risk discovery

Physical validation may expose risks that are not visible from datasheets or static review, including:

- incorrect or ambiguous physical pin interpretation;
- unstable breadboard or jumper connections;
- reset or USB re-enumeration failures;
- false presence from the corridor, open door, wall, curtain, or fan;
- missed substantially stationary presence;
- excessive clear latency after exit;
- inconsistent UART and digital-output behavior;
- sensitivity to mounting height, orientation, furniture, or room geometry;
- configuration loss after reboot;
- unexplained invalid frames or data gaps.

Record each observation in the run annotations and report. An observation becomes a proposed project risk only after review against the existing risk catalogue and explicit Project Owner authorization.

## Boundaries

This package does not:

- select LD2410C or PIR;
- accept an ADR;
- validate quantitative power behavior;
- freeze production wiring or enclosure design;
- change the production event contract;
- authorize identity, tracking, behavioral history, alarm, intrusion-detection, safety, or security-grade claims.

The maximum production semantic remains the local non-identifying boolean
`presence_detected` state `[UNVALIDATED]`. Coordinates, trajectories, person
count, identity, behavioral profiles, persistent raw radar data, alarm state,
protection state, and occupancy guarantees are not authorized.

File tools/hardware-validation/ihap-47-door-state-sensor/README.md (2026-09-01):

# IHAP-47 Door State Sensor Validation Harness

This tool validates an owned passive wired magnetic contact for **binary electrical door-state telemetry only**.

It is a **test harness**, not production room-node firmware.

## Default workflow: low-touch guided run

The normal operator path is now intentionally simple:

1. connect the ESP32-C3 and contact;
2. start one command;
3. place the magnet FAR / NEAR when prompted;
4. during the cycle test, only move the magnet back and forth;
5. perform two explicit failure-mode setup changes;
6. keep the generated raw evidence locally.

No manual JSON entry is required.

From the harness root:

```bash
python scripts/guided_run.py \
  --port /dev/ttyACM0 \
  --specimen MC38-A
```

Default cycle count is 20 complete cycles. The runner:

- verifies FAR=`1` and NEAR=`0`;
- opens a bounded raw capture for every physical movement;
- waits for a stable target state automatically;
- counts complete cycles and mismatches;
- records raw transition counts at the firmware sampling resolution;
- records buffer overflow status;
- checks disconnected-conductor and GPIO-to-GND behavior;
- derives temporary internal-pull-up adequacy for the bench setup;
- writes `guided-result.json`;
- preserves `serial.log`, `records.jsonl`, and generated session metadata locally;
- invokes `build_report.py` after a successful run.

The operator should not type `snapshot`, `begin`, `end`, or `@observe` during the guided workflow.

## Scope

The harness supports:

- raw GPIO mapping;
- bounded high-frequency transition capture;
- automatic cycle counting;
- stable-state validation;
- disconnected-wire ambiguity observation;
- local raw evidence preservation;
- sanitized summary/report generation.

It does not:

- decide the final production GPIO;
- choose the final pull resistor;
- distinguish door open from a disconnected wire;
- implement tamper detection;
- validate mounting geometry;
- validate enclosure or cable routing;
- measure rail voltage, current or autonomy;
- make alarm, security or access-control claims.

## Responsibility split

IHAP-47 only decides whether the owned passive wired reed-contact technology is suitable for MVP binary telemetry.

- **IHAP-50** owns final GPIO, pull network, debounce and integrated electrical behavior.
- **IHAP-51** owns mounting geometry, operating gap, alignment margin and cable routing.
- **IHAP-49** owns power impact.
- **IHAP-17** owns final BOM registration.

Repeated millimetre-by-millimetre gap/alignment measurements are therefore not a blocking IHAP-47 gate.

## Directory layout

```text
ihap-47-door-state-sensor/
├── README.md
├── requirements.txt
├── firmware/
│   ├── CMakeLists.txt
│   ├── sdkconfig.defaults
│   └── main/
│       ├── CMakeLists.txt
│       └── main.c
├── scripts/
│   ├── guided_run.py
│   ├── build_report.py
│   └── capture_serial.py
└── output/
    └── .gitignore
```

## Bench wiring

```text
ESP32-C3 GPIO6 ---- passive contact ---- GND
```

The firmware enables the ESP32-C3 internal pull-up.

Expected electrical levels:

- open circuit -> `1`;
- closed circuit -> `0`.

GPIO6 is test-only. IHAP-50 owns the final pin mapping.

## Prerequisites

- ESP-IDF 6.x environment;
- Python 3.11 or newer;
- `pyserial` from `requirements.txt`;
- ESP32-C3 connected over USB;
- flashed IHAP-47 harness firmware.

## Build and flash

From `firmware/`:

```bash
idf.py set-target esp32c3
idf.py build
idf.py -p /dev/ttyACM0 flash
```

Use the actual serial port on the machine.

Do not run `idf.py monitor` while a host validation script owns the serial port.

## Guided run outputs

A guided session is created under:

```text
output/<session-id>/
```

It contains at least:

- `serial.log` — complete raw serial capture;
- `records.jsonl` — parsed firmware records;
- `operator-observations.jsonl` — observations written automatically by the runner;
- `session.json` — execution metadata;
- `guided-result.json` — machine-readable guided-run result;
- `summary.json` — generated sanitized summary after a successful run;
- `report.html` — standalone human-readable report after a successful run.

## Raw evidence rule

`output/` is ignored by Git.

Never commit raw `serial.log` or `records.jsonl`.

Before publishing selected evidence:

1. preserve the complete session directory locally;
2. inspect generated outputs;
3. remove unique identifiers, private paths and unrelated logs from publishable artifacts;
4. publish only reviewed evidence needed to support IHAP-47;
5. keep claims limited to the tested owned specimen and setup.

## Advanced/manual mode

`scripts/capture_serial.py` remains available for diagnostics and exceptional investigation.

It is **not** the default validation path and manual `@observe` JSON entry is not required for normal IHAP-47 execution.

Firmware commands remain available for troubleshooting:

```text
help
status
snapshot
begin <test_id> <specimen_id>
end
set-sample-us <250-10000>
```

## Decision boundary

A successful guided run can support these conclusions only:

- the tested owned specimen has repeatable FAR/NEAR electrical behavior;
- the temporary GPIO/pull-up bench topology reads the expected binary states;
- observed raw transition behavior is captured at the configured firmware sampling resolution;
- repeated stable movements complete without unexplained mismatch or buffer overflow;
- a disconnected conductor is electrically indistinguishable from an open contact in the simple two-wire topology.

It does **not** establish universal MC-38 behavior, production reliability, tamper detection, intrusion detection, alarm suitability or access-control suitability.

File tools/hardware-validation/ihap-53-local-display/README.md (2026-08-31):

# IHAP-53 Local Display Validation Harness

This directory contains the minimal ESP-IDF harness used to validate the owned 0.96-inch display candidate for IHAP-53.

It is **validation tooling**, not final room-node firmware and not the final IHAP-50 pinout.

## Human execution entrypoint

Do not execute a physical IHAP-53 run from abbreviated commands in this file.

The complete canonical procedure, including required hardware/software, exact checkout, wiring, ESP-IDF reference version, build/flash, serial-log capture, run IDs, visual observations, 60-minute gate, controlled reboot, evidence filenames and stop conditions is:

[`docs/evidence/IHAP-53/README.md`](../../../docs/evidence/IHAP-53/README.md)

After a run is reviewed, the exact raw-to-published evidence promotion flow is:

[`docs/evidence/IHAP-53/publication-guide.md`](../../../docs/evidence/IHAP-53/publication-guide.md)

The per-run record template is:

[`run-record-template.md`](run-record-template.md)

Raw attempts are stored locally under:

```text
runs/<RUN-ID>/
```

The `runs/` directory is ignored by Git except for its `.gitignore`; raw runs must not be committed by default. Do not remove the ignore rule and do not force-add raw run files.

## Harness behavior

The harness:

1. probes `0x3C` and `0x3D` on I2C;
2. requires exactly one candidate address;
3. applies an SSD1306 128×64 initialization profile;
4. renders full-on, full-off and checkerboard frames;
5. renders a static `HOMEEDGE` / `IHAP53` text card;
6. enters a five-second heartbeat/update loop for the one-hour stability gate;
7. emits structured serial records for review.

## Firmware source

```text
firmware/main/main.c
```

Reference ESP-IDF for the controlled physical run: **v6.0.1**.

For developer-only build verification, after activating ESP-IDF:

```bash
cd tools/hardware-validation/ihap-53-local-display/firmware
idf.py set-target esp32c3
idf.py build
```

For a controlled physical run, return to the canonical evidence/runbook file above so evidence capture is not skipped.

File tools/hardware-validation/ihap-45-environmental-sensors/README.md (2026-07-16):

# IHAP-45 Environmental Sensor Validation Harness

**Issue:** IHAP-45 — Environmental Sensor Decision — DHT11 vs DHT22 vs BME280  
**Purpose:** controlled, parallel qualification of the three owned environmental-sensor modules  
**Status:** firmware and host tooling physically exercised; staged stability gate reported passed; controlled 115-minute run ready

This directory is deliberately named `ihap-45-environmental-sensors`:

- `IHAP` matches the Jira project key;
- `environmental-sensors` avoids implying that atmospheric pressure belongs to the MVP;
- pressure acquisition is disabled and no pressure field is emitted or accepted.

The harness is validation tooling. It is not production firmware and does not freeze the final wiring owned by IHAP-50.

## 1. Test subjects

| Sensor ID | Owned module | Interface | Qualification objective |
|---|---|---|---|
| `DHT11-OWNED-01` | blue DHT11-compatible three-pin breakout | proprietary single-wire | communication stability, response, repeatability |
| `DHT22-OWNED-01` | white DHT22/AM2302-compatible three-pin breakout | proprietary single-wire | communication stability, response, repeatability |
| `BME280-OWNED-01` | purple `BME/BMP280` / `GYBMEP` four-pin breakout | I2C | address, chip identity, humidity support, response, repeatability |

The purple PCB is accepted for this owned specimen only after runtime probing:

- observed I2C address: `0x76`;
- observed chip ID: `0x60`;
- detected type: `BME280`;
- humidity supported: `true`.

BMP280-class IDs `0x58`, `0x56` and `0x57` remain rejected because humidity is unavailable.

## 2. Validation wiring

Use board silkscreen labels, not breadboard row assumptions.

| Module pin | ESP32-C3 connection | Default GPIO |
|---|---|---:|
| DHT11 `+` | `3.3V` | — |
| DHT11 `out` | digital input/output | GPIO3 |
| DHT11 `-` | `GND` | — |
| DHT22 `+` | `3.3V` | — |
| DHT22 `out` | digital input/output | GPIO4 |
| DHT22 `-` | `GND` | — |
| BME280 `VIN` | `3.3V` | — |
| BME280 `GND` | `GND` | — |
| BME280 `SDA` | I2C SDA | GPIO5 |
| BME280 `SCL` | I2C SCL | GPIO6 |

Constraints:

1. Do not use GPIO2; ADR-0001 excludes it from the conservative application profile.
2. Power all three modules from 3.3 V.
3. Use one common ground.
4. Keep the qualified pull-up and breakout configuration unchanged during comparative testing.
5. The pin allocation is a validation-harness allocation, not final product wiring.

## 3. Physical arrangement

For the comparative run:

- keep the ESP32-C3 outside the controlled enclosure when practical;
- place only the sensing modules inside;
- keep sensing elements at equivalent height and orientation;
- keep approximately equal cable lengths;
- avoid chamber walls, wet surfaces, direct airflow, direct heat and condensation;
- maintain a small gap between modules;
- do not move the sensors between phases unless the run is aborted and restarted.

Placement-induced bias remains a separate risk to be recorded under IHAP-45 and followed through IHAP-50/IHAP-51.

## 4. Prerequisites

- ESP-IDF with ESP32-C3 support;
- Python 3.11 or later recommended;
- USB data cable connected directly to the PC;
- optional independent thermo-hygrometer.

Without an independent reference, the output is a relative comparison and must not be presented as absolute accuracy validation.

Host setup:

```bash
cd tools/hardware-validation/ihap-45-environmental-sensors
python3 -m venv .venv
source .venv/bin/activate
python -m pip install -r host/requirements.txt
python -m unittest discover -s host/tests -v
```

## 5. Build and flash

```bash
cd firmware
idf.py set-target esp32c3
idf.py build
idf.py -p /dev/ttyACM0 flash
cd ..
```

Do not run `idf.py monitor` at the same time as a host capture command.

The validation firmware delays application startup after reset so Linux can recreate the ESP32-C3 native-USB serial device before one-shot metadata are emitted.

## 6. Resilient preflight

```bash
python host/ihap45_resilient.py preflight \
  --port /dev/ttyACM0 \
  --plan config/test-plan.json \
  --duration-seconds 120
```

After `Connected`, press `RST` exactly once.

The preflight requires:

- one boot metadata record;
- a successful BME280 probe with chip ID `0x60`;
- temperature and humidity channels only;
- valid samples from all three sensors;
- no pressure field;
- no repeated boot.

An initial integrated preflight correctly exposed a brownout. The validator was not weakened. A staged five-minute functional-stability procedure was then added and the Project Owner reported the required follow-up configurations as passed.

See [`BROWNOUT-DIAGNOSTIC.md`](BROWNOUT-DIAGNOSTIC.md).
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

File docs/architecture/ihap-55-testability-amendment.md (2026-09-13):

# IHAP-55 — Testability Architecture Amendment

**Date:** 2026-09-12  
**Status:** IN PROGRESS design amendment; does not supersede Accepted upstream ADRs

## Decision candidate

Revision A adds a dedicated board-health ADC, `TLA2024IRUGT` (`U6`), on the existing I2C bus.

Purpose: make the final PCB programmatically diagnosable over the ESP32-C3 native USB interface without consuming application GPIO or changing the product sensor/event contract.

Channels:
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

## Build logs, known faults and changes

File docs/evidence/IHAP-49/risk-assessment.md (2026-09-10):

# IHAP-49 — Power Risk Assessment Summary

**Status:** architecture-level summary only; canonical living treatment dossiers are R-012 and R-013

This file is a compact IHAP-49 evidence summary. It is **not** the canonical treatment dossier. Canonical Risk Records:

- [R-012 — Unprotected 1S Li-ion Battery Fault and Cell-Side Protection](../../risks/records/R-012-unprotected-li-ion-battery-fault.md), treatment `RT-R012-01`;
- [R-013 — Edge Power Rail and Source-Transfer Integrity](../../risks/records/R-013-edge-power-rail-transfer-integrity.md), treatment `RT-R013-01`.

Both treatments are **Proposed**, not Approved/Implemented/Verified. Residual-risk decision remains Pending Project Owner. `ihap-56-closure-matrix.md` is the review state router.

## Accepted baseline versus Proposed remediation

ADR-0007 / PR #34 was accepted on 2026-09-07. The accepted baseline already partially mitigates R-012/R-013 through backup-only use, system-responsibility protection, reverse-insertion prevention, regulated product SYS, post-regulation/equivalent, USB priority, anti-backfeed, **0.5 A continuous capability across the accepted battery and valid USB-input ranges**, headroom and source-transfer targets.

IHAP-56 later introduced tighter controls/tests. The rows below mark those additions **Proposed** so they are not mistaken for retroactively accepted requirements.

| Exposure | Severity | Canonical risk | Control / requirement | Validation evidence / approval state |
|---|---|---|---|---|
| Normal 5 V source loss | High | R-013 | Accepted automatic USB-priority transfer; **Proposed** high/mid/valid-low strengthening | Accepted V8/V9 baseline; strengthened V8/V9 `[UNVALIDATED]` / Proposed |
| Backfeed into USB source/cable | High | R-013 | Accepted: backfeed prohibited; **Proposed** measurable open-port/attached-unpowered-source limits | V8/V9 `[UNVALIDATED]`; quantified strengthening Proposed |
| USB source overload while charging + running | High | R-013 | Accepted source-profile/system-priority intent; **Proposed** worst-case ILIM <=1.50 A + V14 | V14 `[UNVALIDATED]` / Proposed |
| 0.5 A capability at range endpoints | High | R-013 | **Accepted** across accepted battery and valid USB-input ranges | V6 endpoint evidence `[UNVALIDATED]` |
| Battery over-charge | High | R-012 | Accepted 4.2 V CV / ~1 A target; **Proposed** 4.20 ±0.05 V numeric PASS envelope | V4 `[UNVALIDATED]`; numeric strengthening Proposed |
| NTC hot/cold/open/short | High | R-012 | Accepted NTC monitoring; **Proposed** mandatory fail-bounded fault-state verification | strengthened V4 `[UNVALIDATED]` / Proposed |
| Battery over-discharge / restart oscillation | High | R-012 | Accepted do-not-operate-below-cell-boundary intent; **Proposed** 2.70/3.00 V numeric policy | strengthened V10 `[UNVALIDATED]` / Proposed |
| BAT-side short / over-current | High | R-012 | **Proposed** source-side interruption ahead of every conductor claimed as protected; any segment before it needs separate control/evidence | V13 + upstream-segment evidence `[UNVALIDATED]` / Proposed |
| Reverse cell insertion | High | R-012 | Accepted electrical block/protection or physical keying; **Proposed** V15-A USB-absent + V15-B USB-present electrical functional criteria | V1+V3 accepted; V15 `[UNVALIDATED]` / Proposed |
| Wi-Fi / load transient brownout or release overshoot | High | R-013 | Accepted >=1 A headroom; **Proposed** bidirectional <=100 µs strengthening | accepted V7 baseline; strengthened V7 `[UNVALIDATED]` / Proposed |
| 3.3 V rail out of range | High | R-013 | Accepted regulated 3.3 V domain; **Proposed** component-derived steady/transient band, initially ESP32-C3 3.0–3.6 V outer bound | V2/V5/V7/V8/V9 `[UNVALIDATED]` / Proposed strengthening |
| USB-C incompatibility / one CC path missing | High | R-013 | Accepted Type-C sink/C-to-C 5 V contract | **V2 both DUT plug orientations** `[UNVALIDATED]` |
| Thermal overstress | High | R-012 + R-013 | Accepted physical thermal validation intent; **Proposed** manufacturer-derived numeric table plus justified MP2636 junction estimate/derived case ceiling | strengthened thermal evidence `[UNVALIDATED]` / Proposed |
| Product 5 V not regulated in USB mode | High | R-013 | Accepted MP2636 pass-through caveat + post-regulation | V2+V5+V6 `[UNVALIDATED]` |
| Low transfer point overlaps cutoff | High | R-013 | **Proposed** low V8/V9 nominal 2.90±0.05 V plus >=100 mV loaded BATT margin above maximum cutoff and path-enabled precondition | strengthened V8/V9 `[UNVALIDATED]` / Proposed |
| Holder fit / contact stress | Medium | R-012 | Physical fit/retention bounded | V3 `[UNVALIDATED]` |
| Unsupported autonomy expectation | Medium | R-013 | Accepted backup-only role; runtime requires endurance evidence | V12 `[UNVALIDATED]` |
| Cost creep from stacked breakouts | Medium | decision/cost governance | Accepted custom PCB direction; redundant breakout purchases rejected | IHAP-55 final BOM `[UNVALIDATED]` |
| Event corruption/duplication after reset | Medium | R-013 + downstream runtime | Accepted no-reset target; **Proposed** V9 zero restoration-reset effectiveness criterion | accepted logging + strengthened V9 Proposed |
| Sensor-placement regression | Medium | R-011 where applicable | Accepted placement-sensitive sensors remain modular/off-board | IHAP-55/IHAP-51 `[UNVALIDATED]` |

## Proposed thermal boundary

IHAP-56 proposes explicit manufacturer-derived PASS/FAIL use of:

- LG MJ1 charging **0–45 °C**;
- LG MJ1 discharge **-20–60 °C**;
- MP2636 recommended operating junction **<=125 °C**; thermal shutdown around 150 °C would fail a treatment validation run;
- exact numeric limits for final post-regulator, 3.3 V regulator, inductor and protection element before thermal treatment evidence passes.

A package/case/board temperature is not the junction temperature. Proposed thermal PASS additionally requires a documented manufacturer-supported or conservatively derived junction-temperature estimate/derating method using PMIC loss, applicable datasheet thermal parameters, final layout/copper, ambient and uncertainty; alternatively a conservative case/board ceiling must be derived that guarantees Tj remains inside the proposed limit. Without that relation, MP2636 thermal treatment effectiveness remains `[UNVALIDATED]`.

These are source-supported engineering limits but their promotion into the IHAP-56 treatment acceptance contract remains **Proposed** pending Project Owner approval.

## Proposed cell-side / reverse strengthening

The selected MJ1 is unprotected. RT-R012-01 proposes source-side over-current interruption because PMIC SYS/boost limiting cannot cover every upstream holder/BAT fault. A conductor between cell contact and interruption element is **not covered by V13** and must be eliminated from the claimed protected segment or separately controlled/verified. Proposed V13 must test every actual/production-identical conductor claimed as protected, not merely a loose sacrificial device.

If electrical reverse blocking is selected, Proposed V15 has two cases: USB absent and USB present. The USB-present case uses a bounded bidirectional source/sink simulator so charger-originated current into a reversed battery interface is measured. The actual cell is never intentionally reverse-connected or hard-shorted.

## Proposed transfer / backfeed / 3.3 V strengthening

- Proposed low V8/V9 condition is nominal **2.90±0.05 V** and must retain **>=100 mV loaded BATT headroom above the maximum permitted cutoff** before USB removal; the old 2.80±0.05 V point is retired.
- Proposed backfeed PASS: open DUT USB VBUS **<=0.30 V** while battery-backed and current into an attached unpowered upstream source **<=1.0 mA** after settling, unless tighter selected-component/source limits apply.
- Proposed 3.3 V PASS band is the intersection of all populated-component supply ranges; until frozen, ESP32-C3 **3.0–3.6 V** is the initial outer bound. The rail is checked in steady operation and during proposed V7/V8/V9 events.

## Traceability rule

- R-012 and R-013 are canonical for treatment rationale/lifecycle/effectiveness.
- Both canonical Category fields use the defined value **Technical**; compliance/claim or data-integrity effects are consequences, not invented category names.
- ADR-0007 inverse links declare the allowed effect **Partially mitigates** for the accepted baseline.
- ADR-0007 acceptance does not approve later RT-R012-01/RT-R013-01 details.
- IHAP-55 implements the applicable scope only after the decision boundary is resolved; IHAP-57 coordinates lifecycle/effectiveness after approval and evidence.
- This summary must not mark a risk/treatment `Approved`, `Implemented`, `Verified`, `Accepted` or `Closed` without the required evidence/decision.

## Claim boundary

None of the controls authorizes `safe`, `certified`, `fire-safe`, `compliant`, `production-ready` or equivalent claims. Physical evidence remains `[UNVALIDATED]` where indicated.

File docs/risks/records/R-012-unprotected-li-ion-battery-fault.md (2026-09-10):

# Risk Assessment — Unprotected 1S Li-ion Battery Fault and Cell-Side Protection

**Risk ID:** R-012  
**Risk status:** Newly Identified  
**Current assessment date:** 2026-09-09  
**Last reviewed:** 2026-09-09  
**Next review:** explicit Project Owner treatment decision, IHAP-55 schematic review, received-cell qualification, or material battery/protection topology change  
**Project:** [ITS] [EDGE] HomeEdge AI Platform  
**Jira:** IHAP-49 / IHAP-55 / IHAP-57  
**Related remediation:** IHAP-56  
**Related ADR:** `docs/adr/ADR-0007-edge-power-subsystem.md`  
**Owner decision:** Pending

<!--
AI_AGENT_METADATA:
  document_type: risk_record
  source_of_truth: github_versioned_repository_documentation
  jira_role: operational_coordination_only
  confluence_role: stakeholder_summary_and_navigation_only
  risk_acceptance_authority: project_owner
  related_adr: docs/adr/ADR-0007-edge-power-subsystem.md
  primary_treatment: RT-R012-01
  treatment_lifecycle: Proposed
  unvalidated_claim_marker: "[UNVALIDATED]"

HIDDEN_ANTI_REGRESSION_RULES:
  - The selected LG INR18650-MJ1 is unprotected; do not imply cell-level protection exists.
  - PMIC SYS/boost current limiting must not be treated as protection for a short on holder leads or BAT net upstream of the PMIC.
  - RT-R012-01 may claim holder/service-wiring over-current coverage only for conductors physically downstream of the interruption element.
  - Any conductor between the cell contact and interruption element is residual exposure until separately controlled and verified.
  - Procedure-only reverse-polarity mitigation is prohibited.
  - Electrical reverse blocking requires bounded functional verification with USB absent and with normal USB present; mechanical keying must physically prevent ordinary reverse insertion.
  - Cell-side over-current interruption, charging limits, NTC behavior, low-voltage behavior, thermal behavior and polarity controls remain [UNVALIDATED] until IHAP-55 evidence exists.
  - RT-R012-01 remains Proposed until explicit Project Owner treatment approval evidence exists.
  - Do not describe the subsystem as safe, certified, fire-safe, production-ready or compliant.
-->

---

## 1. Risk Statement

```text
There is a risk that the unprotected 1S Li-ion cell, holder wiring or custom PCB is electrically or thermally overstressed because reverse insertion, a BAT-side short/over-current condition, incorrect charging, excessive discharge or temperature-control failure can occur outside the protection coverage of the downstream SYS rail.
```

---

## 2. Source Trigger and Scope

**Source trigger:** ADR-0007 selects an **unprotected LG INR18650-MJ1** in a currently unkeyed serviceable holder. The preferred MP2636-class architecture provides charger/power-path/boost controls, but output/SYS limiting alone cannot interrupt every fault path on holder leads or BAT net upstream of the PMIC. Physical implementation is not yet fabricated.

**In scope:** cell contact/holder/BAT wiring, source-side over-current interruption, any conductor upstream of the interruption element, reverse insertion, charge voltage/current, NTC hot/cold/open/short behavior, low-voltage cutoff/recovery, thermal operating boundaries, holder fit and service interaction.

**Out of scope:** battery certification/regulatory approval, destructive abuse testing of an actual cell, multi-cell packs, production qualification, unrelated enclosure aesthetics.

---

## 3. Affected Assets and Trust Boundary

| Area | Detail |
|---|---|
| Assets | LG MJ1 cell, holder contacts/leads, BAT net, charger/power-path PMIC, PCB, enclosure/service interface |
| Trust boundary | User/service interaction with removable cell and electrical boundary between cell/holder and PCB |
| Category | Technical |
| Stakeholder surface | Compliance / Claims consequences: hardware replication, installation/service instructions, battery/autonomy and maturity claims |

---

## 4. Current Assessment

| Field | Value | Rationale |
|---|---|---|
| Likelihood | Medium | Holder is not keyed and final protection implementation does not yet exist |
| Impact | High | Reverse insertion, uncontrolled BAT-side current, thermal or charging faults can damage hardware/cell and invalidate subsystem operation |
| Residual risk | Pending Evidence | A proposed treatment exists but is not approved, implemented or verified |
| Evidence gap | `[UNVALIDATED]` | No fabricated board, source-side protection verification, upstream-segment control evidence, NTC fault simulation, reverse-blocking functional test, thermal run or received-cell fit test |
| Decision state | Pending Project Owner | ADR acceptance is not treatment approval or residual-risk acceptance |

---

## 5. Existing Controls

| Control | Evidence | Coverage | Limitation |
|---|---|---|---|
| Backup-only battery role | ADR-0007 | Reduces duty/expectation | Does not prevent electrical faults |
| 4.2 V CV and ~1 A charge targets | ADR-0007 / IHAP-49 contract | Bounds intended charging | Implementation `[UNVALIDATED]` |
| NTC monitoring requirement | ADR-0007 | Requires temperature gating | Fault thresholds/function `[UNVALIDATED]` |
| Reverse-insertion prevention requirement | ADR-0007 | Procedure-only control explicitly rejected | Electrical/mechanical implementation `[UNVALIDATED]` |
| Owned holder dimensions and unkeyed condition recorded | `docs/evidence/IHAP-49/owned-hardware-evidence.md` | Makes mechanical risk visible | Received-cell fit remains `[UNVALIDATED]` |

Planned controls below are not existing controls.

---

## 6. Risk Treatment Summary

| Treatment ID | Title | Strategy | Lifecycle status | Jira | ADR | Last review |
|---|---|---|---|---|---|---|
| RT-R012-01 | Implement and verify system-level 1S cell protection | Mitigate | **Proposed** | IHAP-55 implementation; IHAP-57 effectiveness tracking | ADR-0007 | 2026-09-09 |

`Proposed` is mandatory here because no durable Project Owner decision explicitly approves this treatment scope yet. ADR-0007 acceptance predates the treatment record and must not be reused as implicit approval evidence.

---

## 7. Risk Treatments

### RT-R012-01 — Implement and verify system-level 1S cell protection

**Strategy:** Mitigate  
**Lifecycle status:** Proposed  
**Treatment owner:** IHAP-55 power/PCB workstream; IHAP-51 for mechanical keying/serviceability where used  
**Jira coordination:** IHAP-55 / IHAP-57  
**Related ADRs:** ADR-0007  
**Introduced:** 2026-09-07  
**Last reviewed:** 2026-09-09  
**Next review trigger:** explicit Project Owner treatment decision or IHAP-55 schematic freeze

#### Rationale

The selected cell is unprotected. The final product needs system-boundary controls including fault paths before the PMIC SYS output. PMIC boost/SYS current limiting cannot by itself protect a short on holder leads or BAT net upstream of that stage. A protection element located only on the PCB after ordinary holder wiring also cannot claim to protect a short that occurs **before** that element. The accepted ADR establishes the battery role and system-level protection direction; the more specific source-side interruption, upstream-segment, fault-state and numeric verification details below are the **Proposed** RT-R012-01 treatment and are not approved merely because ADR-0007 is Accepted.

#### Proposed mandatory controls / actions

- place a **source-side over-current interruption element ahead of every holder/service conductor that RT-R012-01 claims to protect**, preferably at or immediately adjacent to the cell/holder positive contact;
- if any conductor necessarily remains between cell contact and interruption element, explicitly record that segment as uncovered by V13 and either move/add protection ahead of it or provide a separate reviewed mechanical/electrical control and verification before claiming treatment coverage for that segment;
- size interruption threshold/time from legitimate charge/discharge/transient current, conductor/trace ampacity and component characteristics;
- provide electrical reverse-battery blocking/protection **or** mechanical keying that physically prevents reverse insertion; procedure/labels are supplementary only;
- if electrical blocking is used, execute V15-A with USB absent **and V15-B with normal USB present**, both using bounded source/sink-capable battery-simulator fixtures and explicit current/voltage criteria;
- implement 4.2 V charge-voltage selection and ~1 A nominal charge target inside the source/thermal budget;
- implement NTC gating with normal/hot/cold/open/short functional verification;
- enforce MJ1 charge operation at **0–45 °C** and discharge operation at **-20–60 °C** if this proposed treatment is approved;
- implement the first-reference low-voltage policy: cutoff **2.70 V ±0.05 V**, no deliberate operation below **2.50 V**, recovery **>=3.00 V ±0.05 V** or valid USB, with no cutoff/restart oscillation;
- verify holder fit/retention without wrapper damage or excessive insertion force.

#### Scope coverage

| Cause / consequence | Coverage | Remaining exposure |
|---|---|---|
| BAT-side short / excessive cell current downstream of source-side interruption | Direct | Interruption rating/behavior `[UNVALIDATED]` until schematic and V13 |
| Conductor between cell contact and interruption element | Conditional / residual | **Not covered by V13**; must be eliminated from the claimed protected segment or separately controlled/verified before treatment effectiveness can be Verified |
| Reverse insertion with USB absent | Direct | Electrical blocker or mechanical keying `[UNVALIDATED]`; electrical path needs V15-A |
| Reverse insertion while USB remains present | Direct | Charger-originated current into reversed interface remains `[UNVALIDATED]`; electrical path needs V15-B |
| Charging over-voltage/current | Direct | PMIC configuration and V4/V14 pending |
| NTC hot/cold/open/short | Direct | Network thresholds and recovery `[UNVALIDATED]` |
| Thermal overstress | Direct | Final component thermal/junction method and powered evidence pending |
| Over-discharge / oscillatory recovery | Direct | Numeric V10 evidence pending |
| Cell internal defect / abuse outside intended use | Partial | Not eliminated; certification/abuse qualification outside MVP claims |

#### Source and Evidence Register

| ID | Source | Source type | Supports | Version / applicability | Verification | Checked on | Limitations |
|---|---|---|---|---|---|---|---|
| SRC-01 | `docs/adr/ADR-0007-edge-power-subsystem.md` | Project decision | Unprotected cell selection, backup role, system-responsibility protection and reverse-polarity direction | Accepted 2026-09-07 | Verified | 2026-09-09 | Does not approve the later RT-R012-01 details or lifecycle |
| SRC-02 | `docs/evidence/IHAP-49/owned-hardware-evidence.md` | Internal evidence | Unkeyed holder / owned hardware observations | Owned specimens | Verified | 2026-09-09 | Does not prove final PCB/source-side protection |
| SRC-03 | MPS MP2636 datasheet in source register | Manufacturer | PMIC charger/power-path/boost/TS behavior | Rev.1.02 | Verified | 2026-09-09 | Does not cover arbitrary upstream BAT faults |
| SRC-04 | LG INR18650-MJ1 product specification in source register | Manufacturer | 4.2 V max charge, 2.5 V discharge end, 0–45 °C charge, -20–60 °C discharge | MJ1 Rev.1 source | Verified for model | 2026-09-09 | Received lot still pending inspection |

#### Implementation and Verification Evidence

| Evidence ID | Evidence | Evidence class | Expected result | Actual result | Status |
|---|---|---|---|---|---|
| EV-01 | IHAP-55 schematic/BOM review | Implementation | Source-side interruption coverage boundary, residual upstream segment (if any), reverse control, NTC, low-voltage and thermal limits are explicit | Not executed | `[UNVALIDATED]` |
| EV-02 | V4 NTC/charging/thermal + V14 source-limit run | Verification | Charge/NTC/source-priority behavior meets the approved/frozen treatment limits | Not executed | `[UNVALIDATED]` |
| EV-03 | V13 source-side over-current verification | Verification | Every conductor claimed as protected is downstream of and exercised through the actual/production-identical interruption path; any upstream segment has separate evidence | Not executed | `[UNVALIDATED]` |
| EV-04 | Received MJ1 / holder qualification | Verification | Correct identity/condition and non-destructive fit/retention | Not executed | `[UNVALIDATED]` |
| EV-05 | V10 low-voltage / recovery run | Verification | 2.70 V cutoff, >=3.00 V recovery, no deliberate <2.50 V discharge or oscillation | Not executed | `[UNVALIDATED]` |
| EV-06 | V15-A/V15-B reverse-polarity functional tests when electrical blocking is used | Verification | USB-absent and USB-present reversed-interface cases stay within frozen current/voltage/device-stress criteria with no damage | Not executed / N/A if mechanical-only keying | `[UNVALIDATED]` |

For EV-03/EV-06 use bounded current-limited fixtures. **Do not intentionally hard-short or reverse-connect the actual Li-ion cell.**

#### Treatment Effectiveness Review

**Review date:** Pending  
**Evidence reviewed:** Pending  
**Effectiveness:** Pending Evidence  
**Likelihood after treatment:** Pending Evidence  
**Impact after treatment:** Pending Evidence  
**Residual risk:** Pending Evidence  
**Project Owner decision required:** Yes

---

## 8. Traceability

| Relationship | Link | Effect / Rule |
|---|---|---|
| Accepted ADR | `docs/adr/ADR-0007-edge-power-subsystem.md` | **Partially mitigates** — the accepted baseline establishes backup-only use, system-responsibility protection and reverse-polarity prevention direction. This allowed ADR effect does **not** approve, implement or verify the later RT-R012-01 treatment details. |
| Implementation task | IHAP-55 | Schematic, PCB and physical tests after the applicable treatment/amendment scope is explicitly approved |
| Effectiveness tracking | IHAP-57 | Treatment lifecycle/effectiveness after approval and evidence |
| Remediation task | IHAP-56 | Creates canonical risk/treatment traceability and proposed remediation detail |
| Validation contract | `docs/evidence/IHAP-49/validation-plan.md` | Accepted baseline plus explicitly marked Proposed IHAP-56 test additions; source-side V13 and USB-absent/present V15 detail are not treatment approval by themselves |
| Closure matrix | `docs/evidence/IHAP-49/ihap-56-closure-matrix.md` | Cross-file Accepted/Proposed state and review invariants |

---

## 9. Stakeholder Visibility

Risk summary and treatment state may be shown in stakeholder summaries. Technical details should link to GitHub. Do not claim the battery subsystem is safe/certified/production-ready; treatment is Proposed and effectiveness remains `[UNVALIDATED]`.

---

## 10. Assessment History

| Date | Change | Treatment | Evidence | Decision |
|---|---|---|---|---|
| 2026-09-07 | Canonical risk created from IHAP-49 post-merge review | RT-R012-01 initially drafted | ADR-0007 + IHAP-49 evidence | Pending |
| 2026-09-08 | Lifecycle corrected per risk model; reverse, thermal and numeric low-voltage verification strengthened; canonical category/inverse ADR effect corrected | RT-R012-01 **Proposed** | Review finding remediation; implementation pending | Pending Project Owner |
| 2026-09-09 | Upstream-holder coverage boundary and USB-present reverse-insertion case made explicit | RT-R012-01 **Proposed** | Latest Codex finding remediation | Pending Project Owner |

---

## 11. Review Notes

```text
[x] Risk statement, assets, boundary and source trigger are explicit.
[x] Category uses the canonical risk-model vocabulary; claim consequences remain in stakeholder/rationale text.
[x] Existing controls are separated from proposed treatment.
[x] RT-R012-01 has stable identity and Jira coordination.
[x] Lifecycle is Proposed until explicit approval evidence exists.
[x] V13 cannot overclaim protection for conductors located before the interruption element.
[x] Electrical reverse blocking includes bounded USB-absent and USB-present functional cases.
[x] NTC, thermal and numeric low-voltage verification remain Proposed treatment detail until approved.
[x] Inverse ADR relationship declares the allowed effect `Partially mitigates` without implying treatment approval.
[x] Missing proof preserves [UNVALIDATED].
[x] No residual-risk acceptance or safety/certification claim is made.
```

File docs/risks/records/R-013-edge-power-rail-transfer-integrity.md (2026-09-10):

# Risk Assessment — Edge Power Rail and Source-Transfer Integrity

**Risk ID:** R-013  
**Risk status:** Newly Identified  
**Current assessment date:** 2026-09-09  
**Last reviewed:** 2026-09-09  
**Next review:** explicit Project Owner treatment decision, IHAP-55 schematic freeze, first power bring-up, or material PMIC/regulator/source-transfer change  
**Project:** [ITS] [EDGE] HomeEdge AI Platform  
**Jira:** IHAP-49 / IHAP-55 / IHAP-57  
**Related remediation:** IHAP-56  
**Related ADR:** `docs/adr/ADR-0007-edge-power-subsystem.md`  
**Owner decision:** Pending

<!--
AI_AGENT_METADATA:
  document_type: risk_record
  source_of_truth: github_versioned_repository_documentation
  jira_role: operational_coordination_only
  confluence_role: stakeholder_summary_and_navigation_only
  risk_acceptance_authority: project_owner
  related_adr: docs/adr/ADR-0007-edge-power-subsystem.md
  primary_treatment: RT-R013-01
  treatment_lifecycle: Proposed
  unvalidated_claim_marker: "[UNVALIDATED]"

HIDDEN_ANTI_REGRESSION_RULES:
  - MP2636 input pass-through must not be mislabeled as a regulated 5.0 V product rail.
  - Accepted 0.5 A continuous capability applies across the accepted battery range and valid USB-input range.
  - Product 5 V regulation, source-current limiting, quantified backfeed blocking, 3.3 V integrity, load-step response and source transfer remain [UNVALIDATED] until IHAP-55 evidence exists.
  - No-reset transfer is a target, not an achieved property.
  - Proposed load-step evidence covers both load edges with a frozen slew/rise-fall requirement.
  - Proposed transfer/restoration low condition must preserve margin above the maximum permitted cutoff under load.
  - Proposed thermal verification must use a justified junction-temperature estimate or conservative derived case/board limit; package temperature alone is insufficient.
  - RT-R013-01 remains Proposed until explicit Project Owner treatment approval evidence exists.
-->

---

## 1. Risk Statement

```text
There is a risk that the edge node resets, loses sensing continuity, backfeeds or overloads the external source, oscillates between sources or operates outside its accepted voltage domain because USB input limiting, pass-through, battery boost, post-regulation and source-transfer stages may not maintain stable 5 V and 3.3 V product rails across steady-state and transient conditions.
```

---

## 2. Source Trigger and Scope

**Source trigger:** ADR-0007 requires one regulated 5 V product bus from both normal USB-C power and 1S backup. Review established that MP2636 valid input is passed to SYS rather than regulated to the programmable battery-boost setpoint, so a downstream regulator or equivalent topology is required. Physical behavior is not yet measured.

**In scope:** USB-C sink/input behavior and current limiting; intermediate pass-through/boost; downstream 5 V and 3.3 V regulation; USB-priority takeover/restoration; backfeed; accepted 0.5 A continuous capability across the battery/USB ranges; 1.0 A dynamic response; thermal interaction with power delivery; ESP32 reset/brownout; final-node quantitative power work transferred by the accepted ADR baseline from ADR-0001/0002/0004/0005, with ADR-0003 transfer proposed by IHAP-56 pending Project Owner approval.

**Out of scope:** application-level event recovery beyond recording power-induced resets; arbitrary USB-C/PD profiles; certification/production reliability; multi-day battery-only autonomy.

---

## 3. Affected Assets and Trust Boundary

| Area | Detail |
|---|---|
| Assets | 5 V product SYS, 3.3 V rail, ESP32-C3, LD2410C, OLED/environmental/reed interfaces, upstream USB source |
| Trust boundary | External 5 V USB-C source ↔ charger/power path ↔ battery ↔ post-regulator ↔ node load |
| Category | Technical |
| Stakeholder surface | Data-integrity consequence: sensing continuity, node availability, autonomy claims and reproducibility |

---

## 4. Current Assessment

| Field | Value | Rationale |
|---|---|---|
| Likelihood | Medium | Topology is accepted but custom PCB and dynamic response are not implemented |
| Impact | High | Rail collapse/backfeed/source overload/reset can interrupt sensing and invalidate continuity claims |
| Residual risk | Pending Evidence | Proposed treatment is not approved, implemented or verified |
| Evidence gap | `[UNVALIDATED]` | No fabricated-board source-limit, 3.3 V transient, bidirectional load-step, transfer/restoration, quantified backfeed, thermal or final-node current evidence |
| Decision state | Pending Project Owner | ADR acceptance is not treatment approval or residual-risk acceptance |

---

## 5. Existing Controls

| Control | Evidence | Coverage | Limitation |
|---|---|---|---|
| Regulated 5.0 V product-bus contract | ADR-0007 | Prevents accepting pass-through as final rail | Physical regulation `[UNVALIDATED]` |
| MP2636 caveat + downstream regulation requirement | ADR-0007 / custom PCB power contract | Addresses normal-input regulation gap | Exact regulator/topology `[UNVALIDATED]` |
| USB-priority/no-backfeed requirements | ADR-0007 | Defines expected source behavior | Transfer/isolation `[UNVALIDATED]` |
| >=0.5 A continuous **across accepted battery and valid USB-input ranges** / >=1.0 A headroom envelope | ADR-0007 | Defines sizing target | Capability `[UNVALIDATED]` |
| Regulated 3.3 V domain requirement | ADR-0007 | Requires compatible ESP32/peripheral supply | Exact regulator and transient margins `[UNVALIDATED]` |

The detailed V7/V8/V9/V14 acceptance conditions added by IHAP-56 are **Proposed treatment/validation detail**, not existing controls and not accepted merely because ADR-0007 is Accepted.

---

## 6. Risk Treatment Summary

| Treatment ID | Title | Strategy | Lifecycle status | Jira | ADR | Last review |
|---|---|---|---|---|---|---|
| RT-R013-01 | Implement and verify regulated dual-source product power | Mitigate | **Proposed** | IHAP-55 implementation; IHAP-57 effectiveness tracking | ADR-0007 | 2026-09-09 |

`Proposed` is required because there is not yet durable Project Owner evidence explicitly approving this later treatment scope. Accepted ADR-0007 requirements support the rationale but do not substitute for treatment approval.

---

## 7. Risk Treatments

### RT-R013-01 — Implement and verify regulated dual-source product power

**Strategy:** Mitigate  
**Lifecycle status:** Proposed  
**Treatment owner:** IHAP-55 custom PCB/power workstream  
**Jira coordination:** IHAP-55 / IHAP-57  
**Related ADRs:** ADR-0007  
**Introduced:** 2026-09-07  
**Last reviewed:** 2026-09-09  
**Next review trigger:** explicit Project Owner treatment decision or schematic freeze

#### Rationale

The accepted ADR baseline already requires a regulated 5.0 V product bus, USB-priority backup transfer, prohibited backfeed, a post-MP2636 regulation stage or reviewed equivalent, regulated 3.3 V downstream power, and a >=0.5 A continuous capability **across the accepted battery and valid USB-input ranges** plus >=1.0 A headroom. Those architectural constraints do not prove that the fabricated implementation actually maintains either product rail under combined charging, fast load transitions, source loss/restoration, low-battery conditions or endpoint input conditions. RT-R013-01 therefore proposes one verification treatment coupling source-current limiting, 5 V/3.3 V dynamic capture, quantified backfeed, endpoint range testing, transfer/restoration and final-node current evidence. The tighter numeric conditions added by IHAP-56 remain **Proposed** until explicit Project Owner approval and must not be treated as accepted architecture amendments before that decision.

#### Proposed mandatory controls / actions

- preserve a **regulated 5.0 V product SYS** regardless of intermediate USB pass-through or battery boost;
- with MP2636, add a downstream regulator covering the complete intermediate range or explicitly supersede the topology through review;
- preserve the accepted **>=0.5 A continuous capability across the accepted battery range and valid USB-input range**, with endpoint evidence in V6;
- implement correct USB-C 5 V sink termination/input protection and functionally verify both DUT plug orientations;
- freeze input-current limiting so worst-case configured maximum including tolerance is **<=1.50 A** for the reference source;
- verify combined node-load + charging behavior using V14, proving charge current yields to system load before SYS collapse;
- quantify prohibited backfeed using proposed V8/V9 criteria: open DUT VBUS <=0.30 V while battery-backed and current driven into an attached unpowered source <=1.0 mA after settling, unless a selected component/source imposes tighter values;
- implement deterministic USB-priority transfer/restoration without source oscillation;
- verify transfer/restoration at high **4.10±0.10 V**, mid **3.60±0.10 V**, and low nominal **2.90±0.05 V** while also maintaining >=100 mV measured BATT headroom above the maximum permitted cutoff under the pre-transfer load; raise the simulator setpoint if necessary so the battery path is enabled before USB removal;
- require **zero restoration-attributable ESP32 reset/brownout** in V9 at every required battery/load condition if the no-reset target is to be verified;
- size product 5 V stage for >=0.5 A continuous and >=1.0 A transient/headroom;
- execute V7 in both directions, baseline->1 A and 1 A->baseline, with **10–90% current transition <=100 µs** or a faster final measured load-derived requirement;
- define the final 3.3 V rail PASS band as the intersection of all populated 3.3 V-load manufacturer supply ranges; until exact parts are frozen, ESP32-C3 **3.0–3.6 V** is the initial outer bound and tighter loads supersede it;
- apply the 3.3 V steady/transient band to V2/V5 and strengthened V7/V8/V9 at the ESP32-C3 supply/test point;
- enforce rail/reset/transient and manufacturer-derived thermal PASS criteria;
- for MP2636 thermal evidence, use a justified junction-temperature estimate or conservative derived case/board ceiling based on dissipation, datasheet thermal parameters applicable to final layout/copper, ambient and uncertainty; package temperature alone cannot prove Tj <=125 °C;
- provide product-SYS, intermediate-SYS and 3.3 V test points;
- execute final-node quantitative characterization for the accepted transferred obligations from ADR-0001/0002/0004/0005; include ADR-0003/reed current only after the proposed ownership-transfer amendment is explicitly approved or otherwise assigned by an accepted downstream decision;
- execute endurance before any measured autonomy claim.

#### Scope coverage

| Cause / consequence | Coverage | Remaining exposure |
|---|---|---|
| USB pass-through below/above desired product rail | Direct | Post-regulator physical evidence pending |
| 0.5 A capability near accepted range endpoints | Direct | V6 endpoint evidence pending |
| USB source overload / incorrect ILIM | Direct | V14 pending |
| Battery boost / low-cell regulation | Direct | Converter/layout evidence pending |
| 3.3 V rail outside ESP32/peripheral range | Direct | Component-derived band and V2/V5/V7/V8/V9 evidence pending |
| 1 A load-apply droop / load-release overshoot | Direct | Bidirectional <=100 µs V7 pending |
| USB↔battery transfer/reset | Direct | V8/V9 high/mid/valid-low pending; any restoration reset fails the proposed no-reset verification target |
| Upstream backfeed / leakage | Direct | Quantified open-port and attached-unpowered-source V8/V9 evidence pending |
| Thermal overstress / unproven Tj | Direct | Final thermal table, justified junction method and powered evidence pending |
| Final-node actual power | Direct | V11 pending |
| Runtime event recovery after power reset | Partial | Software recovery remains downstream scope |

#### Source and Evidence Register

| ID | Source | Source type | Supports | Version / applicability | Verification | Checked on | Limitations |
|---|---|---|---|---|---|---|---|
| SRC-01 | `docs/adr/ADR-0007-edge-power-subsystem.md` | Project decision | Accepted product rail/source-transfer/range architecture baseline | Accepted 2026-09-07 | Verified | 2026-09-09 | Does not approve RT-R013-01 or later numeric validation amendments |
| SRC-02 | MPS MP2636 datasheet in source register | Manufacturer | IN-to-SYS pass-through, operating Tj, boost/charger behavior | Rev.1.02 | Verified | 2026-09-09 | Final PCB dynamics/layout and junction estimation method not automatically covered |
| SRC-03 | `docs/evidence/IHAP-49/validation-plan.md` | Project validation plan | Accepted baseline tests plus explicitly marked Proposed IHAP-56 extensions | IHAP-49 handoff / IHAP-56 remediation | Verified as documentation | 2026-09-09 | Execution pending; proposed extensions are not treatment approval |
| SRC-04 | ADR-0001/0002/0004/0005; ADR-0003 separately proposed for transfer | Project decisions | Accepted node-load obligations and proposed reed-current ownership correction | Current accepted ADRs + IHAP-56 proposal | Verified | 2026-09-09 | Final custom-board measurements pending; ADR-0003 transfer not yet approved as an ADR-0007 amendment |

#### Implementation and Verification Evidence

| Evidence ID | Evidence | Evidence class | Expected result | Actual result | Status |
|---|---|---|---|---|---|
| EV-01 | IHAP-55 schematic/ERC/DRC/BOM review | Implementation | Post-regulation/equivalent, anti-backfeed, ILIM, test points, 3.3 V band, thermal/junction method and current envelope implemented for approved scope | Not executed | `[UNVALIDATED]` |
| EV-02 | V2/V5/V6 regulated rail/range tests | Verification | 5 V remains in accepted band; 3.3 V remains inside frozen component-derived band; 0.5 A capability holds at required battery/USB endpoints | Not executed | `[UNVALIDATED]` |
| EV-03 | V7 bidirectional 1 A load-step | Verification | Both edges meet approved transition requirement; 5 V/3.3 V transient/reset/recovery criteria hold | Not executed | `[UNVALIDATED]` |
| EV-04 | V8/V9 source transfer/restoration | Verification | High/mid/valid-low conditions meet quantified backfeed/no-oscillation criteria and, for no-reset verification, **zero transfer/restoration-attributable reset or brownout** with 5 V/3.3 V rails in band | Not executed | `[UNVALIDATED]` |
| EV-05 | V14 combined source-current-limit/system-priority | Verification | Input remains <=1.50 A / frozen ILIM and charge current yields before SYS collapse | Not executed | `[UNVALIDATED]` |
| EV-06 | V11 final-node quantitative characterization | Verification | Required accepted rail/current/load contributions recorded; any proposed ADR-0003/reed-current transfer is included only after approval/assignment | Not executed | `[UNVALIDATED]` |
| EV-07 | V12 endurance | Verification | Measured backup duration for tested board/cell/configuration | Not executed | `[UNVALIDATED]` |
| EV-08 | Thermal/junction verification | Verification | Chosen junction-estimation/derating method shows MP2636 Tj <= proposed limit with uncertainty and all other parts within registered limits | Not executed | `[UNVALIDATED]` |

#### Treatment Effectiveness Review

**Review date:** Pending  
**Evidence reviewed:** Pending  
**Effectiveness:** Pending Evidence  
**Likelihood after treatment:** Pending Evidence  
**Impact after treatment:** Pending Evidence  
**Residual risk:** Pending Evidence  
**Project Owner decision required:** Yes

---

## 8. Traceability

| Relationship | Link | Effect / Rule |
|---|---|---|
| Accepted ADR | `docs/adr/ADR-0007-edge-power-subsystem.md` | **Partially mitigates** — the accepted baseline requires regulated product SYS, post-regulation/equivalent, USB priority, anti-backfeed, 0.5 A range capability and source-transfer/headroom targets. This allowed ADR effect does **not** approve, implement or verify later RT-R013-01 treatment details. |
| Implementation task | IHAP-55 | Custom PCB implementation and physical validation after the applicable treatment/amendment scope is explicitly approved |
| Effectiveness tracking | IHAP-57 | Treatment lifecycle/effectiveness after approval and evidence |
| Remediation task | IHAP-56 | Creates canonical risk/treatment traceability and proposed remediation detail |
| Validation contract | `docs/evidence/IHAP-49/validation-plan.md` | Accepted baseline plus explicitly marked Proposed IHAP-56 test additions; proposed V7/V8/V9/V14/3.3/backfeed/thermal detail does not self-approve treatment |
| Closure matrix | `docs/evidence/IHAP-49/ihap-56-closure-matrix.md` | Cross-file Accepted/Proposed state and review invariants |

---

## 9. Stakeholder Visibility

Stakeholder summaries may state the accepted wired-5-V + battery-backup architecture and that physical rail/transfer effectiveness remains `[UNVALIDATED]`. Do not claim fault tolerance, seamless UPS, validated autonomy or production reliability before evidence.

---

## 10. Assessment History

| Date | Change | Treatment | Evidence | Decision |
|---|---|---|---|---|
| 2026-09-07 | Canonical risk created from IHAP-49 post-merge review | RT-R013-01 initially drafted | ADR-0007 + manufacturer source | Pending |
| 2026-09-08 | Lifecycle corrected; combined ILIM test, high/mid/low transfer and bidirectional slew-controlled load-step added; rationale/category/inverse ADR effect and restoration no-reset criterion corrected | RT-R013-01 **Proposed** | Review finding remediation; implementation pending | Pending Project Owner |
| 2026-09-09 | Accepted 0.5 A range restored; low-transfer margin, quantified backfeed, 3.3 V criteria and junction-temperature method added | RT-R013-01 **Proposed** | Latest Codex finding remediation | Pending Project Owner |

---

## 11. Review Notes

```text
[x] Risk statement, source trigger, assets and trust boundary are explicit.
[x] Category uses canonical risk-model vocabulary; data-integrity consequences remain in stakeholder/rationale text.
[x] Accepted 0.5 A range qualifiers are preserved.
[x] Existing controls are separated from proposed treatment detail.
[x] RT-R013-01 has a treatment-specific rationale and remains Proposed until explicit approval evidence exists.
[x] MP2636 pass-through is not mislabeled as regulated product SYS.
[x] Proposed low transfer point cannot overlap the maximum cutoff tolerance under the pre-transfer load.
[x] Proposed backfeed criteria are measurable for open and attached-unpowered upstream conditions.
[x] Proposed 3.3 V rail criteria are component-derived and applied to dynamic/source-transfer tests.
[x] Proposed MP2636 thermal PASS requires a justified junction estimate/derating method, not a package-temperature substitution.
[x] Accepted quantitative ownership transfer remains ADR-0001/0002/0004/0005; ADR-0003 extension is Proposed until approved.
[x] Inverse ADR relationship declares `Partially mitigates` without implying treatment approval.
[x] Missing proof preserves [UNVALIDATED].
[x] No residual-risk acceptance or reliability/safety claim is made.
```

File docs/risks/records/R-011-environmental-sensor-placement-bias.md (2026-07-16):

# Risk Assessment — Environmental Sensor Placement and Enclosure Measurement Bias

**Risk ID:** R-011  
**Risk status:** Newly Identified  
**Current assessment date:** 2026-07-16  
**Last reviewed:** 2026-07-16  
**Next review:** IHAP-51 enclosure/placement validation or material sensor-profile change  
**Project:** [ITS] [EDGE] HomeEdge AI Platform  
**Jira:** IHAP-45 / IHAP-51  
**PR:** [PR #28](https://github.com/pianic2/homeedge-ai-platform/pull/28)  
**Owner decision:** Pending

<!--
AI_AGENT_METADATA:
  document_type: risk_record
  source_of_truth: github_versioned_repository_documentation
  jira_role: operational_coordination_only
  confluence_role: stakeholder_summary_and_navigation_only
  risk_acceptance_authority: project_owner
  related_adr: docs/adr/ADR-0002-environmental-sensor-profiles.md
  unvalidated_claim_marker: "[UNVALIDATED]"

HIDDEN_ANTI_REGRESSION_RULES:
  - Do not treat ADR-0002 as risk acceptance or closure evidence.
  - Preserve the distinction between intrinsic sensor behavior and placement/enclosure effects.
  - Do not claim calibrated or absolute accuracy without independent reference evidence.
  - Do not mark RT-R011-01 Implemented or Verified before IHAP-51 evidence exists.
-->

---

## 1. Risk Statement

```text
There is a risk that temperature and relative-humidity observations are biased, delayed or made incomparable because sensor placement, airflow, thermal coupling, enclosure geometry, condensation or proximity to heat and moisture sources can affect the local microclimate seen by the sensor.
```

The comparative IHAP-45 run showed materially different responses among co-located owned specimens, especially under extreme humidity and temperature phases. Without an independent reference and a final enclosure, the portion attributable to intrinsic sensor behavior versus placement and packaging remains `[UNVALIDATED]`.

---

## 2. Source Trigger and Scope

**Source trigger:** IHAP45-RUN-01 observed wider and differently shaped responses across DHT11, DHT22 and BME280 during controlled transitions. The final node enclosure and installation location are not yet defined.

**In scope:**

- room-node and extended-environment sensor placement;
- enclosure vents, thermal isolation and airflow exposure;
- distance from the ESP32-C3, regulators, walls, windows, doors and environmental sources;
- condensation avoidance;
- comparability between repeated installations;
- validation of DHT11 and BME280 profile-specific placement.

**Out of scope:**

- calibrated laboratory certification;
- quantitative power and regulator characterization;
- pressure sensing;
- medical, safety-critical or industrial process-control claims;
- universal behavior of every DHT11 or BME280 unit.

This record does not introduce firmware, backend, mobile, cloud, runtime, security enforcement, or unsupported maturity claims.

---

## 3. Affected Assets and Trust Boundary

| Area | Detail |
|---|---|
| Assets | Environmental readings, room-state interpretation, automation thresholds, evidence comparability |
| Trust boundary | Physical interface between ambient environment, sensor element, breakout PCB and node enclosure |
| Data involved | Temperature and relative-humidity observations only |
| Stakeholder surface | Room comfort displays, automation decisions, test reports and architecture claims |

---

## 4. Current Assessment

| Field | Value | Rationale |
|---|---|---|
| Category | Technical / Claims | Physical placement can change readings and can lead to overclaiming sensor quality or room state |
| Likelihood | Medium | Final placement and enclosure are not yet verified, and the comparative run showed meaningful inter-sensor divergence |
| Impact | Medium | Biased readings may trigger poor automations or misleading stakeholder conclusions, but the MVP is not safety-critical |
| Residual risk | Pending Evidence | Treatment effectiveness depends on IHAP-51 physical validation |
| Evidence gap | `[UNVALIDATED]` | No final enclosure, installation profile or independent calibrated reference has been tested |
| Decision state | Pending Project Owner | No residual-risk acceptance, deferral or rejection has been made |

---

## 5. Existing Controls

| Control | Evidence | Coverage | Limitation |
|---|---|---|---|
| Comparative co-location protocol | `docs/evidence/IHAP-45/` | Partial | Temporary test arrangement, not final enclosure or installation |
| Explicit relative-only claim boundary | `docs/evidence/IHAP-45/summaries/environmental-IHAP45-RUN-01.summary.md` | Partial | Prevents absolute-accuracy overclaim but does not reduce physical bias |
| Profile-specific ADR | `docs/adr/ADR-0002-environmental-sensor-profiles.md` | Partial | Selects appropriate sensor classes but does not define placement |
| Pressure excluded from scope | IHAP-45 firmware and publication policy | Partial | Prevents scope expansion only |

Planned actions belong in Risk Treatments, not here.

---

## 6. Risk Treatment Summary

| Treatment ID | Title | Strategy | Lifecycle status | Jira | ADR | Last review |
|---|---|---|---|---|---|---|
| RT-R011-01 | Define and verify environmental sensor placement profile | Mitigate | Proposed | IHAP-51 / IHAP-50 coordination | ADR-0002 | 2026-07-16 |

---

## 7. Risk Treatments

### RT-R011-01 — Define and verify environmental sensor placement profile

**Strategy:** Mitigate  
**Lifecycle status:** Proposed  
**Treatment owner:** Hardware and enclosure workstream  
**Jira coordination:** IHAP-51 with IHAP-50 wiring input  
**Related ADRs:** ADR-0002  
**Introduced:** 2026-07-16  
**Last reviewed:** 2026-07-16  
**Next review trigger:** Final enclosure prototype or material change to sensor profile, wiring length or mounting location

#### Rationale

A repeatable physical placement profile is required to keep readings representative of the intended ambient environment and comparable across nodes. The correct vent geometry, separation distance and installation constraints remain `[UNVALIDATED]` until tested with the actual enclosure and wiring.

#### Planned Controls or Actions

- define profile-specific mounting rules for DHT11 and BME280;
- separate the sensing element from ESP32-C3 and regulator heat where practical;
- define vent openings and airflow path without direct drafts;
- prohibit contact with walls, wet surfaces and condensation-prone areas;
- define minimum separation from heat, cold and moisture sources;
- document orientation and cable-length constraints;
- repeat stable-baseline and controlled-transition checks in the enclosure prototype;
- compare enclosure readings with an independent reference when available;
- document threshold and hysteresis guidance for the DHT11 standard profile.

These are planned actions until implementation evidence exists.

#### Scope Coverage

| Risk cause or consequence | Coverage | Rationale |
|---|---|---|
| ESP32/regulator self-heating | Partial | Placement and thermal separation can reduce but not necessarily eliminate coupling |
| Restricted or directed airflow | Partial | Vent and mounting rules reduce local stagnation and drafts |
| Condensation and moisture contact | Partial | Installation rules and stop conditions reduce exposure but cannot control all environments |
| Inconsistent installation across nodes | Partial | A documented profile improves repeatability; field compliance remains to be verified |
| Absolute sensor accuracy | None | Requires independent reference and potentially calibration, outside this treatment's guarantee |

#### Remaining Exposure

Unit-to-unit variation, sensor aging, contamination, unusual room airflow and absence of calibrated reference remain. Outdoor installations may need additional weather shielding and validation beyond the standard room enclosure.

#### Source and Evidence Register

| ID | Source | Source type | Supports | Version / applicability | Verification | Checked on | Limitations |
|---|---|---|---|---|---|---|---|
| SRC-01 | `docs/evidence/IHAP-45/summaries/environmental-IHAP45-RUN-01.summary.json` | Internal evidence | Observed inter-sensor differences and transition behavior | Owned specimens, executed setup | Verified | 2026-07-16 | Relative comparison only; no independent reference |
| SRC-02 | `tools/hardware-validation/ihap-45-environmental-sensors/README.md` | Project docs | Co-location and safety constraints used for the comparative run | IHAP-45 harness | Verified | 2026-07-16 | Not a final enclosure specification |
| SRC-03 | `docs/adr/ADR-0002-environmental-sensor-profiles.md` | Project decision | Profile selection and remaining placement dependency | ADR-0002 | Verified | 2026-07-16 | Does not verify treatment effectiveness |

#### Implementation and Verification Evidence

| Evidence ID | Evidence | Evidence class | Expected result | Actual result | Status | Date |
|---|---|---|---|---|---|---|
| EV-01 | IHAP-51 enclosure and placement validation | Verification | Stable, repeatable readings without unacceptable self-heating, airflow or condensation bias | Not executed | `[UNVALIDATED]` | 2026-07-16 |

`Implemented` requires implementation evidence. `Verified` requires verification evidence and an effectiveness review.

#### Treatment Effectiveness Review

**Review date:** Pending  
**Evidence reviewed:** EV-01 pending  
**Effectiveness:** Pending Evidence  
**Likelihood after treatment:** Pending Evidence  
**Impact after treatment:** Pending Evidence  
**Residual risk:** Pending Evidence  
**Remaining exposure:** Unit variation, aging, contamination, field installation and absolute accuracy  
**Project Owner decision required:** Yes

This review does not accept, defer, or reject residual risk by itself.

---

## 8. Traceability

| Relationship | Link | Effect / Rule |
|---|---|---|
| Jira treatment task | IHAP-51 / IHAP-50 | Operational coordination only |
| Pull request | [PR #28](https://github.com/pianic2/homeedge-ai-platform/pull/28) | Adds risk record and proposed treatment; not verification evidence |
| Related ADR | `docs/adr/ADR-0002-environmental-sensor-profiles.md` | Partially mitigates inappropriate profile selection; leaves placement exposure unresolved |
| Related risks | None | Keep distinct from power, wiring and generic claim risks |
| Related policy or test | `docs/evidence/IHAP-45/`; `tools/hardware-validation/ihap-45-environmental-sensors/` | Comparative evidence and reproducible method |

---

## 9. Stakeholder Visibility

| Item | Rule | Rationale |
|---|---|---|
| Risk summary | Show | Physical measurement bias is relevant to decision quality |
| Treatment summary | Show | Planned placement verification is understandable and non-sensitive |
| Technical implementation | Link | Detailed enclosure and test evidence should remain in GitHub |
| Secrets, private topology, personal or domestic data | Block / Redact | None is required to communicate this risk |
| Maturity claim | Keep `[UNVALIDATED]` where evidence is missing | Final enclosure fitness and absolute accuracy are unproven |

Stakeholder-safe wording:

```text
Environmental readings can be affected by sensor placement and enclosure design. The project has selected sensor profiles, but final placement effectiveness remains to be verified with the enclosure prototype.
```

Confluence may summarize and link only. It must not duplicate this dossier.

---

## 10. Assessment History

| Date | Change | Treatment | Evidence | Decision |
|---|---|---|---|---|
| 2026-07-16 | Risk identified from IHAP-45 comparative evidence; treatment proposed | RT-R011-01 | SRC-01 through SRC-03 | Pending Project Owner residual-risk decision |

---

## 11. Review Notes

```text
[x] GitHub remains the canonical risk and treatment dossier.
[x] Jira coordinates work, status, blockers, and evidence links only.
[x] Confluence summarizes and links only.
[x] Existing controls are separated from planned actions.
[x] Every treatment has a stable RT-* ID.
[x] Sources identify the supported claim, verification state, date, and applicability.
[x] Implementation evidence and verification evidence are separate.
[x] Implemented is not treated as Verified.
[x] [UNVALIDATED] is preserved where proof is missing.
[x] Related Jira tasks and ADRs are linked in both directions when applicable.
[x] Review triggers and orphan indicators were checked.
[x] The ADR exists because a stable sensor-profile decision was required, not automatically because this risk exists.
[x] No production-ready, commercial-ready, security-grade, certified, safety-critical, alarm-grade, antifurto, access-control, intrusion-detection, or protection claim was introduced.
[x] No residual-risk acceptance, deferral, rejection or closure is claimed.
```

---

## 12. Practical Rule

```text
Select the appropriate sensor profile in ADR-0002.
Verify the physical placement and enclosure in IHAP-51.
Keep raw telemetry local and publish reviewed aggregate evidence only.
Leave residual-risk decisions to the Project Owner.
```

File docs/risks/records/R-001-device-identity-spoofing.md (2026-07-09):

# R-001 — Device Identity Spoofing

**Status:** Draft  
**Project:** [ITS] [EDGE] HomeEdge AI Platform  
**Jira:** IHAP-16  
**Owner decision:** Pending Project Owner  
**Decision state:** Pending Project Owner  
**Risk type:** Security / Technical  
**Source of truth:** This GitHub risk record until superseded by a later reviewed change.

<!--
AI_AGENT_METADATA:
  risk_id: R-001
  canonical_path: docs/risks/records/R-001-device-identity-spoofing.md
  risk_model: docs/risks/risk-model-baseline.md
  product_boundary: docs/product/product-vision.md
  risk_acceptance_authority: project_owner
  runtime_changes_allowed: false
  adr_created: false
  unvalidated_claim_marker: "[UNVALIDATED]"
-->

---

## 1. Risk Statement

There is a risk that a fake, cloned, or unknown device is treated as trusted because device identity and registry behavior are target boundaries `[UNVALIDATED]` until implemented and tested.

---

## 2. Source Trigger

The MVP has an ESP32-class room/door node and target service boundaries for ingestion and device registry. The device registry is not yet runtime-proven.

This risk is not theoretical noise: every edge-to-backend system eventually needs to decide whether an incoming device should be trusted.

---

## 3. Affected Assets and Trust Boundary

| Area | Detail |
|---|---|
| Asset | ESP32 room/door node, device id, event payload, ingestion target, device registry target. |
| Trust boundary | Device -> network -> ingestion -> registry/read model. |
| Data involved | Device id, room id, firmware version, timestamp, telemetry fields. |
| Stakeholder surface | Risk summary may be shown; implementation detail should be linked, not copied. |

---

## 4. Scoring

| Field | Value | Rationale |
|---|---|---|
| Likelihood | Medium | No runtime identity control exists yet; current service boundaries are target only. |
| Impact | High | Fake device data can corrupt telemetry, read models, stakeholder evidence, and future automation assumptions. |
| Residual risk | Pending evidence | No implemented registry/auth evidence exists yet. |
| Treatment proposal | Mitigate | Future implementation should define known-device registration, request validation, and rejected-device handling. |
| Decision state | Pending Project Owner | No acceptance, deferral, or rejection has been approved. |

---

## 5. Existing Controls

- MVP boundary limits scope to one generic room/door node.
- Target services remain `[UNVALIDATED]` instead of being claimed as implemented.
- Stakeholder reports must not overstate security maturity.

---

## 6. Evidence Gap

Missing evidence:

- device registration model;
- accepted/rejected device behavior;
- ingestion validation logic;
- tests or logs proving unknown-device rejection;
- documented error handling.

Until evidence exists, device identity security remains `[UNVALIDATED]`.

---

## 7. Mitigation Proposal

Future implementation should define:

- stable device identifier format;
- known-device registry boundary;
- request validation at ingestion;
- behavior for unknown, disabled, or malformed device identity;
- audit/log evidence without exposing private domestic details.

No ADR is introduced by this record.

---

## 8. Stakeholder Visibility

| Item | Rule |
|---|---|
| Risk summary | Show allowed. |
| Device identity design | Link only when implemented. |
| Secrets, tokens, private topology | Blocked. |
| Security maturity claim | Keep `[UNVALIDATED]`; no security-grade wording. |

Stakeholder-safe wording:

```text
Device identity is a known risk area and remains [UNVALIDATED] until the registry and ingestion behavior are implemented and tested.
```

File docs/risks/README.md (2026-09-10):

# Risk Documentation

**Issue:** IHAP-16 — S0-007 — Risk Model Baseline; extended by IHAP-39 — S0-029 — Risk Treatment Workflow and Traceability  
**Project:** [ITS] [EDGE] HomeEdge AI Platform  
**Document type:** Risk documentation index  
**Status:** Sprint 0 draft for review  
**Reading target:** less than 2 minutes for humans.  
**Source of truth:** This index routes risk documentation under `docs/risks/`. It does not accept risk or replace Project Owner decisions.

<!--
AI_AGENT_METADATA:
  issue: IHAP-39
  document_type: risk_documentation_index
  canonical_path: docs/risks/README.md
  risk_model_baseline: docs/risks/risk-model-baseline.md
  risk_records_path: docs/risks/records/
  risk_assessment_template: docs/templates/risk-assessment.md
  jira_role: operational_coordination_only
  confluence_role: stakeholder_summary_and_navigation_only
  risk_acceptance_authority: project_owner
  unvalidated_claim_marker: "[UNVALIDATED]"
-->

---

## 1. Purpose

This folder contains versioned risk documentation for HomeEdge AI Platform. Risk/treatment truth lives in each Risk Record; Jira coordinates work; Confluence may summarize/link only; the Project Owner decides treatment approval and residual risk where required.

---

## 2. Current Documents

| Need | Use | Rule |
|---|---|---|
| Risk and treatment model | `risk-model-baseline.md` | Defines lifecycle, source verification, traceability, orphan rules and decision boundaries. |
| Concrete Risk Records | `records/` | Canonical living dossiers. |
| Risk Record template | `../templates/risk-assessment.md` | Use for explicit risk work. |
| ADR relationship | `../adr/template.md` | Use only when a stable architectural decision is required. |

---

## 3. Current Risk Records

| ID | Record | Primary category | Treatment state | Decision state |
|---|---|---|---|---|
| R-001 | `records/R-001-device-identity-spoofing.md` | Security / Technical | To be reviewed by IHAP-40 | Pending Project Owner |
| R-002 | `records/R-002-event-payload-leakage.md` | Security / Privacy | To be reviewed by IHAP-40 | Pending Project Owner |
| R-003 | `records/R-003-technical-metadata-inference.md` | Privacy / Stakeholder Visibility | To be reviewed by IHAP-40 | Pending Project Owner |
| R-004 | `records/R-004-presence-door-state-misinterpretation.md` | Privacy / Compliance / Claims | To be reviewed by IHAP-40 | Pending Project Owner |
| R-005 | `records/R-005-target-boundary-overclaim.md` | Compliance / Documentation | To be reviewed by IHAP-40 | Pending Project Owner |
| R-006 | `records/R-006-source-of-truth-drift.md` | Documentation / Stakeholder Visibility | To be reviewed by IHAP-40 | Pending Project Owner |
| R-007 | `records/R-007-ai-inference-profiling.md` | AI / Privacy | To be reviewed by IHAP-40 | Pending Project Owner |
| R-008 | `records/R-008-cost-abuse.md` | Cost / Technical | To be reviewed by IHAP-40 | Pending Project Owner |
| R-009 | `records/R-009-stakeholder-maturity-misread.md` | Stakeholder Visibility / Claims | To be reviewed by IHAP-40 | Pending Project Owner |
| R-010 | `records/R-010-risk-driven-scope-creep.md` | Documentation / Compliance | To be reviewed by IHAP-40 | Pending Project Owner |
| R-011 | `records/R-011-environmental-sensor-placement-bias.md` | Technical / Claims | RT-R011-01 Proposed | Pending Project Owner |
| R-012 | `records/R-012-unprotected-li-ion-battery-fault.md` | Technical | **RT-R012-01 Proposed** | Pending Project Owner |
| R-013 | `records/R-013-edge-power-rail-transfer-integrity.md` | Technical | **RT-R013-01 Proposed** | Pending Project Owner |

R-012 and R-013 were introduced by IHAP-56 after post-merge review of ADR-0007. Their canonical Category fields use only the vocabulary defined by `risk-model-baseline.md`; compliance/claim or data-integrity consequences are recorded in each dossier's rationale/stakeholder surface instead of inventing category values. Their treatment lifecycle remains **Proposed** because ADR-0007/PR #34 acceptance predates those treatment records and is not valid approval evidence for them.

The latest IHAP-56 closure sweep also preserves explicit treatment boundaries: R-012 cannot claim over-current coverage for conductors upstream of the source-side interruption element, and R-013 cannot claim verified 5 V/3.3 V/backfeed/thermal/transfer effectiveness before approved implementation evidence. `../evidence/IHAP-49/ihap-56-closure-matrix.md` routes Accepted-vs-Proposed state but does not approve either treatment.

IHAP-55 is the intended implementation/verification owner after applicable approval; IHAP-57 coordinates later lifecycle/effectiveness updates after an explicit treatment decision and physical evidence.

---

## 4. Navigation Rule

```text
Risk Record -> Risk Treatment -> Jira coordination -> optional ADR -> evidence -> effectiveness review -> Project Owner decision
```

---

## 5. Surface Rules

```text
GitHub Risk Records define risk and treatment truth.
Jira coordinates work and links evidence.
ADRs document stable architectural decisions when required.
Confluence summarizes and links for stakeholders.
Project Owner decides treatment approval and residual risk.
```

Preserve `[UNVALIDATED]` where evidence is missing.

---

## 6. Orphan Review

A record requires review when it lacks a treatment, monitoring, explicit decision, current source verification, required Jira coordination, or current effectiveness review.

R-011 is not orphaned because RT-R011-01 is Proposed with coordination and review trigger.

R-012 and R-013 are not orphaned: each has a **Proposed** treatment, IHAP-55/IHAP-57 coordination, inverse ADR-0007 links with an allowed ADR effect, explicit approval boundaries and Pending Evidence state. Proposed treatment status does not imply approval, implementation, verification or risk acceptance.

---

## 7. Practical Rule

```text
The README is the index.
The baseline is the model.
The records carry the living analysis and treatments.
Jira coordinates.
The Project Owner decides.
```

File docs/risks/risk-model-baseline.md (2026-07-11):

# Risk Model Baseline

**Issue:** IHAP-16 — S0-007 — Risk Model Baseline; extended by IHAP-39 — S0-029 — Risk Treatment Workflow and Traceability  
**Project:** [ITS] [EDGE] HomeEdge AI Platform  
**Document type:** Risk governance / modeling guide  
**Status:** Sprint 0 draft for review  
**Reading target:** less than 5 minutes for humans; hidden metadata supports AI routing and anti-regression checks.  
**Source of truth:** This versioned GitHub document defines how project risks and treatments are modeled until superseded by a later reviewed change.

<!--
AI_AGENT_METADATA:
  issue: IHAP-39
  document_type: risk_model_baseline
  canonical_path: docs/risks/risk-model-baseline.md
  source_of_truth: github_versioned_repository_documentation
  risk_index: docs/risks/README.md
  risk_records_path: docs/risks/records/
  risk_assessment_template: docs/templates/risk-assessment.md
  adr_template: docs/adr/template.md
  jira_role: operational_coordination_only
  confluence_role: stakeholder_summary_and_navigation_only
  task_scope: documentation_governance_only
  runtime_changes_allowed: false
  autonomous_decision_authority: false
  risk_acceptance_authority: project_owner
  unvalidated_claim_marker: "[UNVALIDATED]"

HIDDEN_ANTI_REGRESSION_RULES:
  - The Risk Record is the canonical technical dossier for the risk and its treatments.
  - Jira coordinates treatment work, blockers, workflow state, and evidence links; it must not replace treatment truth.
  - ADRs are created only for stable architectural decisions and never automatically for every risk.
  - Confluence may summarize and link; it must not duplicate risk records or ADRs.
  - Implemented does not mean Verified.
  - No residual risk is accepted, deferred, or rejected without Project Owner decision evidence.
  - Preserve [UNVALIDATED] where implementation or effectiveness evidence is missing.
-->

---

## 1. Operating Rule

```text
The Risk Record is the canonical treatment dossier.
Jira coordinates treatment work.
ADRs record stable architectural decisions only when needed.
Evidence proves implementation and effectiveness.
The Project Owner alone decides residual-risk acceptance, deferral, or rejection.
```

This file defines the model. `docs/risks/README.md` is the index. Concrete records live under `docs/risks/records/`.

---

## 2. Required Risk Fields

Every concrete risk record must define:

| Field | Rule |
|---|---|
| Risk statement | One sentence: “There is a risk that ... because ...”. |
| Source trigger | Why the risk exists in the current project scope. |
| Affected assets | Device, payload, metadata, service, stakeholder, or governance surface. |
| Trust boundary | Where the risk can materialize. |
| Category | Technical, Security, Privacy, Compliance / Claims, Cost, Documentation, Stakeholder Visibility, or AI / Inference. |
| Current assessment | Likelihood, impact, residual risk, evidence gap, and decision state. |
| Existing controls | Only controls currently present and supported by evidence. |
| Treatments | One or more stable `RT-*` entries, monitoring, or explicit Project Owner decision. |
| Stakeholder visibility | Show, link, redact, or block. |
| Review history | Human-readable summary of material changes; Git preserves the full history. |

---

## 3. Risk and Decision States

| Field | Values |
|---|---|
| Risk status | Newly Identified / Under Treatment / Monitoring / Decision Pending / Closed |
| Likelihood | Low / Medium / High |
| Impact | Low / Medium / High |
| Residual risk | Low / Medium / High / Pending Evidence |
| Owner decision | Pending / Accepted / Deferred / Rejected |

Risk status and owner decision are separate. A risk may be `Under Treatment` while the owner decision remains `Pending`.

`Closed` requires traceable decision evidence and does not follow automatically from a closed Jira task.

---

## 4. Risk Treatment Model

A Risk Treatment is a versioned plan and evidence trail inside the Risk Record. It may coordinate one or more Jira tasks and may reference zero, one, or more ADRs.

### 4.1 Stable identifier

```text
RT-<RISK_ID>-<SEQUENCE>
```

Example: `RT-R001-01`.

The identifier remains stable when the treatment is revised. A materially different treatment receives a new sequence.

### 4.2 Strategy

Allowed strategies:

- Mitigate;
- Avoid;
- Transfer;
- Monitor;
- Candidate Accept.

`Candidate Accept` only prepares a decision request. It does not accept the risk.

### 4.3 Lifecycle

```text
Proposed -> Approved -> In Progress -> Implemented -> Verified
```

Alternative terminal or review states:

- Ineffective;
- Superseded;
- Withdrawn.

Rules:

- `Approved` requires explicit approval evidence for the treatment scope;
- `Implemented` requires implementation evidence;
- `Verified` requires verification evidence and an effectiveness review;
- `Implemented` never implies `Verified`;
- treatment lifecycle changes never accept, defer, or reject residual risk automatically.

### 4.4 Minimum treatment content

Each treatment must record:

- stable treatment ID and title;
- strategy and lifecycle status;
- rationale and scope coverage;
- uncovered exposure;
- operational owner or role;
- Jira coordination link when work is required;
- related ADRs or `None`;
- source register;
- implementation and verification evidence;
- effectiveness review;
- introduced date, last review, and next review trigger.

---

## 5. Source and Evidence Model

Sources justify why a treatment is appropriate. Evidence demonstrates what was implemented and whether it worked. They are not interchangeable.

### 5.1 Evidence classes

| Class | Purpose |
|---|---|
| Source evidence | Supports the treatment rationale or control design. |
| Implementation evidence | Shows that planned work exists or was performed. |
| Verification evidence | Shows observed behavior against an expected result. |
| Decision evidence | Records Project Owner acceptance, deferral, rejection, or treatment approval where required. |

### 5.2 Preferred source order

1. official standards and regulations;
2. official vendor or technology documentation;
3. institutional publications;
4. peer-reviewed research;
5. primary project documentation;
6. internal tests, logs, measurements, and reproductions;
7. secondary sources only as support.

Blogs, forums, promotional material, and AI-generated output must not be the sole primary basis for a material treatment decision.

### 5.3 Source verification states

- Verified;
- Partially Verified;
- Pending Verification;
- Obsolete;
- Rejected.

Every source must identify the claim it supports, version or applicability when relevant, checked date, and limitations. A generic homepage link is not sufficient evidence.

Missing implementation or effectiveness evidence preserves `[UNVALIDATED]`.

---

## 6. Many-to-Many Traceability

The model supports:

- one risk with multiple treatments;
- one treatment coordinating multiple Jira tasks;
- one treatment referencing multiple ADRs;
- one ADR affecting multiple risks or treatments.

Every relationship must be explicit in the Risk Record. When an ADR affects a documented risk, the ADR must declare the linked risk, linked treatment, and effect. The Risk Record must contain the inverse link.

Allowed ADR effects:

- mitigates;
- partially mitigates;
- transfers;
- avoids;
- introduces;
- leaves unresolved;
- supersedes a previous treatment decision.

An ADR never closes a risk by itself.

---

## 7. Orphan Risk and Anti-Orphan Rule

A newly recorded risk starts as:

```text
Newly Identified — Treatment Triage Required
```

It is not immediately orphaned while triage is active.

A risk is orphan when it is canonical but lacks an adequate treatment, monitoring, review, or decision path. Indicators include:

- no `RT-*` entry and no Project Owner decision;
- work is required but no Jira coordination link exists;
- Jira, ADR, PR, or evidence exists but is not linked from the Risk Record;
- a treatment is marked `Implemented` without implementation evidence;
- a treatment is marked `Verified` without verification evidence;
- sources are missing, obsolete, rejected, or unrelated to the supported claim;
- a review trigger occurred without reassessment;
- residual risk changed without a documented effectiveness review.

Anti-orphan requirement: every canonical risk must have at least one of:

- a proposed or active treatment;
- formal monitoring with a review trigger;
- a Project Owner decision;
- explicit deferral with a tracked follow-up.

No arbitrary day-based deadline is introduced by this baseline. The applicable governance gate determines when triage must be resolved.

---

## 8. Jira Risk Treatment Task

Jira coordinates the work; it does not replace the canonical treatment dossier.

Minimum task content:

- summary with treatment ID;
- Risk Record link;
- treatment goal, scope, and non-scope;
- current treatment lifecycle state;
- expected source, implementation, and verification evidence;
- related ADR or ADR candidate status;
- Project Owner decision requirement;
- completion condition requiring the Risk Record to be updated.

Closing a Jira task does not automatically mean the treatment is verified, effective, or accepted.

---

## 9. Stakeholder Proposal Flow

```text
Stakeholder proposal
-> Jira or Confluence intake
-> technical triage and duplicate check
-> source review
-> GitHub Risk Record proposal
-> PR review
-> canonical creation, merge, or rejection
```

A stakeholder proposal does not automatically:

- create a canonical risk;
- create a treatment task;
- create an ADR;
- change residual risk;
- change MVP scope.

Confluence may show proposal state and links only. Technical truth becomes canonical only through reviewed GitHub change.

---

## 10. Review and History

Every material treatment review records:

- review date;
- evidence reviewed;
- effectiveness: Effective / Partially Effective / Ineffective / Pending Evidence;
- likelihood and impact after treatment;
- residual risk;
- remaining exposure;
- whether Project Owner decision is required.

The Risk Record contains a short assessment history. Git history remains the full revision history.

Review triggers may include:

- implementation completion;
- failed or changed test results;
- incident or new threat information;
- architecture or dependency change;
- source becoming obsolete;
- scheduled review date;
- stakeholder evidence that changes the risk statement.

---

## 11. Review Checklist

```text
[ ] Risk statement, source trigger, assets, and trust boundary are explicit.
[ ] Existing controls are separated from planned treatments.
[ ] Every treatment has a stable RT-* ID, strategy, status, coverage, and remaining exposure.
[ ] Sources identify the supported claim, verification state, date, and applicability.
[ ] Implementation and verification evidence are separate.
[ ] Implemented is not treated as Verified.
[ ] Missing proof preserves [UNVALIDATED].
[ ] Jira coordinates work but does not replace treatment truth.
[ ] ADRs are linked only when a stable architectural decision is relevant.
[ ] Risk, treatment, Jira, ADR, and evidence links are bidirectional where applicable.
[ ] Orphan indicators and review triggers are checked.
[ ] Project Owner decision evidence exists before Accepted, Deferred, Rejected, or Closed.
[ ] No runtime, firmware, backend, mobile, cloud, schema, or security enforcement is introduced by the record.
[ ] No forbidden production, commercial, security-grade, safety-critical, alarm, antifurto, certification, access-control, intrusion-detection, or protection claim is introduced.
```

---

## 12. Practical Rule

```text
The baseline defines the model.
The Risk Record carries the living treatment dossier.
Jira coordinates work.
Evidence carries proof.
The Project Owner carries the residual-risk decision.
```

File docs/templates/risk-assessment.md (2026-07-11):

# Risk Assessment — <Short Title>

**Risk ID:** R-XXX  
**Risk status:** Newly Identified / Under Treatment / Monitoring / Decision Pending / Closed  
**Current assessment date:** YYYY-MM-DD  
**Last reviewed:** YYYY-MM-DD  
**Next review:** YYYY-MM-DD / Event-driven  
**Project:** [ITS] [EDGE] HomeEdge AI Platform  
**Jira:** IHAP-XX  
**PR:** <link when available>  
**Owner decision:** Pending / Accepted / Deferred / Rejected

<!--
AI_AGENT_METADATA:
  issue: IHAP-39
  document_type: risk_assessment_template
  canonical_path: docs/templates/risk-assessment.md
  source_of_truth: github_versioned_repository_documentation
  template_output_target: docs/risks/records/
  jira_role: operational_coordination_only
  confluence_role: stakeholder_summary_and_navigation_only
  task_scope: documentation_governance_only
  runtime_changes_allowed: false
  risk_acceptance_authority: project_owner
  unvalidated_claim_marker: "[UNVALIDATED]"

HIDDEN_ANTI_REGRESSION_RULES:
  - This file is a template, not an actual risk record.
  - Risk Records are living technical dossiers; Git preserves full history.
  - Treatment details belong in the Risk Record, not only in Jira.
  - Implemented does not mean Verified.
  - Risk acceptance, rejection, or deferral requires Project Owner decision evidence.
  - Preserve [UNVALIDATED] on unproven implementation or effectiveness claims.
-->

---

## 1. Risk Statement

```text
There is a risk that ... because ...
```

Keep unproven claims marked with `[UNVALIDATED]`.

---

## 2. Source Trigger and Scope

**Source trigger:** Describe the concrete project condition that exposes the risk.

**In scope:**

- ...

**Out of scope:**

- ...

This record does not introduce firmware, backend, mobile, cloud, runtime, security enforcement, or unsupported maturity claims.

---

## 3. Affected Assets and Trust Boundary

| Area | Detail |
|---|---|
| Assets | ... |
| Trust boundary | ... |
| Data involved | ... |
| Stakeholder surface | ... |

---

## 4. Current Assessment

| Field | Value | Rationale |
|---|---|---|
| Category | Technical / Security / Privacy / Compliance / Claims / Cost / Documentation / Stakeholder Visibility / AI | ... |
| Likelihood | Low / Medium / High | ... |
| Impact | Low / Medium / High | ... |
| Residual risk | Low / Medium / High / Pending Evidence | ... |
| Evidence gap | `[UNVALIDATED]` or linked evidence | ... |
| Decision state | Pending Project Owner / Accepted / Deferred / Rejected | ... |

---

## 5. Existing Controls

List only controls that currently exist and have evidence.

| Control | Evidence | Coverage | Limitation |
|---|---|---|---|
| ... | <link or `[UNVALIDATED]`> | Full / Partial | ... |

Planned actions belong in Risk Treatments, not here.

---

## 6. Risk Treatment Summary

| Treatment ID | Title | Strategy | Lifecycle status | Jira | ADR | Last review |
|---|---|---|---|---|---|---|
| RT-RXXX-01 | ... | Mitigate / Avoid / Transfer / Monitor / Candidate Accept | Proposed / Approved / In Progress / Implemented / Verified / Ineffective / Superseded / Withdrawn | IHAP-XX / Pending approval | None / ADR-XXX / Candidate | YYYY-MM-DD |

---

## 7. Risk Treatments

Repeat this subsection for every treatment.

### RT-RXXX-01 — <Treatment title>

**Strategy:** Mitigate / Avoid / Transfer / Monitor / Candidate Accept  
**Lifecycle status:** Proposed / Approved / In Progress / Implemented / Verified / Ineffective / Superseded / Withdrawn  
**Treatment owner:** <role or team>  
**Jira coordination:** IHAP-XX / Pending Project Owner approval / Not required  
**Related ADRs:** ADR-XXX / Candidate / None  
**Introduced:** YYYY-MM-DD  
**Last reviewed:** YYYY-MM-DD  
**Next review trigger:** <date, milestone, evidence, incident, dependency, or architecture change>

#### Rationale

Explain why this treatment is appropriate and which assumptions remain `[UNVALIDATED]`.

#### Planned Controls or Actions

- ...

These are planned actions until implementation evidence exists.

#### Scope Coverage

| Risk cause or consequence | Coverage | Rationale |
|---|---|---|
| ... | Full / Partial / None | ... |

#### Remaining Exposure

Describe what this treatment does not address.

#### Source and Evidence Register

| ID | Source | Source type | Supports | Version / applicability | Verification | Checked on | Limitations |
|---|---|---|---|---|---|---|---|
| SRC-01 | <title and link/path> | Standard / Official docs / Institution / Research / Project docs / Internal evidence / Secondary | <specific claim> | ... | Verified / Partially Verified / Pending Verification / Obsolete / Rejected | YYYY-MM-DD | ... |

A generic homepage link is not sufficient. Blog, forum, promotional, or AI-generated content must not be the sole primary support for a material treatment decision.

#### Implementation and Verification Evidence

| Evidence ID | Evidence | Evidence class | Expected result | Actual result | Status | Date |
|---|---|---|---|---|---|---|
| EV-01 | <PR, test, log, report, or review> | Implementation / Verification / Decision | ... | ... / Not executed | `[UNVALIDATED]` / Passed / Failed / Partial | YYYY-MM-DD |

`Implemented` requires implementation evidence. `Verified` requires verification evidence and an effectiveness review.

#### Treatment Effectiveness Review

**Review date:** YYYY-MM-DD  
**Evidence reviewed:** EV-XX  
**Effectiveness:** Effective / Partially Effective / Ineffective / Pending Evidence  
**Likelihood after treatment:** Low / Medium / High / Pending Evidence  
**Impact after treatment:** Low / Medium / High / Pending Evidence  
**Residual risk:** Low / Medium / High / Pending Evidence  
**Remaining exposure:** ...  
**Project Owner decision required:** Yes / No

This review does not accept, defer, or reject residual risk by itself.

---

## 8. Traceability

| Relationship | Link | Effect / Rule |
|---|---|---|
| Jira treatment task | IHAP-XX | Operational coordination only |
| Pull request | <link> | Implementation evidence only when relevant |
| Related ADR | `docs/adr/ADR-XXXX-*.md` / None | Mitigates / Partially mitigates / Transfers / Avoids / Introduces / Leaves unresolved / Supersedes |
| Related risks | R-XXX / None | State the shared boundary; do not merge distinct risk records |
| Related policy or test | <path/link> | ... |

Every applicable relationship must also be declared by the linked ADR or record when that artifact supports inverse links.

---

## 9. Stakeholder Visibility

| Item | Rule | Rationale |
|---|---|---|
| Risk summary | Show / Link / Redact / Block | ... |
| Treatment summary | Show / Link / Redact / Block | ... |
| Technical implementation | Show / Link / Redact / Block | ... |
| Secrets, private topology, personal or domestic data | Block / Redact | ... |
| Maturity claim | Keep `[UNVALIDATED]` where evidence is missing | ... |

Stakeholder-safe wording:

```text
...
```

Confluence may summarize and link only. It must not duplicate this dossier.

---

## 10. Assessment History

Record material changes only. Git preserves the full history.

| Date | Change | Treatment | Evidence | Decision |
|---|---|---|---|---|
| YYYY-MM-DD | Risk identified / treatment proposed / control implemented / effectiveness reviewed / source invalidated | RT-RXXX-01 / None | SRC-XX / EV-XX / None | Pending / linked Project Owner decision |

---

## 11. Review Notes

```text
[ ] GitHub remains the canonical risk and treatment dossier.
[ ] Jira coordinates work, status, blockers, and evidence links only.
[ ] Confluence summarizes and links only.
[ ] Existing controls are separated from planned actions.
[ ] Every treatment has a stable RT-* ID.
[ ] Sources identify the supported claim, verification state, date, and applicability.
[ ] Implementation evidence and verification evidence are separate.
[ ] Implemented is not treated as Verified.
[ ] [UNVALIDATED] is preserved where proof is missing.
[ ] Related Jira tasks and ADRs are linked in both directions when applicable.
[ ] Review triggers and orphan indicators were checked.
[ ] No ADR was created automatically.
[ ] No production-ready, commercial-ready, security-grade, certified, safety-critical, alarm-grade, antifurto, access-control, intrusion-detection, or protection claim was introduced.
[ ] Project Owner decision evidence exists before Accepted, Deferred, Rejected, or Closed.
```

---

## 12. Practical Rule

```text
Document the treatment in the Risk Record.
Coordinate the work in Jira.
Use ADRs only for stable architectural decisions.
Require evidence before effectiveness claims.
Leave residual-risk decisions to the Project Owner.
```

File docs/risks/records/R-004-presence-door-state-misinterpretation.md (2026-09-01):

# R-004 — Presence and Door State Misinterpretation

**Status:** Draft  
**Project:** [ITS] [EDGE] HomeEdge AI Platform  
**Jira:** IHAP-16  
**Owner decision:** Pending Project Owner  
**Decision state:** Pending Project Owner  
**Risk type:** Privacy / Compliance / Claims  
**Source of truth:** This GitHub risk record until superseded by a later reviewed change.

<!--
AI_AGENT_METADATA:
  risk_id: R-004
  canonical_path: docs/risks/records/R-004-presence-door-state-misinterpretation.md
  risk_model: docs/risks/risk-model-baseline.md
  product_boundary: docs/product/product-vision.md
  stakeholder_report_rules: docs/governance/stakeholder-report-data-rules.md
  claim_boundaries_preserved: true
  risk_acceptance_authority: project_owner
  runtime_changes_allowed: false
  related_adrs:
    - docs/adr/ADR-0003-mvp-door-state-sensor.md
    - docs/adr/ADR-0005-mvp-presence-sensor.md
  adr_created: true
  adr_statuses:
    ADR-0003: Accepted
    ADR-0005: Proposed
  unvalidated_claim_marker: "[UNVALIDATED]"
-->

---

## 1. Risk Statement

There is a risk that local presence state or door open/closed telemetry is misinterpreted as person tracking, access control, intrusion detection, alarm-grade behavior, antifurto behavior, safety-critical monitoring, or protection evidence.

---

## 2. Source Trigger

The MVP includes local non-identifying presence state and door open/closed state. These are allowed only as telemetry/local state. They are not certified access control, intrusion detection, alarm-grade security, or safety-critical evidence.

---

## 3. Affected Assets and Trust Boundary

| Area | Detail |
|---|---|
| Asset | Presence state, door state, Product Vision wording, stakeholder reports, demos. |
| Trust boundary | Technical telemetry -> stakeholder interpretation. |
| Data involved | Boolean/state signals for presence and door open/closed. |
| Stakeholder surface | Summary allowed only with telemetry-safe wording. |

---

## 4. Scoring

| Field | Value | Rationale |
|---|---|---|
| Likelihood | High | Door and presence wording is easy to overread as security/safety functionality. |
| Impact | High | Misleading claim could violate project claim boundaries and create stakeholder confusion. |
| Residual risk | High | Risk remains until every stakeholder-facing surface consistently uses telemetry-safe wording. |
| Treatment proposal | Reject | Block alarm, antifurto, access-control, intrusion-detection, safety, and protection claims. |
| Decision state | Pending Project Owner | No residual risk acceptance exists. |

---

## 5. Existing Controls

- Product Vision defines presence as local, non-identifying room-level state.
- Product Vision defines door state as telemetry only.
- Stakeholder rules block production, safety, alarm, antifurto, certified access-control, certified intrusion-detection, and protection claims.

---

## 6. Evidence Gap

Missing evidence:

- final stakeholder wording review for every Confluence report;
- demo text review before publication;
- implementation evidence proving only allowed telemetry fields are emitted;
- tests preventing identity/tracking fields if schema is later introduced.

---

## 7. Mitigation Proposal

Mitigation is wording and scope control:

- always call door state “telemetry” or “state”; never “access control”;
- always call presence “local non-identifying room state”; never “person tracking”;
- block antifurto/alarm/protection phrasing;
- keep safety/security capability claims `[UNVALIDATED]` unless future reviewed evidence and Project Owner decision exist.

---

## 8. Stakeholder Visibility

| Item | Rule |
|---|---|
| Risk summary | Show allowed. |
| Door state | Show only as telemetry. |
| Presence state | Show only as local non-identifying room state. |
| Alarm / antifurto / protection claim | Blocked. |

Stakeholder-safe wording:

```text
The MVP can describe local presence and door state as telemetry only. It must not be described as tracking, alarm, antifurto, certified access control, intrusion detection, or protection.
```

---

## 9. Related Decisions

| ADR | Status | Effect on this risk | Remaining exposure |
|---|---|---|---|
| [ADR-0003 — MVP Door State Sensor](../../adr/ADR-0003-mvp-door-state-sensor.md) | Accepted | Preserves the telemetry-only boundary and explicitly rejects wire-supervision, tamper, access-control, alarm, antifurto, intrusion-detection and protection interpretations. | The risk remains active. Physical sensing evidence cannot prevent later wording, reporting or product-positioning misinterpretation. |
| [ADR-0005 — MVP Presence Sensor](../../adr/ADR-0005-mvp-presence-sensor.md) | Proposed | Keeps radar detail inside local validation and authorizes only a non-identifying boolean presence state at the product/event boundary. | The sensor decision and residual physical evidence remain pending; later wording or schema changes could still overclaim the capability. |

Neither ADR accepts, closes or resolves R-004. Any residual-risk decision remains with the Project Owner and the Risk Record workflow.

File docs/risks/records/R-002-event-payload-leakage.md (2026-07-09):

# R-002 — Event Payload Leakage

**Status:** Draft  
**Project:** [ITS] [EDGE] HomeEdge AI Platform  
**Jira:** IHAP-16  
**Owner decision:** Pending Project Owner  
**Decision state:** Pending Project Owner  
**Risk type:** Security / Privacy  
**Source of truth:** This GitHub risk record until superseded by a later reviewed change.

<!--
AI_AGENT_METADATA:
  risk_id: R-002
  canonical_path: docs/risks/records/R-002-event-payload-leakage.md
  risk_model: docs/risks/risk-model-baseline.md
  product_boundary: docs/product/product-vision.md
  stakeholder_report_rules: docs/governance/stakeholder-report-data-rules.md
  risk_acceptance_authority: project_owner
  runtime_changes_allowed: false
  adr_created: false
  unvalidated_claim_marker: "[UNVALIDATED]"
-->

---

## 1. Risk Statement

There is a risk that event payloads expose sensitive domestic or operational details because transport, logging, retention, and stakeholder reporting behavior are not yet implemented and tested.

---

## 2. Source Trigger

The MVP direction includes HTTP/JSON event flow from the room/door node toward ingestion. The event shape contains room telemetry and technical metadata, but schema, transport, log handling, and storage are still `[UNVALIDATED]`.

---

## 3. Affected Assets and Trust Boundary

| Area | Detail |
|---|---|
| Asset | Event payload, HTTP/JSON path, ingestion target, logs, stakeholder reports. |
| Trust boundary | Device -> network -> ingestion -> logs/reports. |
| Data involved | Temperature, humidity, presence state, door state, timestamp, device id, room id, firmware version. |
| Stakeholder surface | Summary allowed; raw payloads/logs should be linked only when safe and redacted. |

---

## 4. Scoring

| Field | Value | Rationale |
|---|---|---|
| Likelihood | Medium | Payload and logging behavior are not yet proven; leakage commonly happens through debug output and reports. |
| Impact | High | Door/presence state and metadata can reveal domestic patterns if exposed or correlated. |
| Residual risk | Medium | Current documentation defines boundaries but no runtime redaction/enforcement exists. |
| Treatment proposal | Mitigate | Minimize payload, redact logs/reports, and keep sensitive data out of stakeholder surfaces. |
| Decision state | Pending Project Owner | No residual risk decision has been made. |

---

## 5. Existing Controls

- Raw audio, identity, individual tracking, and behavioral history are OUT OF MVP.
- Stakeholder report data rules block secrets, private addresses, raw audio, identity data, and behavioral history.
- `[UNVALIDATED]` prevents unproven transport/storage claims.

---

## 6. Evidence Gap

Missing evidence:

- implemented event schema;
- transport behavior and logs;
- ingestion validation output;
- redaction checks for logs/screenshots/reports;
- proof that raw sensitive payloads are not copied into Confluence.

---

## 7. Mitigation Proposal

Future implementation and docs should require:

- minimal payload fields;
- no raw audio or identity fields;
- redacted examples in docs and stakeholder reports;
- private network metadata omitted from reports;
- logs reviewed before being shared.

No runtime security claim is made by this mitigation proposal.

---

## 8. Stakeholder Visibility

| Item | Rule |
|---|---|
| Risk summary | Show allowed. |
| Raw payload examples | Link/redact only. |
| Sensitive logs | Redact or block. |
| Transport security claim | `[UNVALIDATED]` until evidence exists. |

Stakeholder-safe wording:

```text
Event payload leakage is tracked as a privacy/security risk. Payload, logging, and redaction behavior remain [UNVALIDATED] until implemented and reviewed.
```

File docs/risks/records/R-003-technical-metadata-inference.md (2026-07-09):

# R-003 — Technical Metadata Inference

**Status:** Draft  
**Project:** [ITS] [EDGE] HomeEdge AI Platform  
**Jira:** IHAP-16  
**Owner decision:** Pending Project Owner  
**Decision state:** Pending Project Owner  
**Risk type:** Privacy / Stakeholder Visibility  
**Source of truth:** This GitHub risk record until superseded by a later reviewed change.

<!--
AI_AGENT_METADATA:
  risk_id: R-003
  canonical_path: docs/risks/records/R-003-technical-metadata-inference.md
  risk_model: docs/risks/risk-model-baseline.md
  product_boundary: docs/product/product-vision.md
  stakeholder_report_rules: docs/governance/stakeholder-report-data-rules.md
  risk_acceptance_authority: project_owner
  runtime_changes_allowed: false
  adr_created: false
  unvalidated_claim_marker: "[UNVALIDATED]"
-->

---

## 1. Risk Statement

There is a risk that technical metadata enables domestic inference because timestamps, device ids, room ids, firmware versions, and network details can reveal patterns when retained, correlated, logged, or exposed.

---

## 2. Source Trigger

The Product Vision allows minimal event direction fields such as timestamp, device id, room id, and firmware version, while IP/network metadata is out of stakeholder view. These fields are useful for engineering evidence but can become privacy-sensitive in combination.

---

## 3. Affected Assets and Trust Boundary

| Area | Detail |
|---|---|
| Asset | Timestamp, device id, room id, firmware version, IP/network metadata. |
| Trust boundary | Runtime telemetry -> logs/storage -> stakeholder reports. |
| Data involved | Technical metadata and domestic context labels. |
| Stakeholder surface | Generic labels only; private topology redacted or omitted. |

---

## 4. Scoring

| Field | Value | Rationale |
|---|---|---|
| Likelihood | Medium | Metadata is likely to be present in events, logs, screenshots, or debugging evidence. |
| Impact | Medium | Metadata may expose domestic layout, activity timing, or device topology. |
| Residual risk | Medium | Current docs define redaction intent, but runtime retention/redaction is not implemented. |
| Treatment proposal | Mitigate | Redact private topology, aggregate where possible, and keep stakeholder views generic. |
| Decision state | Pending Project Owner | No residual risk decision has been made. |

---

## 5. Existing Controls

- Product data boundary marks IP/network metadata as out of stakeholder view.
- Stakeholder report rules require redaction or omission of device/network details when sensitive.
- Raw identity and behavioral data are OUT OF MVP.

---

## 6. Evidence Gap

Missing evidence:

- actual event schema and metadata fields;
- runtime retention behavior;
- log redaction behavior;
- stakeholder report examples after redaction;
- rule for generic room labels versus private domestic labels.

---

## 7. Mitigation Proposal

Future implementation and documentation should:

- use generic room labels in examples;
- avoid private addresses and precise domestic topology;
- omit IP/network metadata from stakeholder material;
- avoid publishing raw logs without redaction review;
- keep metadata retention `[UNVALIDATED]` until implemented and reviewed.

---

## 8. Stakeholder Visibility

| Item | Rule |
|---|---|
| Generic metadata risk summary | Show allowed. |
| Room labels | Generic only. |
| IP/network/private topology | Redact or omit. |
| Retention or correlation claim | `[UNVALIDATED]` until evidence exists. |

Stakeholder-safe wording:

```text
Technical metadata is useful for evidence but may expose domestic context. Private topology and network details are redacted or omitted from stakeholder material.
```

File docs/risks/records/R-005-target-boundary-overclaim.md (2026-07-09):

# R-005 — Target Boundary Overclaim

**Status:** Draft  
**Project:** [ITS] [EDGE] HomeEdge AI Platform  
**Jira:** IHAP-16  
**Owner decision:** Pending Project Owner  
**Decision state:** Pending Project Owner  
**Risk type:** Compliance / Documentation  
**Source of truth:** This GitHub risk record until superseded by a later reviewed change.

<!--
AI_AGENT_METADATA:
  risk_id: R-005
  canonical_path: docs/risks/records/R-005-target-boundary-overclaim.md
  risk_model: docs/risks/risk-model-baseline.md
  product_boundary: docs/product/product-vision.md
  source_of_truth_policy: docs/governance/source-of-truth.md
  risk_acceptance_authority: project_owner
  runtime_changes_allowed: false
  adr_created: false
  unvalidated_claim_marker: "[UNVALIDATED]"
-->

---

## 1. Risk Statement

There is a risk that backend, mobile, cloud, schema, storage, ingestion, registry, read model, or AI target boundaries are presented as implemented runtime without traceable evidence.

---

## 2. Source Trigger

The repository contains target service boundaries for ingestion, device registry, read model, and AI insight. These paths are architectural direction, not proof of implemented services.

---

## 3. Affected Assets and Trust Boundary

| Area | Detail |
|---|---|
| Asset | `services/ingestion/`, `services/device-registry/`, `services/read-model/`, `services/ai-insight/`, mobile/cloud/schema wording. |
| Trust boundary | Repository structure -> implementation maturity claim. |
| Data involved | Not data-specific; maturity and evidence risk. |
| Stakeholder surface | High risk of misunderstanding if wording is loose. |

---

## 4. Scoring

| Field | Value | Rationale |
|---|---|---|
| Likelihood | High | Directory names and architecture diagrams are often mistaken for implemented services. |
| Impact | High | Overclaiming can invalidate stakeholder trust and source-of-truth correctness. |
| Residual risk | High | Runtime evidence is not yet present for target services. |
| Treatment proposal | Mitigate | Preserve TARGET and `[UNVALIDATED]` wording until implementation and test evidence exist. |
| Decision state | Pending Project Owner | No residual risk decision has been made. |

---

## 5. Existing Controls

- README and Product Vision define service directories as target boundaries.
- `[UNVALIDATED]` policy requires unproven runtime claims to remain marked.
- Stakeholder report data rules block target-to-runtime upgrades.

---

## 6. Evidence Gap

Missing evidence:

- service code implementing each boundary;
- tests/build logs;
- runtime logs or API responses;
- schema or event contract evidence;
- deployment or cloud evidence if later claimed.

---

## 7. Mitigation Proposal

Every document and stakeholder surface should use the weakest accurate label:

- `TARGET` for service boundaries;
- `FUTURE` for later capability;
- `[UNVALIDATED]` for unproven runtime behavior;
- `DONE` only with linked evidence.

No placeholder directory should be treated as runtime proof.

---

## 8. Stakeholder Visibility

| Item | Rule |
|---|---|
| Target architecture summary | Show allowed with TARGET / `[UNVALIDATED]`. |
| Runtime service claim | Evidence required. |
| Production-ready wording | Blocked. |
| AI insight runtime claim | `[UNVALIDATED]` until evidence exists. |

Stakeholder-safe wording:

```text
Backend, mobile, cloud, schema, and AI service areas are target boundaries unless implementation and runtime evidence prove otherwise.
```

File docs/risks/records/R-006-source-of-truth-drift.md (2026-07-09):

# R-006 — Source-of-Truth Drift

**Status:** Draft  
**Project:** [ITS] [EDGE] HomeEdge AI Platform  
**Jira:** IHAP-16  
**Owner decision:** Pending Project Owner  
**Decision state:** Pending Project Owner  
**Risk type:** Documentation / Stakeholder Visibility  
**Source of truth:** This GitHub risk record until superseded by a later reviewed change.

<!--
AI_AGENT_METADATA:
  risk_id: R-006
  canonical_path: docs/risks/records/R-006-source-of-truth-drift.md
  risk_model: docs/risks/risk-model-baseline.md
  source_of_truth_policy: docs/governance/source-of-truth.md
  documentation_strategy: docs/governance/documentation-strategy.md
  risk_acceptance_authority: project_owner
  runtime_changes_allowed: false
  adr_created: false
  unvalidated_claim_marker: "[UNVALIDATED]"
-->

---

## 1. Risk Statement

There is a risk that GitHub, Jira, and Confluence drift into parallel truths because each surface contains project information but only some surfaces are authoritative for technical content.

---

## 2. Source Trigger

The project intentionally uses GitHub for technical truth, Jira for work state/evidence, and Confluence for stakeholder reports/navigation. This split is useful, but it creates divergence risk if technical content is copied instead of linked.

---

## 3. Affected Assets and Trust Boundary

| Area | Detail |
|---|---|
| Asset | GitHub docs, Jira issue descriptions/comments, Confluence stakeholder hub/reports. |
| Trust boundary | Technical truth -> tracking summary -> stakeholder summary. |
| Data involved | Scope, risk posture, maturity labels, evidence links, status summaries. |
| Stakeholder surface | High: stakeholders mainly read summaries first. |

---

## 4. Scoring

| Field | Value | Rationale |
|---|---|---|
| Likelihood | Medium | Multiple surfaces are used regularly and can become stale. |
| Impact | High | Divergence can mislead review, invalidate evidence, or weaken claim boundaries. |
| Residual risk | Medium | Existing policy reduces the risk, but every future update must keep links aligned. |
| Treatment proposal | Mitigate | Keep GitHub canonical, Jira evidence-linked, and Confluence summary/link-only. |
| Decision state | Pending Project Owner | No residual risk decision has been made. |

---

## 5. Existing Controls

- `source-of-truth.md` defines surface authority.
- `documentation-strategy.md` defines when to create/update docs.
- Stakeholder reports must summarize and link, not duplicate long-form technical docs.
- Review agents are configured to detect source-of-truth divergence.

---

## 6. Evidence Gap

Missing or future evidence:

- continued link correctness after every PR;
- stakeholder reports aligned after merges;
- Jira comments pointing to current PR/document paths;
- review output for each governance movement.

---

## 7. Mitigation Proposal

Operational mitigation:

- update GitHub when technical truth changes;
- update Jira only for state/evidence links;
- update Confluence only for stakeholder summary/navigation;
- replace copied technical content with links;
- run Source of Truth Guardian before movement toward Stakeholder Review or Done.

---

## 8. Stakeholder Visibility

| Item | Rule |
|---|---|
| Risk summary | Show allowed. |
| Canonical technical docs | Link only. |
| Divergent copied text | Replace with link or update GitHub. |
| Status | Jira remains authoritative. |

Stakeholder-safe wording:

```text
GitHub remains the technical source of truth. Jira tracks work and evidence. Confluence summarizes and links for stakeholder navigation.
```

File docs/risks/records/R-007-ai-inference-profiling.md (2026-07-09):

# R-007 — AI Inference and Profiling

**Status:** Draft  
**Project:** [ITS] [EDGE] HomeEdge AI Platform  
**Jira:** IHAP-16  
**Owner decision:** Pending Project Owner  
**Decision state:** Pending Project Owner  
**Risk type:** AI / Privacy  
**Source of truth:** This GitHub risk record until superseded by a later reviewed change.

<!--
AI_AGENT_METADATA:
  risk_id: R-007
  canonical_path: docs/risks/records/R-007-ai-inference-profiling.md
  risk_model: docs/risks/risk-model-baseline.md
  product_boundary: docs/product/product-vision.md
  risk_acceptance_authority: project_owner
  runtime_changes_allowed: false
  adr_created: false
  unvalidated_claim_marker: "[UNVALIDATED]"
-->

---

## 1. Risk Statement

There is a risk that future AI insight turns room telemetry into behavioral profiling or unsupported interpretation because AI insight is currently a target/future boundary `[UNVALIDATED]`.

---

## 2. Source Trigger

The Product Vision includes an AI-ready insight direction, but AI runtime, evaluation, inference scope, and data minimization are not implemented or validated in Sprint 0.

---

## 3. Affected Assets and Trust Boundary

| Area | Detail |
|---|---|
| Asset | AI insight target, read model target, presence state, door state, timestamps, metadata. |
| Trust boundary | Telemetry/read model -> inferred meaning -> stakeholder or user interpretation. |
| Data involved | Room-level telemetry and technical metadata. |
| Stakeholder surface | AI claims are especially easy to overstate. |

---

## 4. Scoring

| Field | Value | Rationale |
|---|---|---|
| Likelihood | Medium | AI insight is explicitly a future direction, so the risk is likely to return later. |
| Impact | High | Profiling or false interpretation would violate privacy boundaries and stakeholder trust. |
| Residual risk | High | No AI runtime, dataset, evaluation, or guardrail evidence exists. |
| Treatment proposal | Defer | Keep AI insight target/future `[UNVALIDATED]` until a future reviewed task defines evidence and boundaries. |
| Decision state | Pending Project Owner | No residual risk decision has been made. |

---

## 5. Existing Controls

- Person identification, individual tracking, behavioral history, and routine profiling are OUT OF MVP.
- AI insight is marked as TARGET / FUTURE and `[UNVALIDATED]`.
- Stakeholder claim rules prevent runtime AI validation claims without evidence.

---

## 6. Evidence Gap

Missing evidence:

- AI task scope;
- input data minimization policy;
- evaluation method;
- false positive/negative handling;
- privacy review for inference;
- runtime evidence and stakeholder-safe wording.

---

## 7. Mitigation Proposal

Future AI work should require:

- explicit task scope before implementation;
- no identity, individual tracking, or routine profiling;
- documented input/output boundaries;
- evidence before claiming runtime validation;
- stakeholder wording that states target/future status clearly.

No ADR is introduced by this record.

---

## 8. Stakeholder Visibility

| Item | Rule |
|---|---|
| AI risk summary | Show allowed. |
| AI runtime claim | `[UNVALIDATED]` until evidence exists. |
| Behavioral profiling | Blocked for MVP. |
| Safety/security/automation claim | Blocked unless future evidence and Project Owner decision exist. |

Stakeholder-safe wording:

```text
AI insight is a future target [UNVALIDATED]. It must not be described as runtime validated or as behavioral profiling.
```

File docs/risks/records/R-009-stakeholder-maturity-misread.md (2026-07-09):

# R-009 — Stakeholder Maturity Misread

**Status:** Draft  
**Project:** [ITS] [EDGE] HomeEdge AI Platform  
**Jira:** IHAP-16  
**Owner decision:** Pending Project Owner  
**Decision state:** Pending Project Owner  
**Risk type:** Stakeholder Visibility / Claims  
**Source of truth:** This GitHub risk record until superseded by a later reviewed change.

<!--
AI_AGENT_METADATA:
  risk_id: R-009
  canonical_path: docs/risks/records/R-009-stakeholder-maturity-misread.md
  risk_model: docs/risks/risk-model-baseline.md
  stakeholder_transparency: docs/governance/stakeholder-transparency.md
  stakeholder_report_rules: docs/governance/stakeholder-report-data-rules.md
  risk_acceptance_authority: project_owner
  runtime_changes_allowed: false
  adr_created: false
  unvalidated_claim_marker: "[UNVALIDATED]"
-->

---

## 1. Risk Statement

There is a risk that stakeholders interpret Sprint 0 documentation as production-ready, commercial-ready, security-grade, safety-critical, alarm-grade, antifurto, certified, or protective system maturity because summaries can compress technical nuance too much.

---

## 2. Source Trigger

The project intentionally exposes progress through Jira and Confluence for stakeholder visibility. This is useful, but short summaries can accidentally upgrade target, planned, draft, or `[UNVALIDATED]` claims into perceived completed capability.

---

## 3. Affected Assets and Trust Boundary

| Area | Detail |
|---|---|
| Asset | Confluence stakeholder hub, reports, Jira comments, PR summaries, README claims. |
| Trust boundary | Technical evidence -> stakeholder-readable summary. |
| Data involved | Status labels, maturity wording, risk summaries, evidence links. |
| Stakeholder surface | Directly affected. |

---

## 4. Scoring

| Field | Value | Rationale |
|---|---|---|
| Likelihood | Medium | Stakeholders read summaries first, not full GitHub documents. |
| Impact | High | Misread maturity weakens claim governance and can misrepresent project state. |
| Residual risk | High | Risk persists whenever reports or demos are created. |
| Treatment proposal | Mitigate | Use weakest accurate labels and preserve `[UNVALIDATED]` across stakeholder surfaces. |
| Decision state | Pending Project Owner | No residual risk decision has been made. |

---

## 5. Existing Controls

- Stakeholder transparency defines GitHub/Jira/Confluence roles.
- Stakeholder report data rules define allowed, linked, redacted, and blocked content.
- Claim boundaries block forbidden production, commercial, security-grade, safety, alarm, antifurto, access-control, intrusion-detection, and protection wording.

---

## 6. Evidence Gap

Missing or future evidence:

- every Confluence report review after each merge;
- explicit `[UNVALIDATED]` preservation in reports;
- link checks from report to PR/Jira/GitHub;
- reviewer confirmation that stakeholder wording remains safe.

---

## 7. Mitigation Proposal

Every stakeholder surface should:

- use `TARGET`, `FUTURE`, `IN REVIEW`, `STAKEHOLDER REVIEW`, `OUT OF SCOPE`, or `[UNVALIDATED]` precisely;
- avoid “done” unless evidence supports it and Project Owner approves;
- link GitHub/Jira instead of copying long technical content;
- block maturity and protection claims.

---

## 8. Stakeholder Visibility

| Item | Rule |
|---|---|
| Risk summary | Show allowed. |
| Claim maturity | Must use weakest accurate label. |
| Technical depth | Link only. |
| Forbidden maturity/protection wording | Blocked. |

Stakeholder-safe wording:

```text
The project is in Sprint 0 / review state. Target or future capabilities remain [UNVALIDATED] until linked implementation and runtime evidence exists.
```

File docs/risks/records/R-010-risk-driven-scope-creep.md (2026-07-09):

# R-010 — Risk-Driven Scope Creep

**Status:** Draft  
**Project:** [ITS] [EDGE] HomeEdge AI Platform  
**Jira:** IHAP-16  
**Owner decision:** Pending Project Owner  
**Decision state:** Pending Project Owner  
**Risk type:** Documentation / Compliance  
**Source of truth:** This GitHub risk record until superseded by a later reviewed change.

<!--
AI_AGENT_METADATA:
  risk_id: R-010
  canonical_path: docs/risks/records/R-010-risk-driven-scope-creep.md
  risk_model: docs/risks/risk-model-baseline.md
  product_boundary: docs/product/product-vision.md
  documentation_strategy: docs/governance/documentation-strategy.md
  risk_acceptance_authority: project_owner
  runtime_changes_allowed: false
  adr_created: false
  unvalidated_claim_marker: "[UNVALIDATED]"
-->

---

## 1. Risk Statement

There is a risk that risk treatment is used to introduce features outside the MVP because documenting mitigation can look like approving new implementation scope.

---

## 2. Source Trigger

The project uses risk governance early. That is correct, but risk documents can accidentally become a backlog expansion mechanism if mitigation proposals are written as implementation commitments.

---

## 3. Affected Assets and Trust Boundary

| Area | Detail |
|---|---|
| Asset | Risk records, Product Vision, Jira backlog, stakeholder summaries, future implementation tasks. |
| Trust boundary | Risk analysis -> scope decision -> implementation work. |
| Data involved | Scope labels, mitigation wording, decision state, evidence links. |
| Stakeholder surface | Stakeholders may read proposed mitigation as approved roadmap. |

---

## 4. Scoring

| Field | Value | Rationale |
|---|---|---|
| Likelihood | Medium | Mitigation language naturally points to future work unless carefully bounded. |
| Impact | High | Silent scope expansion can undermine MVP discipline and source-of-truth consistency. |
| Residual risk | High | Risk persists for every future risk record and governance task. |
| Treatment proposal | Reject | Reject silent expansion; mitigation may propose future work, but scope changes require Project Owner decision and reviewed source-of-truth update. |
| Decision state | Pending Project Owner | No residual risk decision has been made. |

---

## 5. Existing Controls

- Product Vision protects MVP / FUTURE / OUT OF MVP boundaries.
- Documentation Strategy requires new documents only when they reduce confusion and do not duplicate truth.
- Source-of-truth policy blocks silent MVP expansion.
- Risk Model Baseline requires `Pending Project Owner` unless decision evidence exists.

---

## 6. Evidence Gap

Missing or future evidence:

- explicit Jira task for each future mitigation;
- Project Owner decision for any scope expansion;
- reviewed source-of-truth change when MVP/FUTURE/OUT OF MVP changes;
- stakeholder wording that separates proposal from approved work.

---

## 7. Mitigation Proposal

Risk records should use precise treatment language:

- “Mitigate later” means possible future work, not current scope.
- “Defer” means not active now.
- “Reject” means keep out of MVP/current scope.
- “Candidate accept” means candidate for Project Owner review, not accepted.

Any new implementation must be introduced through its own Jira task and reviewed evidence.

---

## 8. Stakeholder Visibility

| Item | Rule |
|---|---|
| Risk treatment proposal | Show allowed if marked as proposal. |
| Scope expansion | Link to explicit Project Owner decision. |
| Future mitigation | Show as FUTURE / `[UNVALIDATED]`. |
| Implied implementation commitment | Blocked. |

Stakeholder-safe wording:

```text
Risk treatment proposals do not expand MVP scope. New implementation requires a separate task, reviewed evidence, and Project Owner decision.
```

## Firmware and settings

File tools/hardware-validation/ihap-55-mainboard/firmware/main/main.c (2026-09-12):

#include <stdbool.h>
#include <ctype.h>
#include <stdint.h>
#include <stdio.h>
#include <string.h>

#include "driver/gpio.h"
#include "driver/i2c_master.h"
#include "driver/uart.h"
#include "esp_check.h"
#include "esp_err.h"
#include "esp_idf_version.h"
#include "esp_rom_sys.h"
#include "esp_timer.h"
#include "freertos/FreeRTOS.h"
#include "freertos/semphr.h"
#include "freertos/task.h"
#include "health_adc.h"

#define HARNESS_NAME "ihap50-integrated-interconnect-harness"
#define SCHEMA_VERSION "1.2.0"

#define PIN_RADAR_RX GPIO_NUM_0
#define PIN_RADAR_TX_SERVICE GPIO_NUM_1
#define PIN_DOOR GPIO_NUM_3
#define PIN_DHT GPIO_NUM_4
#define PIN_ADC_SPARE GPIO_NUM_5
#define PIN_I2C_SDA GPIO_NUM_6
#define PIN_I2C_SCL GPIO_NUM_7
#define PIN_DIGITAL_SPARE GPIO_NUM_10

#define I2C_TIMEOUT_MS 100
#define I2C_FREQ_HZ 100000
#define OLED_ADDR 0x3C
#define BME280_ADDR 0x76
#define BME280_CHIP_ID_REG 0xD0
#define BME280_CHIP_ID 0x60

#define LD2410_UART UART_NUM_1
#define LD2410_BAUD 256000
#define UART_RX_BUFFER_SIZE 1024
#define FRAME_BUFFER_SIZE 128
#define DHT_BIT_THRESHOLD_US 50

static const uint8_t FRAME_HEADER[] = {0xF4, 0xF3, 0xF2, 0xF1};
static const uint8_t FRAME_FOOTER[] = {0xF8, 0xF7, 0xF6, 0xF5};

static i2c_master_bus_handle_t s_i2c_bus;
static i2c_master_dev_handle_t s_oled;
static i2c_master_dev_handle_t s_bme;
static bool s_bme_present;
static SemaphoreHandle_t s_dht_mutex;
static portMUX_TYPE s_dht_lock = portMUX_INITIALIZER_UNLOCKED;
static portMUX_TYPE s_radar_lock = portMUX_INITIALIZER_UNLOCKED;

typedef struct {
    bool valid;
    float temperature_c;
    float humidity_percent;
    const char *status;
} dht_sample_t;

typedef struct {
    bool has_valid_frame;
    uint8_t target_state;
    int64_t last_valid_frame_us;
    uint32_t valid_frames;
    uint32_t invalid_frames;
    uint32_t uart_bytes;
} radar_state_t;

static radar_state_t s_radar;
static bool s_adc_spare_gpio_ok;
static bool s_digital_spare_gpio_ok;
static bool s_oled_visual_transfer_ok;
static bool s_health_adc_initialized;

static const char *json_bool(bool value)
{
    return value ? "true" : "false";
}

static uint16_t read_le16(const uint8_t *data)
{
    return (uint16_t)data[0] | ((uint16_t)data[1] << 8);
}

static bool wait_while_level(gpio_num_t gpio, int level, uint32_t timeout_us, uint32_t *duration_us)
{
    const int64_t start = esp_timer_get_time();
    while (gpio_get_level(gpio) == level) {
        if ((uint64_t)(esp_timer_get_time() - start) > timeout_us) {
            return false;
        }
    }
    *duration_us = (uint32_t)(esp_timer_get_time() - start);
    return true;
}

static void configure_dht(void)
{
    const gpio_config_t config = {
        .pin_bit_mask = 1ULL << PIN_DHT,
        .mode = GPIO_MODE_INPUT_OUTPUT_OD,
        .pull_up_en = GPIO_PULLUP_DISABLE,
        .pull_down_en = GPIO_PULLDOWN_DISABLE,
        .intr_type = GPIO_INTR_DISABLE,
    };
    ESP_ERROR_CHECK(gpio_config(&config));
    ESP_ERROR_CHECK(gpio_set_level(PIN_DHT, 1));
}

static dht_sample_t read_dht11(void)
{
    dht_sample_t sample = {
        .valid = false,
        .temperature_c = 0.0f,
        .humidity_percent = 0.0f,
        .status = "TIMEOUT",
    };
    uint8_t data[5] = {0};
    uint32_t pulse = 0;

    xSemaphoreTake(s_dht_mutex, portMAX_DELAY);

    gpio_set_direction(PIN_DHT, GPIO_MODE_OUTPUT_OD);
    gpio_set_level(PIN_DHT, 0);
    vTaskDelay(pdMS_TO_TICKS(20));

    portENTER_CRITICAL(&s_dht_lock);
    gpio_set_level(PIN_DHT, 1);
    esp_rom_delay_us(30);
    gpio_set_direction(PIN_DHT, GPIO_MODE_INPUT);

    if (!wait_while_level(PIN_DHT, 1, 120, &pulse) ||
        !wait_while_level(PIN_DHT, 0, 120, &pulse) ||
        !wait_while_level(PIN_DHT, 1, 120, &pulse)) {
        sample.status = "NO_RESPONSE";
        goto done;
    }

    for (int bit = 0; bit < 40; ++bit) {
        uint32_t low_us = 0;
        uint32_t high_us = 0;
        if (!wait_while_level(PIN_DHT, 0, 100, &low_us) ||
            !wait_while_level(PIN_DHT, 1, 120, &high_us)) {
            sample.status = "TIMEOUT";
            goto done;
        }
        data[bit / 8] <<= 1;
        if (high_us > DHT_BIT_THRESHOLD_US) {
            data[bit / 8] |= 1U;
        }
    }

    if ((uint8_t)(data[0] + data[1] + data[2] + data[3]) != data[4]) {
        sample.status = "CHECKSUM";
        goto done;
    }

    sample.humidity_percent = (float)data[0] + ((float)data[1] / 10.0f);
    sample.temperature_c = (float)data[2] + ((float)(data[3] & 0x7FU) / 10.0f);
    if ((data[3] & 0x80U) != 0U) {
        sample.temperature_c = -sample.temperature_c;
    }
    sample.valid = sample.humidity_percent >= 0.0f && sample.humidity_percent <= 100.0f;
    sample.status = sample.valid ? "OK" : "OUT_OF_RANGE";

done:
    gpio_set_direction(PIN_DHT, GPIO_MODE_INPUT);
    portEXIT_CRITICAL(&s_dht_lock);
    xSemaphoreGive(s_dht_mutex);
    return sample;
}

static esp_err_t add_i2c_device(uint8_t address, i2c_master_dev_handle_t *device)
{
    i2c_device_config_t cfg = {
        .dev_addr_length = I2C_ADDR_BIT_LEN_7,
        .device_address = address,
        .scl_speed_hz = I2C_FREQ_HZ,
    };
    return i2c_master_bus_add_device(s_i2c_bus, &cfg, device);
}

static esp_err_t configure_i2c(void)
{
    i2c_master_bus_config_t cfg = {
        .i2c_port = I2C_NUM_0,
        .sda_io_num = PIN_I2C_SDA,
        .scl_io_num = PIN_I2C_SCL,
        .clk_source = I2C_CLK_SRC_DEFAULT,
        .glitch_ignore_cnt = 7,
        .flags.enable_internal_pullup = false,
    };
    ESP_RETURN_ON_ERROR(i2c_new_master_bus(&cfg, &s_i2c_bus), "IHAP50", "I2C bus init");

    const esp_err_t oled_probe = i2c_master_probe(s_i2c_bus, OLED_ADDR, I2C_TIMEOUT_MS);
    const esp_err_t bme_probe = i2c_master_probe(s_i2c_bus, BME280_ADDR, I2C_TIMEOUT_MS);
    s_bme_present = bme_probe == ESP_OK;

    printf("{\"record_type\":\"i2c_probe\",\"oled_0x3c\":%s,\"bme280_0x76\":%s}\n",
           oled_probe == ESP_OK ? "true" : "false",
           s_bme_present ? "true" : "false");
    fflush(stdout);

    ESP_RETURN_ON_ERROR(oled_probe, "IHAP50", "OLED 0x3C not found");
    ESP_RETURN_ON_ERROR(add_i2c_device(OLED_ADDR, &s_oled), "IHAP50", "OLED add");
    if (s_bme_present) {
        ESP_RETURN_ON_ERROR(add_i2c_device(BME280_ADDR, &s_bme), "IHAP50", "BME add");
    }
    return ESP_OK;
}

static esp_err_t oled_init(void)
{
    const uint8_t sequence[] = {
        0x00,
        0xAE, 0xD5, 0x80, 0xA8, 0x3F, 0xD3, 0x00, 0x40,
        0x8D, 0x14, 0x20, 0x00, 0xA1, 0xC8, 0xDA, 0x12,
        0x81, 0x7F, 0xD9, 0xF1, 0xDB, 0x40, 0xA4, 0xA6, 0xAF,
    };
    return i2c_master_transmit(s_oled, sequence, sizeof(sequence), I2C_TIMEOUT_MS);
}

static bool oled_visual_gate(void)
{
    const uint8_t all_on[] = {0x00, 0xA5};
    const uint8_t ram_display[] = {0x00, 0xA4};
    if (i2c_master_transmit(s_oled, all_on, sizeof(all_on), I2C_TIMEOUT_MS) != ESP_OK) {
        return false;
    }
    vTaskDelay(pdMS_TO_TICKS(1000));
    return i2c_master_transmit(s_oled, ram_display, sizeof(ram_display), I2C_TIMEOUT_MS) == ESP_OK;
}

static bool oled_ping(void)
{
    const uint8_t command[] = {0x00, 0xA4};
    return i2c_master_transmit(s_oled, command, sizeof(command), I2C_TIMEOUT_MS) == ESP_OK;
}

static bool bme280_read_chip_id(uint8_t *chip_id)
{
    if (!s_bme_present || s_bme == NULL) {
        return false;
    }
    const uint8_t reg = BME280_CHIP_ID_REG;
    return i2c_master_transmit_receive(s_bme, &reg, 1, chip_id, 1, I2C_TIMEOUT_MS) == ESP_OK;
}

static void configure_door(void)
{
    const gpio_config_t cfg = {
        .pin_bit_mask = 1ULL << PIN_DOOR,
        .mode = GPIO_MODE_INPUT,
        .pull_up_en = GPIO_PULLUP_DISABLE,
        .pull_down_en = GPIO_PULLDOWN_DISABLE,
        .intr_type = GPIO_INTR_DISABLE,
    };
    ESP_ERROR_CHECK(gpio_config(&cfg));
}

static bool spare_pin_pull_test(gpio_num_t pin)
{
    gpio_config_t cfg = {
        .pin_bit_mask = 1ULL << pin,
        .mode = GPIO_MODE_INPUT,
        .pull_up_en = GPIO_PULLUP_ENABLE,
        .pull_down_en = GPIO_PULLDOWN_DISABLE,
        .intr_type = GPIO_INTR_DISABLE,
    };
    if (gpio_config(&cfg) != ESP_OK) {
        return false;
    }
    vTaskDelay(pdMS_TO_TICKS(5));
    const int high = gpio_get_level(pin);

    cfg.pull_up_en = GPIO_PULLUP_DISABLE;
    cfg.pull_down_en = GPIO_PULLDOWN_ENABLE;
    if (gpio_config(&cfg) != ESP_OK) {
        return false;
    }
    vTaskDelay(pdMS_TO_TICKS(5));
    const int low = gpio_get_level(pin);

    cfg.pull_up_en = GPIO_PULLUP_DISABLE;
    cfg.pull_down_en = GPIO_PULLDOWN_DISABLE;
    (void)gpio_config(&cfg);
    return high == 1 && low == 0;
}

static void register_invalid_frame(void)
{
    portENTER_CRITICAL(&s_radar_lock);
    s_radar.invalid_frames++;
    portEXIT_CRITICAL(&s_radar_lock);
}

static bool parse_radar_frame(const uint8_t *frame, size_t len)
{
    if (len < 23 || memcmp(frame, FRAME_HEADER, sizeof(FRAME_HEADER)) != 0) {
        return false;
    }
    const uint16_t payload_len = read_le16(&frame[4]);
    if ((size_t)payload_len + 10U != len || payload_len < 13U) {
        return false;
    }
    if (memcmp(&frame[len - 4U], FRAME_FOOTER, sizeof(FRAME_FOOTER)) != 0) {
        return false;
    }
    const uint8_t *payload = &frame[6];
    if (payload[0] != 0x02 || payload[1] != 0xAA || payload[11] != 0x55 || payload[12] != 0x00) {
        return false;
    }

    portENTER_CRITICAL(&s_radar_lock);
    s_radar.has_valid_frame = true;
    s_radar.target_state = payload[2];
    s_radar.last_valid_frame_us = esp_timer_get_time();
    s_radar.valid_frames++;
    portEXIT_CRITICAL(&s_radar_lock);
    return true;
}

static void consume_radar(uint8_t *buffer, size_t *used)
{
    while (*used >= 4U) {
        size_t header = 0;
        while (header + 4U <= *used && memcmp(&buffer[header], FRAME_HEADER, 4) != 0) {
            ++header;
        }
        if (header > 0) {
            memmove(buffer, &buffer[header], *used - header);
            *used -= header;
        }
        if (*used < 6U) {
            return;
        }

        const size_t total = (size_t)read_le16(&buffer[4]) + 10U;
        if (total < 10U || total > FRAME_BUFFER_SIZE) {
            register_invalid_frame();
            memmove(buffer, &buffer[1], *used - 1U);
            --(*used);
            continue;
        }
        if (*used < total) {
            return;
        }
        if (!parse_radar_frame(buffer, total)) {
            register_invalid_frame();
        }
        memmove(buffer, &buffer[total], *used - total);
        *used -= total;
    }
}

static void radar_task(void *arg)
{
    (void)arg;
    uint8_t read_buf[128];
    uint8_t frame_buf[FRAME_BUFFER_SIZE];
    size_t used = 0;

    while (true) {
        const int n = uart_read_bytes(LD2410_UART, read_buf, sizeof(read_buf), pdMS_TO_TICKS(100));
        if (n <= 0) {
            continue;
        }

        portENTER_CRITICAL(&s_radar_lock);
        s_radar.uart_bytes += (uint32_t)n;
        portEXIT_CRITICAL(&s_radar_lock);

        for (int i = 0; i < n; ++i) {
            if (used == sizeof(frame_buf)) {
                register_invalid_frame();
                memmove(frame_buf, &frame_buf[1], sizeof(frame_buf) - 1U);
                --used;
            }
            frame_buf[used++] = read_buf[i];
            consume_radar(frame_buf, &used);
        }
    }
}

static esp_err_t configure_radar_uart(void)
{
    const uart_config_t cfg = {
        .baud_rate = LD2410_BAUD,
        .data_bits = UART_DATA_8_BITS,
        .parity = UART_PARITY_DISABLE,
        .stop_bits = UART_STOP_BITS_1,
        .flow_ctrl = UART_HW_FLOWCTRL_DISABLE,
        .source_clk = UART_SCLK_DEFAULT,
    };
    ESP_RETURN_ON_ERROR(uart_driver_install(LD2410_UART, UART_RX_BUFFER_SIZE, 0, 0, NULL, 0), "IHAP50", "UART install");
    ESP_RETURN_ON_ERROR(uart_param_config(LD2410_UART, &cfg), "IHAP50", "UART config");

    /* Receive-only by design. GPIO1 is reserved in the interconnect contract but
       is not attached to the UART peripheral in this validation harness. */
    return uart_set_pin(LD2410_UART, UART_PIN_NO_CHANGE, PIN_RADAR_RX, UART_PIN_NO_CHANGE, UART_PIN_NO_CHANGE);
}

static radar_state_t radar_snapshot(void)
{
    radar_state_t snapshot;
    portENTER_CRITICAL(&s_radar_lock);
    snapshot = s_radar;
    portEXIT_CRITICAL(&s_radar_lock);
    return snapshot;
}

static void skip_json_space(const char **cursor)
{
    while (isspace((unsigned char)**cursor)) {
        ++(*cursor);
    }
}

static bool consume_json_char(const char **cursor, char expected)
{
    skip_json_space(cursor);
    if (**cursor != expected) {
        return false;
    }
    ++(*cursor);
    return true;
}

static bool consume_json_literal(const char **cursor, const char *literal)
{
    skip_json_space(cursor);
    const size_t length = strlen(literal);
    if (strncmp(*cursor, literal, length) != 0) {
        return false;
    }
    *cursor += length;
    return true;
}

/* Intentionally accepts only the three-field validation protocol in its
   documented order. Unsupported JSON forms fail closed. */
static bool parse_board_request(const char *request, bool *standard)
{
    const char *cursor = request;
    if (!consume_json_char(&cursor, '{') ||
        !consume_json_literal(&cursor, "\"cmd\"") ||
        !consume_json_char(&cursor, ':') ||
        !consume_json_literal(&cursor, "\"self_test\"") ||
        !consume_json_char(&cursor, ',') ||
        !consume_json_literal(&cursor, "\"profile\"") ||
        !consume_json_char(&cursor, ':')) {
        return false;
    }
    if (consume_json_literal(&cursor, "\"standard\"")) {
        *standard = true;
    } else if (consume_json_literal(&cursor, "\"precision\"")) {
        *standard = false;
    } else {
        return false;
    }
    if (!consume_json_char(&cursor, ',') ||
        !consume_json_literal(&cursor, "\"schema\"") ||
        !consume_json_char(&cursor, ':') ||
        !consume_json_literal(&cursor, "\"ihap55.board.v1\"") ||
        !consume_json_char(&cursor, '}')) {
        return false;
    }
    skip_json_space(&cursor);
    return *cursor == '\0';
}

/* This is a validation-only command endpoint. A malformed or unknown request
   never produces a successful board_self_test record. */
static void board_command_task(void *arg)
{
    (void)arg;
    char request[192];
    while (true) {
        if (fgets(request, sizeof(request), stdin) == NULL) {
            clearerr(stdin);
            vTaskDelay(pdMS_TO_TICKS(100));
            continue;
        }
        bool standard = false;
        if (!parse_board_request(request, &standard)) {
            printf("{\"record_type\":\"board_command_error\",\"reason\":\"invalid_request\"}\n");
            fflush(stdout);
            continue;
        }

        ihap55_rail_health_t rails = {0};
        const bool adc_read_ok = s_health_adc_initialized &&
                                 ihap55_health_adc_read(&rails) == ESP_OK;
        const bool rails_ok = adc_read_ok &&
                              rails.vbus_in_v >= 4.75f && rails.vbus_in_v <= 5.25f &&
                              rails.batt_v >= 2.5f && rails.batt_v <= 4.25f &&
                              rails.sys5v_v >= 4.75f && rails.sys5v_v <= 5.25f &&
                              rails.sys3v3_v >= 3.0f && rails.sys3v3_v <= 3.6f;
        const bool oled_ok = s_oled_visual_transfer_ok && oled_ping();
        uint8_t chip_id = 0;
        const bool bme_ok = bme280_read_chip_id(&chip_id) && chip_id == BME280_CHIP_ID;
        const dht_sample_t dht = standard ? read_dht11() : (dht_sample_t){0};
        const radar_state_t radar = radar_snapshot();
        const int64_t age_us = esp_timer_get_time() - radar.last_valid_frame_us;
        const bool radar_ok = radar.has_valid_frame && age_us >= 0 && age_us <= 2000000;
        const int door = gpio_get_level(PIN_DOOR);
        const bool door_ok = door == 0 || door == 1;
        const bool pass = rails_ok && oled_ok && radar_ok && door_ok &&
                          s_adc_spare_gpio_ok && s_digital_spare_gpio_ok &&
                          (standard ? dht.valid : bme_ok);

        printf("{\"record_type\":\"board_self_test\",\"schema\":\"ihap55.board.v1\","
               "\"profile\":\"%s\",\"pass\":%s,"
               "\"checks\":{\"usb_console\":true,\"health_adc\":%s,\"oled\":%s,"
               "\"radar\":%s,\"door_level_valid\":%s,\"spare_adc\":%s,"
               "\"spare_digital\":%s,\"service_tx_disabled\":true,"
               "\"dht11\":%s,\"bme280\":%s,\"bme280_chip_id\":%u},"
               "\"rails\":{\"VBUS_IN\":%.3f,\"BATT\":%.3f,\"SYS_5V\":%.3f,\"SYS_3V3\":%.3f}}\n",
               standard ? "standard" : "precision", json_bool(pass), json_bool(rails_ok),
               json_bool(oled_ok), json_bool(radar_ok), json_bool(door_ok),
               json_bool(s_adc_spare_gpio_ok), json_bool(s_digital_spare_gpio_ok),
               json_bool(dht.valid), json_bool(bme_ok), (unsigned)chip_id,
               rails.vbus_in_v, rails.batt_v, rails.sys5v_v, rails.sys3v3_v);
        fflush(stdout);
    }
}

void app_main(void)
{
    memset(&s_radar, 0, sizeof(s_radar));
    s_dht_mutex = xSemaphoreCreateMutex();
    configASSERT(s_dht_mutex != NULL);
    configure_door();
    configure_dht();

    s_adc_spare_gpio_ok = spare_pin_pull_test(PIN_ADC_SPARE);
    s_digital_spare_gpio_ok = spare_pin_pull_test(PIN_DIGITAL_SPARE);

    ESP_ERROR_CHECK(configure_i2c());
    s_health_adc_initialized = ihap55_health_adc_init(s_i2c_bus) == ESP_OK;
    ESP_ERROR_CHECK(oled_init());
    s_oled_visual_transfer_ok = oled_visual_gate();
    ESP_ERROR_CHECK(configure_radar_uart());
    xTaskCreate(radar_task, "ihap50_radar", 4096, NULL, 10, NULL);
    xTaskCreate(board_command_task, "ihap55_command", 4096, NULL, 5, NULL);

    const char *detected_profile = s_bme_present ? "precision" : "standard";
    printf(
        "{\"record_type\":\"boot\",\"schema_version\":\"%s\",\"firmware\":\"%s\",\"idf_version\":\"%s\","
        "\"detected_profile\":\"%s\","
        "\"pins\":{\"radar_rx\":0,\"radar_tx_service\":1,\"door\":3,\"dht\":4,\"adc_spare\":5,\"i2c_sda\":6,\"i2c_scl\":7,\"digital_spare\":10},"
        "\"radar_tx_service_configured\":false,\"adc_spare_pull_test\":%s,\"digital_spare_pull_test\":%s,"
        "\"bme280_present\":%s,\"oled_visual_transfer_ok\":%s}\n",
        SCHEMA_VERSION,
        HARNESS_NAME,
        esp_get_idf_version(),
        detected_profile,
        s_adc_spare_gpio_ok ? "true" : "false",
        s_digital_spare_gpio_ok ? "true" : "false",
        s_bme_present ? "true" : "false",
        s_oled_visual_transfer_ok ? "true" : "false");
    fflush(stdout);

    uint32_t seq = 0;
    while (true) {
        uint8_t chip_id = 0;
        const bool bme_read_ok = bme280_read_chip_id(&chip_id);
        const bool bme_ok = bme_read_ok && chip_id == BME280_CHIP_ID;
        const bool oled_ok = oled_ping();
        const dht_sample_t dht = read_dht11();
        const radar_state_t radar = radar_snapshot();
        const int64_t now_us = esp_timer_get_time();
        const int64_t radar_age_ms = radar.has_valid_frame ? (now_us - radar.last_valid_frame_us) / 1000 : -1;
        const bool radar_fresh = radar.has_valid_frame && radar_age_ms >= 0 && radar_age_ms <= 2000;
        const int door = gpio_get_level(PIN_DOOR);

        printf(
            "{\"record_type\":\"integrated_sample\",\"seq\":%lu,"
            "\"profile\":\"%s\",\"oled_ok\":%s,"
            "\"bme280_present\":%s,\"bme280_ok\":%s,\"bme280_chip_id\":\"0x%02X\","
            "\"dht11_ok\":%s,\"dht11_status\":\"%s\",\"temperature_c\":%.1f,\"humidity_percent\":%.1f,"
            "\"radar_fresh\":%s,\"radar_target_state\":%u,\"radar_valid_frames\":%lu,"
            "\"radar_invalid_frames\":%lu,\"radar_uart_bytes\":%lu,\"door_raw\":%d}\n",
            (unsigned long)seq,
            detected_profile,
            oled_ok ? "true" : "false",
            s_bme_present ? "true" : "false",
            bme_ok ? "true" : "false",
            chip_id,
            dht.valid ? "true" : "false",
            dht.status,
            dht.temperature_c,
            dht.humidity_percent,
            radar_fresh ? "true" : "false",
            radar.target_state,
            (unsigned long)radar.valid_frames,
            (unsigned long)radar.invalid_frames,
            (unsigned long)radar.uart_bytes,
            door);
        fflush(stdout);
        ++seq;
        vTaskDelay(pdMS_TO_TICKS(5000));
    }
}

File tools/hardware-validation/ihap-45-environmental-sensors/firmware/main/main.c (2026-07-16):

#include <inttypes.h>
#include <math.h>
#include <stdbool.h>
#include <stdint.h>
#include <stdio.h>
#include <string.h>

#include "driver/gpio.h"
#include "driver/i2c_master.h"
#include "esp_check.h"
#include "esp_err.h"
#include "esp_idf_version.h"
#include "esp_system.h"
#include "esp_rom_sys.h"
#include "esp_timer.h"
#include "freertos/FreeRTOS.h"
#include "freertos/task.h"

#define HARNESS_SCHEMA_VERSION "1.0.0"
#define HARNESS_FIRMWARE_NAME "ihap-45-environmental-sensor-harness"

#define DHT11_SENSOR_ID "DHT11-OWNED-01"
#define DHT22_SENSOR_ID "DHT22-OWNED-01"
#define BME280_SENSOR_ID "BME280-OWNED-01"

#define BME280_ADDRESS_LOW 0x76
#define BME280_ADDRESS_HIGH 0x77
#define BME280_REG_CHIP_ID 0xD0
#define BME280_REG_RESET 0xE0
#define BME280_REG_CTRL_HUM 0xF2
#define BME280_REG_CTRL_MEAS 0xF4
#define BME280_REG_CONFIG 0xF5
#define BME280_REG_TEMP_MSB 0xFA
#define BME280_REG_CALIB00 0x88
#define BME280_REG_CALIB26 0xE1
#define BME280_CHIP_ID 0x60
#define BMP280_CHIP_ID 0x58
#define BMP280_SAMPLE_CHIP_ID_1 0x56
#define BMP280_SAMPLE_CHIP_ID_2 0x57
#define BME280_RESET_COMMAND 0xB6

#define BME280_OSRS_H_X1 0x01
#define BME280_OSRS_T_X1 (0x01 << 5)
#define BME280_OSRS_P_SKIPPED (0x00 << 2)
#define BME280_MODE_FORCED 0x01

#define I2C_TIMEOUT_MS 100
#define DHT_BIT_THRESHOLD_US 50

#ifndef CONFIG_IHAP45_DHT11_GPIO
#define CONFIG_IHAP45_DHT11_GPIO 3
#endif
#ifndef CONFIG_IHAP45_DHT22_GPIO
#define CONFIG_IHAP45_DHT22_GPIO 4
#endif
#ifndef CONFIG_IHAP45_I2C_SDA_GPIO
#define CONFIG_IHAP45_I2C_SDA_GPIO 5
#endif
#ifndef CONFIG_IHAP45_I2C_SCL_GPIO
#define CONFIG_IHAP45_I2C_SCL_GPIO 6
#endif
#ifndef CONFIG_IHAP45_SAMPLE_INTERVAL_MS
#define CONFIG_IHAP45_SAMPLE_INTERVAL_MS 5000
#endif
#ifndef CONFIG_IHAP45_I2C_FREQUENCY_HZ
#define CONFIG_IHAP45_I2C_FREQUENCY_HZ 100000
#endif

#if CONFIG_IHAP45_DHT11_GPIO == 2 || CONFIG_IHAP45_DHT22_GPIO == 2 || \
    CONFIG_IHAP45_I2C_SDA_GPIO == 2 || CONFIG_IHAP45_I2C_SCL_GPIO == 2
#error "GPIO2 is excluded from the IHAP-45 validation harness by ADR-0001."
#endif

#if CONFIG_IHAP45_DHT11_GPIO == CONFIG_IHAP45_DHT22_GPIO || \
    CONFIG_IHAP45_DHT11_GPIO == CONFIG_IHAP45_I2C_SDA_GPIO || \
    CONFIG_IHAP45_DHT11_GPIO == CONFIG_IHAP45_I2C_SCL_GPIO || \
    CONFIG_IHAP45_DHT22_GPIO == CONFIG_IHAP45_I2C_SDA_GPIO || \
    CONFIG_IHAP45_DHT22_GPIO == CONFIG_IHAP45_I2C_SCL_GPIO || \
    CONFIG_IHAP45_I2C_SDA_GPIO == CONFIG_IHAP45_I2C_SCL_GPIO
#error "Every IHAP-45 signal must use a distinct GPIO."
#endif

typedef enum {
    DHT_KIND_11 = 11,
    DHT_KIND_22 = 22,
} dht_kind_t;

typedef enum {
    SAMPLE_OK = 0,
    SAMPLE_ERR_NO_RESPONSE,
    SAMPLE_ERR_TIMEOUT,
    SAMPLE_ERR_CHECKSUM,
    SAMPLE_ERR_RANGE,
    SAMPLE_ERR_I2C,
    SAMPLE_ERR_UNSUPPORTED_DEVICE,
    SAMPLE_ERR_NOT_INITIALIZED,
} sample_status_t;

typedef struct {
    bool valid;
    double temperature_c;
    double humidity_percent;
    sample_status_t status;
    int64_t read_duration_us;
} sensor_sample_t;

typedef struct {
    uint16_t dig_t1;
    int16_t dig_t2;
    int16_t dig_t3;
    uint8_t dig_h1;
    int16_t dig_h2;
    uint8_t dig_h3;
    int16_t dig_h4;
    int16_t dig_h5;
    int8_t dig_h6;
} bme280_calibration_t;

typedef struct {
    i2c_master_bus_handle_t bus;
    i2c_master_dev_handle_t device;
    uint8_t address;
    uint8_t chip_id;
    bool initialized;
    bme280_calibration_t calibration;
} bme280_context_t;

static portMUX_TYPE s_dht_lock = portMUX_INITIALIZER_UNLOCKED;
static bme280_context_t s_bme280 = {0};

static const char *status_code(sample_status_t status)
{
    switch (status) {
        case SAMPLE_OK:
            return "OK";
        case SAMPLE_ERR_NO_RESPONSE:
            return "NO_RESPONSE";
        case SAMPLE_ERR_TIMEOUT:
            return "TIMEOUT";
        case SAMPLE_ERR_CHECKSUM:
            return "CHECKSUM";
        case SAMPLE_ERR_RANGE:
            return "OUT_OF_RANGE";
        case SAMPLE_ERR_I2C:
            return "I2C_ERROR";
        case SAMPLE_ERR_UNSUPPORTED_DEVICE:
            return "UNSUPPORTED_DEVICE";
        case SAMPLE_ERR_NOT_INITIALIZED:
            return "NOT_INITIALIZED";
        default:
            return "UNKNOWN";
    }
}

static const char *detected_device_name(uint8_t chip_id)
{
    switch (chip_id) {
        case BME280_CHIP_ID:
            return "BME280";
        case BMP280_CHIP_ID:
            return "BMP280";
        case BMP280_SAMPLE_CHIP_ID_1:
            return "BMP280_SAMPLE_0x56";
        case BMP280_SAMPLE_CHIP_ID_2:
            return "BMP280_SAMPLE_0x57";
        default:
            return "UNKNOWN";
    }
}

static int16_t sign_extend_12(uint16_t value)
{
    if ((value & 0x0800U) != 0U) {
        value |= 0xF000U;
    }
    return (int16_t)value;
}

static uint16_t read_u16_le(const uint8_t *buffer)
{
    return (uint16_t)buffer[0] | ((uint16_t)buffer[1] << 8);
}

static int16_t read_s16_le(const uint8_t *buffer)
{
    return (int16_t)read_u16_le(buffer);
}

static bool wait_while_level(gpio_num_t gpio, int level, uint32_t timeout_us, uint32_t *duration_us)
{
    const int64_t start = esp_timer_get_time();
    while (gpio_get_level(gpio) == level) {
        if ((uint64_t)(esp_timer_get_time() - start) > timeout_us) {
            return false;
        }
    }
    *duration_us = (uint32_t)(esp_timer_get_time() - start);
    return true;
}

static void dht_prepare_gpio(gpio_num_t gpio)
{
    gpio_config_t config = {
        .pin_bit_mask = 1ULL << gpio,
        .mode = GPIO_MODE_INPUT_OUTPUT_OD,
#if CONFIG_IHAP45_DHT_INTERNAL_PULLUPS
        .pull_up_en = GPIO_PULLUP_ENABLE,
#else
        .pull_up_en = GPIO_PULLUP_DISABLE,
#endif
        .pull_down_en = GPIO_PULLDOWN_DISABLE,
        .intr_type = GPIO_INTR_DISABLE,
    };
    ESP_ERROR_CHECK(gpio_config(&config));
    ESP_ERROR_CHECK(gpio_set_level(gpio, 1));
}
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

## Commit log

2026-07-09 IHAP-33: Add docs landing page
2026-07-09 IHAP-33: Link docs landing from root README
2026-07-09 IHAP-33: Register docs landing canonical path
2026-07-09 IHAP-33: Align documentation strategy with docs landing
2026-07-09 IHAP-33: Reduce docs landing visible duplication
2026-07-09 IHAP-33: Avoid repeating docs landing in README prose
2026-07-09 IHAP-16: Register risk docs in docs landing page
2026-07-09 IHAP-16: Add R-001 device identity risk
2026-07-09 IHAP-16: Route risk records in docs landing page
2026-07-09 IHAP-16: Preserve ADR gate for window sensors
2026-07-11 IHAP-39: Define risk treatment lifecycle and traceability
2026-07-11 IHAP-39: Add risk and treatment traceability to ADR template
2026-07-14 docs(ihap-44): accept ESP32-C3 strategy and record physical evidence
2026-07-15 docs(ihap-44): tighten display handoff wording
2026-07-15 docs(ihap-44): add ESP32-C3 SuperMini photographic evidence
2026-07-15 IHAP-45: add environmental sensor validation protocol
2026-07-15 IHAP-45: add parallel ESP32-C3 sensor harness
2026-07-15 IHAP-45: update CMakeLists to use PRIV_REQUIRES for dependencies and fix I2C port definition
    [main.c]
2026-07-15 fix(ihap-45): survive ESP32-C3 USB reset during capture
    [ihap45_resilient.py]
2026-07-15 IHAP-46: Add ESP32-C3 harness defaults
2026-07-15 IHAP-46: Add configurable laboratory pin mapping
2026-07-15 IHAP-46: Add reset-tolerant capture and report CLI
    [ihap46.py]
2026-07-15 test(ihap-45): add staged brownout stability diagnostic
    [ihap45_stability.py]
2026-07-15 docs(ihap-45): add staged brownout isolation procedure
2026-07-16 IHAP-47: prepare door sensor decision and physical validation
2026-07-16 fix(ihap-45): normalize evidence from first captured boot
    [ihap45_normalize_run.py]
2026-07-16 docs(ihap-45): record environmental sensor profile decision
2026-07-16 docs(ihap-45): finalize PR traceability
2026-07-16 fix(ihap-45): enforce strict gate before evidence publication
    [ihap45_publish.py]
2026-07-17 IHAP-46: Make reset preflight tolerant of USB re-enumeration
    [guided_run.py]
2026-08-07 IHAP-46: Update .gitignore to include gz files and modify CMakeLists.txt to require additional drivers
2026-08-07 test(ihap-52): verify storage integrity and throttle flags
2026-08-07 docs(ihap-52): tighten thermal evidence boundary
2026-08-07 IHAP-53 fix validation harness includes
    [main.c]
2026-08-07 IHAP-53 wire USB guard into harness
2026-08-31 IHAP-53: document validated evidence publication flow
2026-08-31 IHAP-53: tighten display run claim boundary
2026-08-31 IHAP-48: keep docs landing page navigational
2026-08-31 IHAP-47: Renumber door sensor ADR to ADR-0003
2026-08-31 IHAP-47: Rebase ADR index onto current main
2026-09-01 IHAP-47: harden guided failure-mode prompts
    [guided_run.py]
2026-09-01 IHAP-47: Include guided failure modes in generated report
    [build_report.py]
2026-09-01 IHAP-47: Accept door state sensor ADR
2026-09-01 IHAP-47: Reconcile accepted evidence and BOM provenance
2026-09-01 IHAP-46: complete presence sensor decision evidence
2026-09-02 Revert "IHAP-46: Add presence sensor validation harness"
    [guided_run.py, guided_run_strict.py, ihap46.py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]
2026-09-02 IHAP-46: document acceptance reconciliation traceability
2026-09-05 IHAP-52: record first physical preflight and corrected storage/power profile
2026-09-05 IHAP-52: keep PR summary current after evidence review
2026-09-05 IHAP-52: split power and thermal throttle diagnostics
2026-09-05 IHAP-52: test split throttle diagnostics
2026-09-05 IHAP-52: document thermal rerun and decoded throttle workflow
2026-09-05 IHAP-52: record passing fan-cooled physical validation
2026-09-07 IHAP-49: Edge power subsystem decision (#34)
    Accept ADR-0007 and freeze the edge power contract: regulated 5 V USB-C normal source, LG INR18650-MJ1 backup-only cell, and custom modular core PCB direction. MP2636GR-P remains the preferred charge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
2026-09-10 IHAP-56: remediate IHAP-49 post-merge power findings (#35)
    Complete IHAP-56 remediation and reconcile the power contract, validation matrix, and risk traceability under explicit Project Owner merge authorization.
2026-09-10 IHAP-50: Add interconnect and prototype assembly specification
2026-09-10 IHAP-50: Correct ADC-capable GPIO allocation
2026-09-11 IHAP-50: pin validation firmware target to ESP32-C3
2026-09-11 IHAP-50: align ESP32-C3 USB console with accepted harnesses
2026-09-11 IHAP-50: prevent stale serial samples from contaminating physical phases
    [ihap50_run.py]
2026-09-11 IHAP-55: Initialize KiCad mainboard workspace
2026-09-12 IHAP-55: Add machine-readable schematic contract
2026-09-12 IHAP-55: Define revision-A electrical schematic
2026-09-12 IHAP-55: Add deterministic power-envelope simulator
2026-09-12 IHAP-55: Add schematic contract regression check
2026-09-12 IHAP-55: Add USB physical-board self-test client
2026-09-12 IHAP-55: Add board-test host dependency
2026-09-12 IHAP-55: Test physical-board result evaluator
2026-09-12 IHAP-55: Define programmatic board self-test protocol
2026-09-12 IHAP-55: Add TLA2024 rail-health driver interface
2026-09-12 IHAP-55: Implement TLA2024 rail-health measurements
2026-09-12 IHAP-55: Compile rail-health driver into firmware baseline
2026-09-12 IHAP-55: Add automated contract and KiCad validation CI
2026-09-12 IHAP-55: Integrate board-health USB self-test firmware
2026-09-13 IHAP-55: Validate revision-A power arithmetic and flag ADC startup hazard
2026-09-13 IHAP-55: Enforce KiCad 10.0.6 in CI EDA gates
2026-09-13 IHAP-55: Record firmware build and physical-board protocol boundary
2026-09-13 IHAP-55: Review ADC isolation and battery current-limit candidates
2026-09-20 IHAP-55: Record current software gate reruns
2026-09-21 IHAP-55 add native KiCad contract baseline
    [homeedge-edge-mainboard.kicad_pcb, homeedge-edge-mainboard.kicad_sch]
